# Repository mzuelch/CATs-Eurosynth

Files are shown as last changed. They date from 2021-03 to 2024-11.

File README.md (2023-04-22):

<h1>CAT's Eurosynth</h1>
<p>This is my repository for my analog synth eurorack compatible modules. Files given via the "Gerber" directories are actual production data used for my own prototyping. Bugs are to be expected. Corrections for finished boards marked as "working" are done in KiCAD only.</p>
<p>Please read the "Known Issues" section given in this repository as "ReadMe.md" whenever appropriate.</p>
<h1>License</h1>
<p>Code (AVR projects): GPL3.0.</p>
<p>Code (STM32F projects): MIT license.</p>
<p>Hardware: CC BY-NC-SA 4.0</p>

<p>unless specified otherwise.</p>
<h2>Custom Libraries</h2>
<p>Most of the schematics and layouts use custom libraries since some of the stock libries are either buggy or unsuited for my designs. The libraries can be found <a href="https://github.com/mzuelch/CATs-Eurosynth/tree/main/Libraries">here</a>.</p>
<p>I am about to remodel all the KiCAD Files to use environment variables:</p>
<table>
	<tr>
		<th>Variable</th>
		<th>points to</th>		
	</tr>
	<tr>
		<td>KI_CUSTOM_MOD</td>
		<td>Footprint Data (where all the .pretty stuff is hidden)</td>		
	</tr>
	<tr>
		<td>KI_CUSTOM_3DMOD</td>
		<td>3D Model Data (where all the .3dshapes stuff is hidden)</td>		
	</tr>
	<tr>
		<td>KI_CUSTOM_SYMBOLS</td>
		<td>Symbol Data (where all the .lib stuff is hidden)</td>		
	</tr>
</table>
<p>Layout specific data (mainly front panel stuff) are stored in the corresponding folders. Most of the Links are absolute atm. I will change them as soon as the particular layout is modified.</p>
<p>Proper Aliases and other informations are given in these ReadMe's:</p> 
<ul>
	<li><a href="https://github.com/mzuelch/CATs-Eurosynth/blob/main/Libraries/Symbols/ReadMe.md">Symbols</a></li>
	<li><a href="https://github.com/mzuelch/CATs-Eurosynth/blob/main/Libraries/Footprints/ReadMe.md">Footprints</a></li>
	<li><a href="https://github.com/mzuelch/CATs-Eurosynth/blob/main/Libraries/3D%20Shapes/ReadMe.md">3D Shapes</a></li>
</ul>
<h1>Published Designs</p>
<h2>Standard Line</h2>
<p>Collection of modules with no regard to size. These designs are based on either my own ideas and mistakes or published in so many places I can't figure out the original source.</p>
<h3><a href="https://github.com/mzuelch/CATs-Eurosynth/tree/main/Modules/Standard%20Line/Power%20Module">Power Module (THT, Working)</a></h3>
<h3><a href="https://github.com/mzuelch/CATs-Eurosynth/tree/main/Modules/Standard%20Line/Atari%20Punk%20Console">Atari Punk Console (THT, Working)</a></h3>
<h3><s>Baby8 Sequencer (THT, Rework)</s></h3>
<h3><a href="https://github.com/mzuelch/CATs-Eurosynth/tree/main/Modules/Standard%20Line/4Ch%20Mixer">4Ch Mixer (SMT, Working)</a></h3>
<h3><a href="https://github.com/mzuelch/CATs-Eurosynth/tree/main/Modules/Standard%20Line/Clock%20Divider">Clock Divider (THT, Working)</a></h3>
<h3><a href="https://github.com/mzuelch/CATs-Eurosynth/tree/main/Modules/Standard%20Line/Abakus">Abakus (SMT/THT, Working)</a></h3>
<h3><s>Manual Gate (THT, Rework)</s></h3>
<h3><a href="https://github.com/mzuelch/CATs-Eurosynth/tree/main/Modules/Standard%20Line/Envelope%20Follower">Envelope Follower (THT, WIP)</a></h3>
<h3><a href="https://github.com/mzuelch/CATs-Eurosynth/tree/main/Modules/Standard%20Line/Vactrol%20VCF">Vactrol VCF (THT, Working)</a></h3>
<h3><a href="https://github.com/mzuelch/CATs-Eurosynth/tree/main/Modules/Standard%20Line/Classic%20ADSR">Classic ADSR (SMT, Working)</a></h3>
<h2>Slim Line</h2>
<p>Slim Modules to cope with the ever increasing lamentations from my bandmates and wife. Also these designs are based on either my own ideas and mistakes or published in so many places I can't figure out the original source.</p>
<h3><a href="https://github.com/mzuelch/CATs-Eurosynth/tree/main/Modules/Slim%20Line/Attenuator">Single Attenuator (THT, Working)</a></h3>
<h3><a href="https://github.com/mzuelch/CATs-Eurosynth/tree/main/Modules/Slim%20Line/Buffered%20Multiple">Buffered Multiple (THT, Working)</a></h3>
<h3><a href="https://github.com/mzuelch/CATs-Eurosynth/tree/main/Modules/Slim%20Line/Buffered%20Multiple%20SMD">Buffered Multiple SMD (SMT, Working)</a></h3>
<h3><a href="https://github.com/mzuelch/CATs-Eurosynth/tree/main/Modules/Slim%20Line/Sample%26Hold">Dual Sample&Hold (THT, Working)</a></h3>
<h3><a href="https://github.com/mzuelch/CATs-Eurosynth/tree/main/Modules/Slim%20Line/Sample%26Hold%20SMD">Dual Sample&Hold SMD (SMT/THT, WIP)</a></h3>
<h3><a href="https://github.com/mzuelch/CATs-Eurosynth/tree/main/Modules/Slim%20Line/Precision%20Adder">Precision Adder (SMT, Working)</a></h3>
<h3><a href="https://github.com/mzuelch/CATs-Eurosynth/tree/main/Modules/Slim%20Line/Rectifier%20SMD">Rectifier SMD(SMT, Working)</a></h3>
<h3><a href="https://github.com/mzuelch/CATs-Eurosynth/tree/main/Modules/Slim%20Line/VCA">VCA (THT, Working)</a></h3>
<h3><a href="https://github.com/mzuelch/CATs-Eurosynth/tree/main/Modules/Slim%20Line/Clock%20Divider">Clock Divider (SMT, Working)</a></h3>
<h3><a href="https://github.com/mzuelch/CATs-Eurosynth/tree/main/Modules/Slim%20Line/Voltage%20Controlled%20Switch">Voltage Controlled Switch (SMT, Working)</a></h3>

<h2>Purely Mechanical</h2>
<p>Some purely mechanical projects - blinds, cases,...</p>
<h3><a href="https://github.com/mzuelch/CATs-Eurosynth/tree/main/Modules/Mechanicals/Blinds/1TE">1TE Blind Panel</a></h3>
<h3><a href="https://github.com/mzuelch/CATs-Eurosynth/tree/main/Modules/Mechanicals/Blinds/3TE">3TE Blind Panel</a></h3>
<h3><a href="https://github.com/mzuelch/CATs-Eurosynth/tree/main/Modules/Mechanicals/Cases">Cases</a></h3>

<h2>MFOS Clones</h2>
<p>The basic electronic design was made by <a href="http://musicfromouterspace.com/">Music From Outer Space</a>.
The remodelling in KiCAD, slight adaptation, PCB layout and frontpanel designs are based on my own faults</p>
<p>RIP Ray Wilson</p>
<h3>Dual VCA #2 (THT, Working)</h3>
<ul>
	<li><a href="http://musicfromouterspace.com/analogsynth_new/OLDIESBUTGOODIES/VCA/dualvca-2.html">Original Build Documentation</a></li>
</ul>
<h3><a href="https://github.com/mzuelch/CATs-Eurosynth/tree/main/Modules/MFOS/Noise%20Cornucopia">Noise Cornucopia (THT, Working)</a></h3>
<ul>
	<li><a href="http://musicfromouterspace.com/analogsynth_new/NOISECORNREV01/NOISECORNREV01.php">Original Build Documentation</a></li>
</ul>
<h3><a href="https://github.com/mzuelch/CATs-Eurosynth/tree/main/Modules/MFOS/Eight%20Stage%20Phase%20Shifter">Eight Stage Phase Shifter (SMT, Working)</a></h3>
<ul>
	<li><a href="http://musicfromouterspace.com/analogsynth_new/PHASESHIFTER2007/PHASESHIFTER2007.php">Original Build Documentation</a></li>
</ul>

<h2>YuSynth Clones</h2>
<p>The basic electronic design was made by <a href="https://yusynth.net">YuSynth</a>.
The remodelling in KiCAD, slight adaptation (especially changes to +/-12V), PCB layout and frontpanel designs are based on my own faults.</p>
<h3><a href="https://github.com/mzuelch/CATs-Eurosynth/tree/main/Modules/YuSynth/Improved%20Steiner%20VCF">Improved Steiner VCF (SMT, Working)</a></h3>
<ul>
	<li><a href="http://yusynth.net/Modular/EN/STEINERVCF/index-v2.html">Original Build Documentation</a></li>
</ul>
<h3><a href="https://github.com/mzuelch/CATs-Eurosynth/tree/main/Modules/YuSynth/Balanced%20Modulator"><b>Single</b> balanced Modulator (THT/SMT, WIP)</a></h3>
<ul>
	<li><a href="http://yusynth.net/Modular/EN/RINGMOD/index.html">Original Build Documentation</a></li>
</ul>

<h2>Haraldswerk</h2>
<p>The basic electronic design was made by <a href="https://www.haraldswerk.de/">Haraldswerk</a>.
The remodelling in KiCAD, slight adaptation (especially to Eurorack format), PCB layout and frontpanel designs are based on my own faults.</p>
<h3><a href="https://github.com/mzuelch/CATs-Eurosynth/tree/main/Modules/Haraldswerk/NGF-E%20LFO/">Next Generation Formant LFO (THT, Working)</a></h3>
<ul>
	<li><a href="https://www.haraldswerk.de/NGF_E/NGF_E_LFO/NGF_E_LFO.html">Original Build Documentation</a></li>
</ul>

<h2>Ken Stone / Cat Girl Synth</h2>
<p>The basic electronic design was made by <a href="https://sdiy.info/wiki/CatGirl_Synth">Ken Stone aka Cat Girl Synth</a>.
The remodelling in KiCAD, slight adaptation (especially changes to +/-12V), PCB layout and frontpanel designs are based on my own faults</p>
<h3><a href="https://github.com/mzuelch/CATs-Eurosynth/tree/main/Modules/CGS/Analog%20Switch%20Matrix">Analog Switch Matrix (THT/SMT, Working)</a></h3>
<ul>
	<li><a href="https://sdiy.info/wiki/CGS_analog_switch_matrix">Original Build Documentation</a></li>
</ul>

<h2>HAGIWO</h2>
<p>The basic electronic design was made by <a href="https://www.youtube.com/channel/UCxErrnnVNEAAXPZvQFwobQw">HAGIWO</a>.
The remodelling in KiCAD, slight adaptation in hard- and software, PCB layout and frontpanel designs are based on my own faults.</p>
<p>The schematics are Public Domain, firmware is Open Source unless otherwise specified.</p>
<p>This part of the repository is made public with permission from HAGIWO itself. I really appreciate it.</p>
<h3><a href="https://github.com/mzuelch/CATs-Eurosynth/tree/main/Modules/HAGIWO/6Ch%20Trigger%20Sequencer">6Ch Trigger Sequencer (SMT, Working)</a></h3>
<ul>
	<li>
		<strong>6Ch Gate Sequencer</strong>
		<br><a href="https://www.youtube.com/watch?v=YszdC8YdFl0&t">YouTube</a>
		<br><a href="https://note.com/solder_state/n/n17c69afd484d">Original Build Documentation</a>
	</li>
	<li>
		<strong>6Ch Euclidian Rythm Sequencer</strong>
		<br><a href="https://www.youtube.com/watch?v=lkoBfiq6KPY">YouTube</a>
		<br><a href="https://note.com/solder_state/n/n433b32ea6dbc">Original Build Documentation</a>
	</lt>
</ul>
<h3><a href="https://github.com/mzuelch/CATs-Eurosynth/tree/main/Modules/HAGIWO/Ringfolder">Ringfolder (SMT, Working)</a></h3>
<ul>
	<li>
		<strong>Ring Modulator & Wavefolder</strong>
		<br><a href="https://www.youtube.com/watch?v=gYwEPNSfJLE">YouTube</a>
		<br><a href="https://note.com/solder_state/n/n9d138d74b39d">Original Build Documentation</a>
	</li>
</ul>
<h3><a href="https://github.com/mzuelch/CATs-Eurosynth/tree/main/Modules/HAGIWO/Multiout">Multiout (SMT, Working)</a></h3>
<ul>
	<li>
		<strong>Sequencer Roland SH-101 type</strong>
		<br><a href="https://www.youtube.com/watch?v=--qb_QYZrTk&t">YouTube</a>
		<br><a href="https://note.com/solder_state/n/n80f4baf81226">Original Build Documentation</a>
	</li>
	<li>
		<strong>Dual quantizer and Envelope generator</strong>
		<br><a href="https://www.youtube.com/watch?v=6FJpljEYZq4">YouTube</a>
		<br><a href="https://note.com/solder_state/n/nb8b9a2f212a2">Original Build Documentation</a>
	</li>
</ul>
<h3><a href="https://github.com/mzuelch/CATs-Eurosynth/tree/main/Modules/HAGIWO/Display">Display (SMT, Working)</a></h3>
<ul>
	<li>
		<strong>Oscilloscope & Spectrum analyzer</strong>
		<br><a href="https://www.youtube.com/watch?v=yAes5pS3ZTo">YouTube</a>
		<br><a href="https://note.com/solder_state/n/n6b4cc8d1c6b9">Original Build Documentation</a>
	</li>
</ul>
<h3><a href="https://github.com/mzuelch/CATs-Eurosynth/tree/main/Modules/HAGIWO/Arduino%20VCO">Arduino VCO (SMT, Working)</a></h3>
<ul>
	<li>
		<strong>Additive VCO</strong>
		<br><a href="https://www.youtube.com/watch?v=wjWOJ-h5w5w">YouTube</a>
		<br><a href="https://note.com/solder_state/n/n30b3a8737b1e">Original Build Documentation</a>
	</li>
	<li>
		<strong>Chord VCO</strong>
		<br><a href="https://www.youtube.com/watch?v=Ikhd3OmoN40">YouTube</a>
		<br><a href="https://note.com/solder_state/n/n681d2e07e324">Original Build Documentation</a>
	</li>
	<li>
		<strong>FM VCO</strong>
		<br><a href="https://www.youtube.com/watch?v=NZKacfP9aNI">YouTube</a>
		<br><a href="https://note.com/solder_state/n/n88317851a4c7">Original Build Documentation</a>
	</li>
</ul>
<h3><a href="https://github.com/mzuelch/CATs-Eurosynth/tree/main/Modules/HAGIWO/4Ch%20Sample%20Player">4Ch Sample Player (SMT, Working)</a></h3>
<ul>
	<li>
		<strong>TR-808/909 sample play , 4CH wav trigger</strong>
		<br><a href="https://www.youtube.com/watch?v=7Vcwk8KYZM8&t">YouTube</a>
		<br><a href="https://note.com/solder_state/n/n0209d16d0d08">Original Build Documentation</a>
	</li>
</ul>
<h3><a href="https://github.com/mzuelch/CATs-Eurosynth/tree/main/Modules/HAGIWO/Sync%20LFO">Sync LFO (SMT, Working)</a></h3>
<ul>
	<li>
		<strong>Clock Sync LFO</strong>
		<br><a href="https://www.youtube.com/watch?v=m64jyVz2w3M">YouTube</a>
		<br><a href="https://note.com/solder_state/n/n4c600f2431c3">Original Build Documentation</a>
	</li>
</ul>

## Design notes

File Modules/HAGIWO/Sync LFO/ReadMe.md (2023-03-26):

<h2>Revision History</h2>
<table>
	<tr>
		<th>Revision</th>
		<th>Changes</th>
	</tr>
	<tr>
		<td>012202</td>
		<td>Initial Release</td>
	</tr>
	<tr>
		<td>022303</td>
		<td>Arduino Nano rotated by 180deg. No changes in pot or jack position. PCB layout adapted accordingly.<br>Make space for a shrouded IDC header. Mark the correct header and USB connector orientation on the backside.</td>
	</tr>
</table>

<h2>Modulove Appendix</h2>
This is a PCB version of the awesome HAGIWO Clock SYNC LFO.
It was published on Github by [mzuelch](https://github.com/mzuelch/ "mzuelch") and we (modulove) put together the design & kits in our lab.

HAGIWO Sync LFO Kit

The module is a Arduino-based LFO and can be clocked / synced via the trigger input and offers internal modulation to create complex waveforms.
It can be modified / reprogrammed easily with the Arduino IDE.

HAGIWO Sync LFO module

It offers six waveforms and the following hardware features:

- Panel Design by [bkrsmdesign](https://www.instagram.com/bkrsmdesign/ "Sasha Kruse")
- Knob1: Amplifier control. Set the output voltage
- Knob2: Phase control. Set the phase from 0-360°
- Knob3: Waveform control. Select the waveform type.
- Knob4: Internal modulation, creating complex waveforms.
- CLK in: Clock IN.
- OUTPUT Voltage 0/+10V
- Skiff friendly & 6P
- 50 mA draw

<h1>Changes mzuelch made to the original design</h1>
<ul>
	<li>PWM -> Analog Conversion by active Steiner LPF (fg=500Hz) instead of passive RC network</li>
	<li>Unipolar output changed from 0/+5V to 0/+10V</li>
	<li>Additional bipolar output +/-10V</li>
	<li>Additional inverted bipolar output +/-10V</li>
</ul>

DIY Info:

Building the Module is simple and suited for beginners. The Kit comes with SMD parts already soldered.

Assembly Instructions / Video [here](https://youtube.com/playlist?list=PL9-2_fDMIm5cuEoAXl6-avylgxBkOdHC9 "HAGIWO module build video")

More Info:

- [HAGIWO original Articles](https://note.com/solder_state/n/n4c600f2431c3 "HAGIWO Sync LFO module article").

- [HAGIWO Display Video](https://www.youtube.com/watch?v=m64jyVz2w3M "HAGIWO Clock Sync LFO module Youtube Video").

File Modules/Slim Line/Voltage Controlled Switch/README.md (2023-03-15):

<h1>Slimline Voltage Controlled Switch</h1>
<table>
	<tr valign="top">
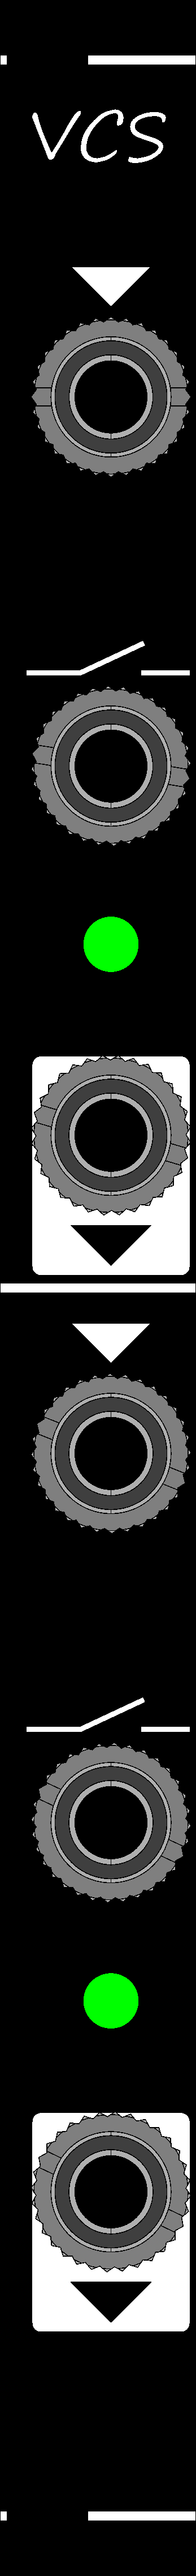
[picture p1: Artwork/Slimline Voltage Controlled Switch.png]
		<td></td>
		<td>
			<p>
				Slimline Voltage Controlled Switch
			</p>
		</td>
	</tr>
</table>

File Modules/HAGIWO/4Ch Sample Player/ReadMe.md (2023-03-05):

<h1>Changes to the original design</h1>
<p>Changed Output stage to provide a eurorack compatible output swing +/-5V</p>
<h1>Changes to the original firmware</h1>
<p>Too many to talk about. Finally got rid of the OLED noise issues by shutting it completely down while in playback mode.</p>

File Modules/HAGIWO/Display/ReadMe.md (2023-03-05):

This is a PCB version of the awesome HAGIWO OLED Display.
It was published on Github by [mzuelch](https://github.com/mzuelch/ "mzuelch") and we (modulove) put together the design & kits in our lab.

HAGIWO OLED Display Kit

The module is a Arduino-based simple Arduino-based OLED DIsplay that has 4 modes.
The microcontroller can be reprogrammed easily with the Arduino IDE and a USB cable.

HAGIWO OLED Display module

Features:

- Pnel Design by modulove
- 128*64 pixel 0.96inch OLED display
- Rotary encoder with PUSH Button
- GAIN attenuator
- AC/DC switching toggle switch
- TRIG IN
- INPUT (normalized)
- OUTPUT
- Voltage 5Vp-p
- LFO / EG mode

1 shot mode
spectrum analyzer mode
whatever you will come up with mode

<h1>Changes mzuelch made to the original HAGIWO design</h1>
<ul>
	<li>R4 (47k) and R5 (10k) were swapped in the original design.</li>
</ul>

DIY Info:

Building the Module is simple and suited for beginners. The Kit comes with all SMD parts already soldered.

Assembly Instructions / Video [here](https://youtube.com/playlist?list=PL9-2_fDMIm5cuEoAXl6-avylgxBkOdHC9 "HAGIWO module build video")

More Info:

- [HAGIWO original Articles](https://note.com/solder_state/n/n6b4cc8d1c6b9 "HAGIWO Display module article").

- [HAGIWO Display Video](https://www.youtube.com/watch?v=yAes5pS3ZTo "HAGIWO Display module Youtube Video").

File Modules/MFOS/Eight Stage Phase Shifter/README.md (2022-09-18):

<h1>MFOS Eight Stage Phase Shifter</h1>
<table>
	<tr valign="top">
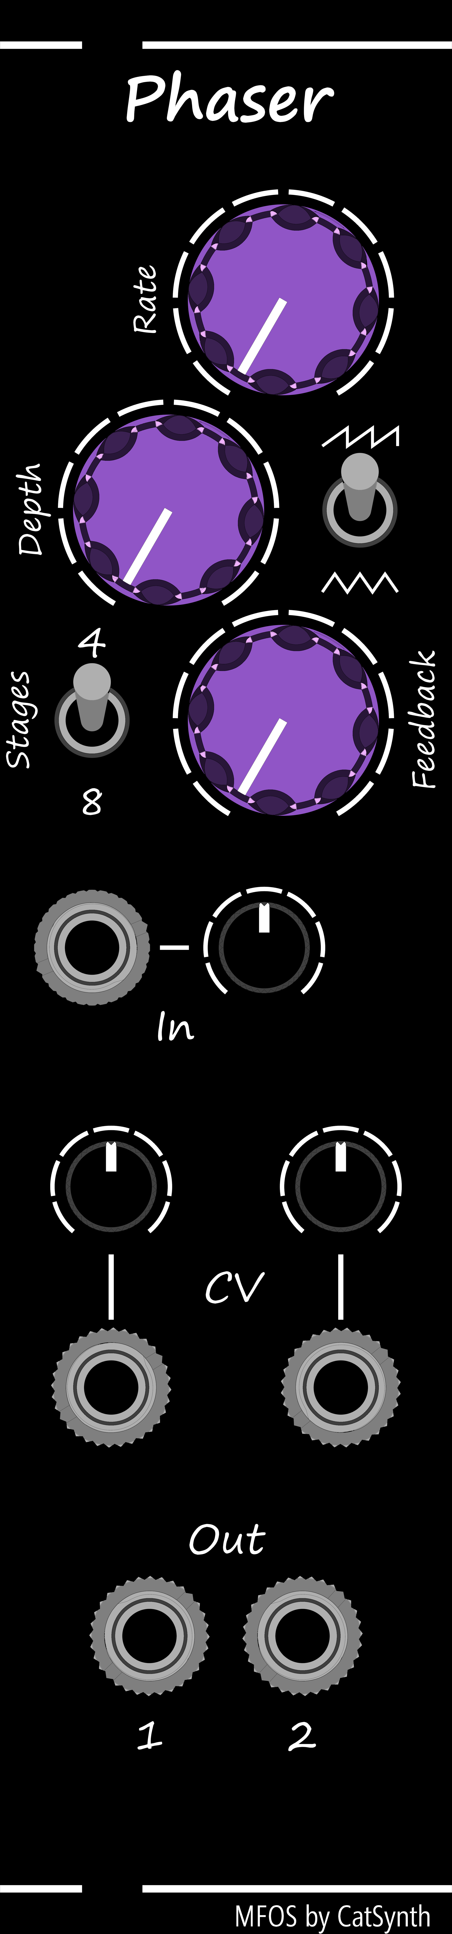
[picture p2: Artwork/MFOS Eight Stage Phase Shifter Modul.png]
		<td></td>
		<td>
			
		</td>
	</tr>
</table>

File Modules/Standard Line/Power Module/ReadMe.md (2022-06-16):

<h1>Power Module</h1>
<table>
	<tr valign="top">
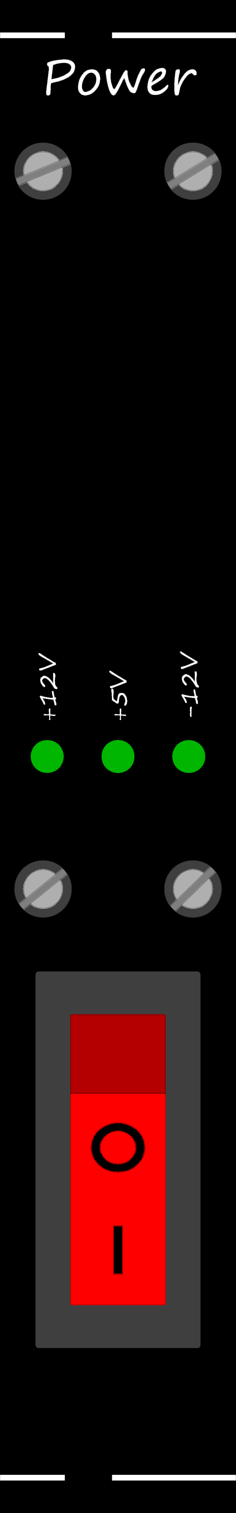
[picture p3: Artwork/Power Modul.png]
		<td></td>
		<td>
			<p>
				Simple Power Input module to provide a mains switch as well as some rudimentary voltage indication.
			</p>
			<p>
				All connections to the <b>fused</b> power connector as well as the PSU (especially Meanwell RT-65B) are <b>isolated</b> 6.3mm (FastOn 250) tab connectors.
			</p>
		</td>
	</tr>
</table>

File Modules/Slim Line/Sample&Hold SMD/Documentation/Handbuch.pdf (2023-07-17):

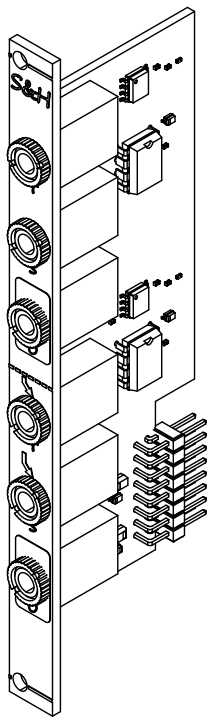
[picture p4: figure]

# CATs EuroSynth

Dr. Michael Zülch
cats.synth@gmx.de

# Dual Sample&Hold

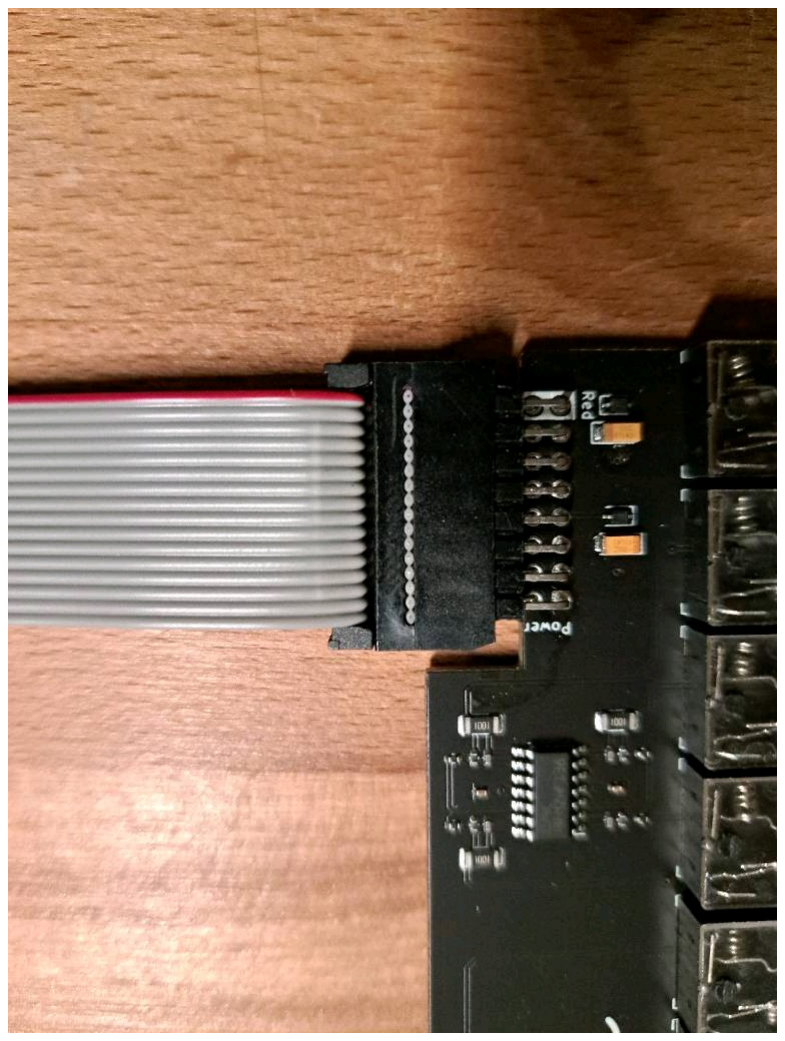
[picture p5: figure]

2 HP Width

39mm w/o Connector

+12V: 15mA

-12V: 15mA

Maximum Depth

Current Draw

## cations fi Technical Speci

## Function

This module contains two identical sample & hold circuits, designed to produce 'staircase' voltages. The signal present at the sample input (S) is sampled at a rate set by the signal at the trigger input (T), and held at that voltage at the S&H output (O). The exact shape of the staircase depends on the sort of waveform at the sample input: NOISE or RANDOM signals produce random patterns; an LFO produces rising or falling

staircase patterns.

The sample input as well as the trigger input of the lower circuit is normalized to the according inputs of

the upper circuit.

## Installation

When installing or removing a module from your case always turn the power to the case and ffo disconnect the power cable. Failure to do so may result in serious injury

or equipment damage.

Ensure the 10-pin connector on the power cable is connected correctly to the module before proceeding.

The red stripe on the cable must line up with the -12V pins on the module’s power connector. The pins are indicated with the label

-12V, a white stripe next to the connector, the words “red”, or

some combination of those

indicators.

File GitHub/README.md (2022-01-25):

<h1>PNG as IMG</h1>
<table border="0" cellpadding="0">
	<tr>
		<td>Atari Punk Console</td>
		<td>4Ch Mixer Front</td>
	</tr>
</table>

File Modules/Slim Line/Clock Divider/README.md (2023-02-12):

<h1>Slimline Clock Divider</h1>
<table>
	<tr valign="top">
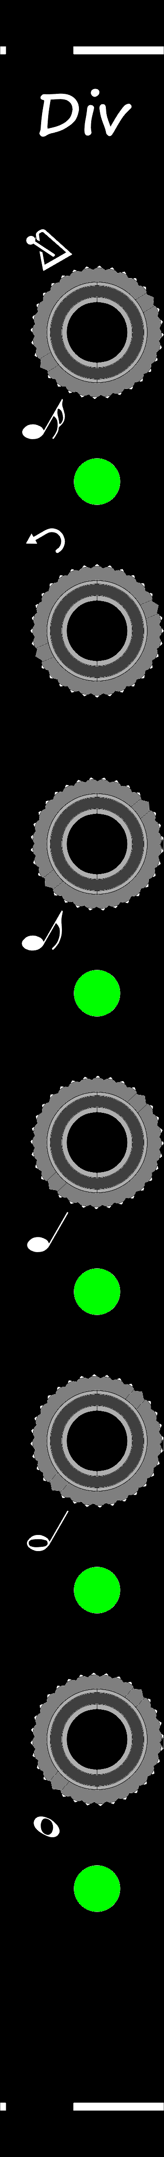
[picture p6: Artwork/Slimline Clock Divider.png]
		<td></td>
		<td>
			<p>
				Slimline Clock Divider
			</p>
		</td>
	</tr>
</table>

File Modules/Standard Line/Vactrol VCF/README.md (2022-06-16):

<h1>Vactrol VCF</h1>
<table>
	<tr valign="top">
		<td></td>
		<td>
		</td>
	</tr>
</table>

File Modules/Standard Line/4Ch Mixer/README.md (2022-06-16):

<h1>4Ch Mixer</h1>
<table>
	<tr valign="top">
		<td></td>
		<td>
			
		</td>
	</tr>
</table>

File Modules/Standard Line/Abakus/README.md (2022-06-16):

<h1>Abakus</h1>
<table>
	<tr valign="top">
		<td></td>
		<td>
			
		</td>
	</tr>
</table>

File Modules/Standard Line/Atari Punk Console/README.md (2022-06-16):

<h1>Atari Punk Console</h1>
<table>
	<tr valign="top">
		<td></td>
		<td>
			
		</td>
	</tr>
</table>

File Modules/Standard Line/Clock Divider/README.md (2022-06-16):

<h1>Clock Divider</h1>
<table>
	<tr valign="top">
		<td></td>
		<td>
			
		</td>
	</tr>
</table>

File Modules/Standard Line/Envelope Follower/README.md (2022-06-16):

<h1>Envelope Follower</h1>
<table>
	<tr valign="top">
		<td></td>
		<td>
			
		</td>
	</tr>
</table>

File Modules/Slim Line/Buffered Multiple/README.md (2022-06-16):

<h1>Slimline Buffered Multiple</h1>
<table>
	<tr valign="top">
		<td></td>
		<td>
			<p>
				Simple Buffered Multiple 2x 1->3 or 1x 1->6
			</p>
		</td>
	</tr>
</table>

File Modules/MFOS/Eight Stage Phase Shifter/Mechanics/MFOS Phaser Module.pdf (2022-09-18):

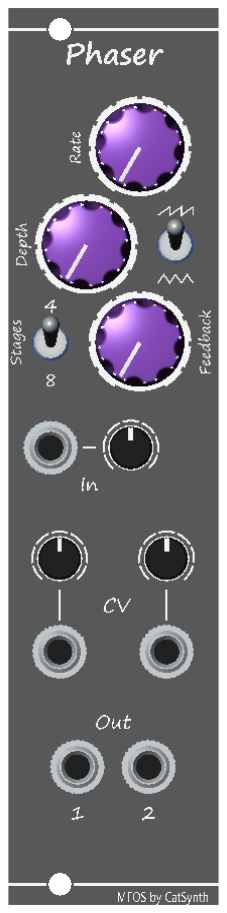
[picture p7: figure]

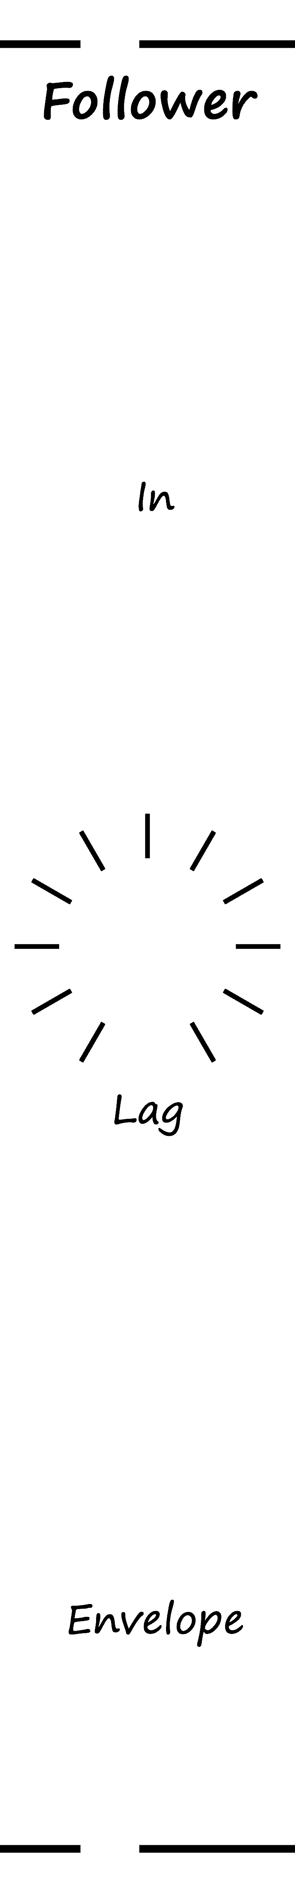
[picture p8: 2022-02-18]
Modules/Standard Line/Envelope Follower/Electronics/Front/Envelope Follower Front.png

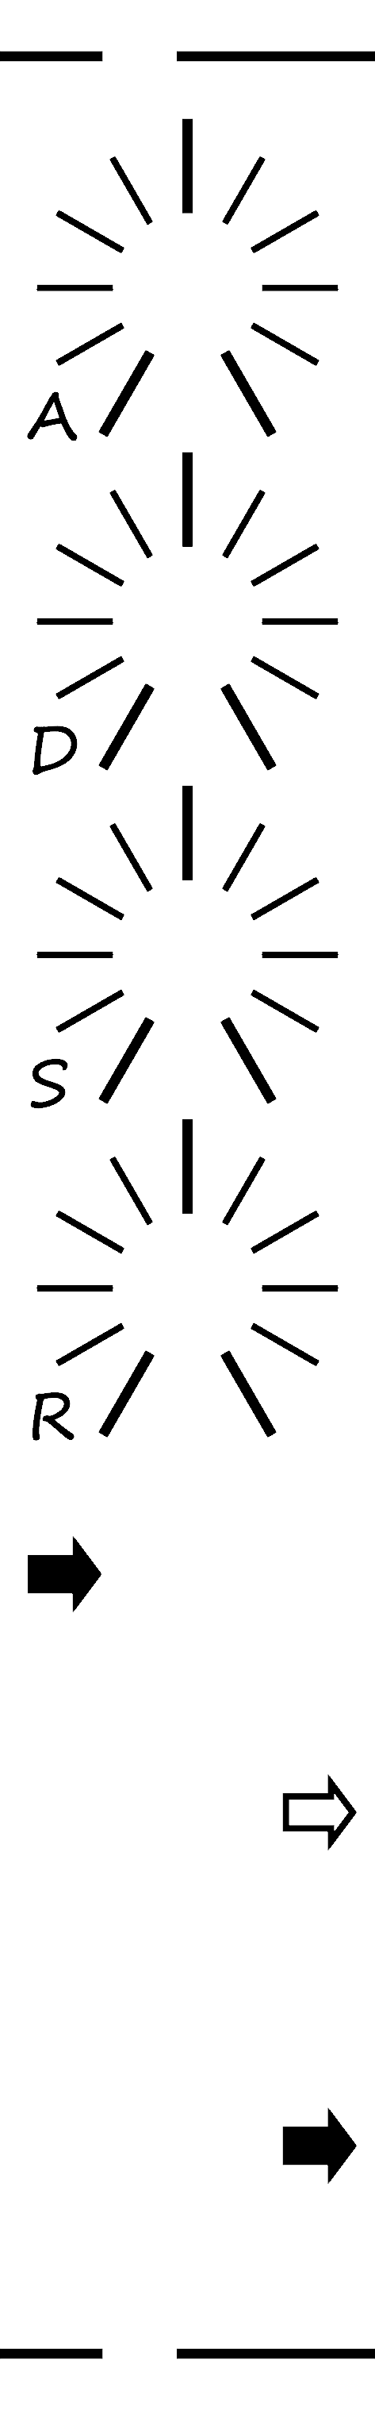
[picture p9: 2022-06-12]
Modules/Standard Line/Classic ADSR/Electronics/Front/Classic ADSR Front.png

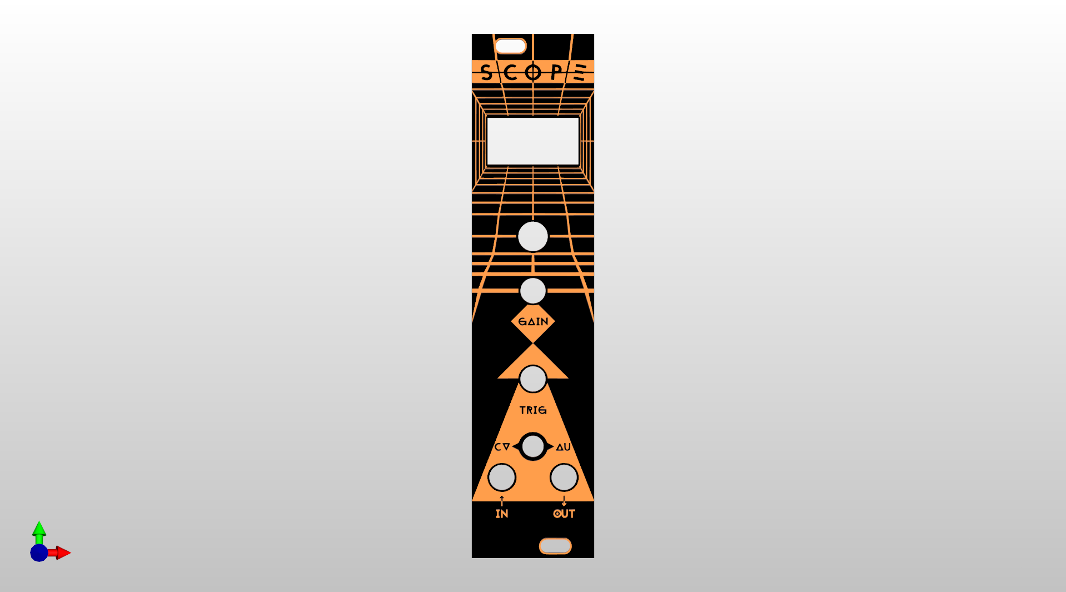
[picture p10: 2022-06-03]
Modules/HAGIWO/Display/Electronics/Front by modulove/SCOPE-Panel.png

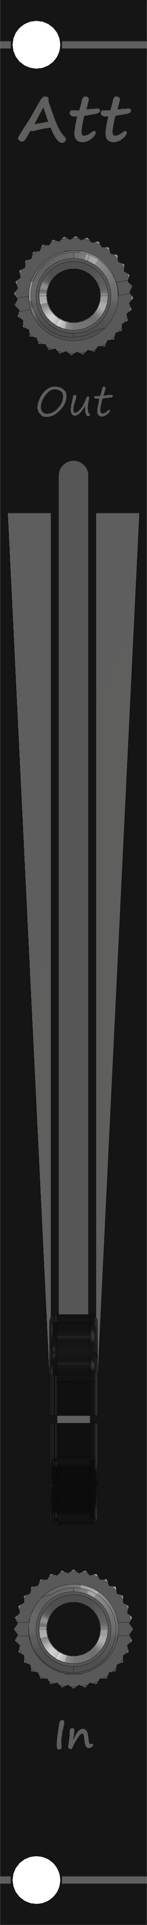
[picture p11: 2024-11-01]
Modules/Slim Line/Single Attenuator/Mechanics/Single Attenuator HiRes.png

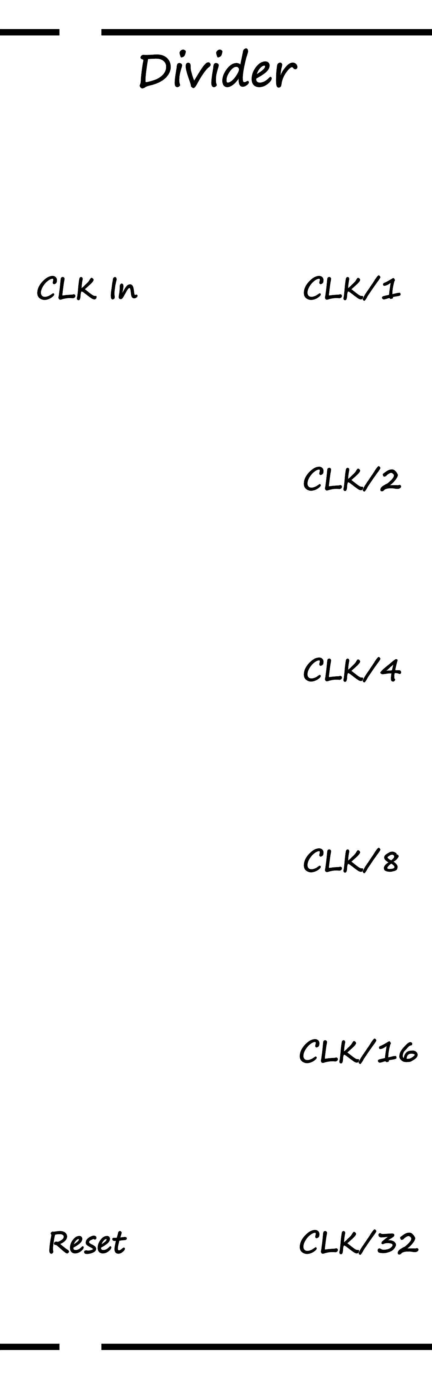
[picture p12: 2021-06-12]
Modules/Standard Line/Clock Divider/Electronics/Front/Clock Divider Frontplatte.png

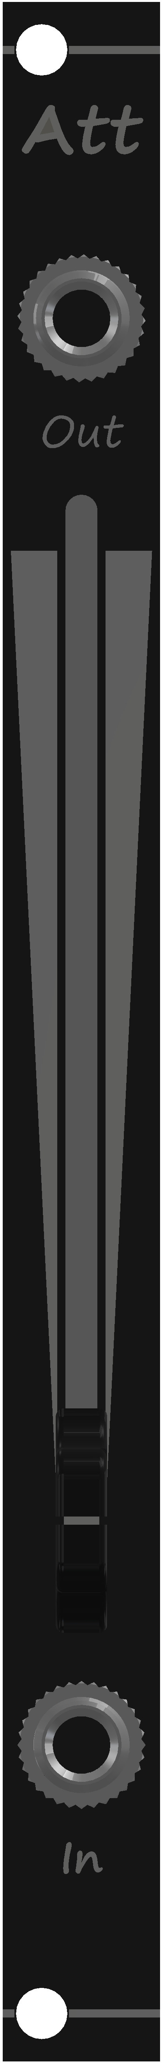
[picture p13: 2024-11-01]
Modules/Slim Line/Single Attenuator/Mechanics/Single Attenuator.JPG

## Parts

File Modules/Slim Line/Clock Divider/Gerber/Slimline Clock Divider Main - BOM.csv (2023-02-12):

Designator | Footprint | Quantity | Value | LCSC Part #
R17 | R_0603_1608Metric | 1 | 1k2 | C22765
R4 | R_0402_1005Metric | 1 | 10k | C25744
R16 | R_0603_1608Metric | 1 | 1k | C21190
C2 | CP_EIA-3216-18_Kemet-A | 1 | 10uF/16V | C7171
R19 | R_0603_1608Metric | 1 | 1k2 | C22765
C4 | C_0402_1005Metric | 1 | 100nF | C1525
IC3 | SOIC-14_3.9x8.7mm_P1.27mm | 1 | CD4069UBM96 | C93672
J1 | Jack_3.5mm_QingPu_WQP-PJ324M | 1 | Clock
D8 | LED_D3.0mm_Horizontal_O3.81mm_Z6.0mm | 1 | LED
R14 | R_0603_1608Metric | 1 | 1k2 | C22765
R10 | R_0402_1005Metric | 1 | 10k | C25744
IC1 | SOIC-8_3.9x4.9mm_P1.27mm | 1 | TL072CDT | C6961
J6 | Jack_3.5mm_QingPu_WQP-PJ324M | 1 | Out_Div_16
Q1 | SOT-23 | 1 | MMBT3904 | C20526
R18 | R_0603_1608Metric | 1 | 1k | C21190
D5 | LED_D3.0mm_Horizontal_O3.81mm_Z6.0mm | 1 | LED
R24 | R_0603_1608Metric | 1 | 1k | C21190
R22 | R_0603_1608Metric | 1 | 1k | C21190
Q3 | SOT-23 | 1 | MMBT3904 | C20526
R23 | R_0603_1608Metric | 1 | 1k | C21190
R7 | R_0603_1608Metric | 1 | 1k2 | C22765
Q2 | SOT-23 | 1 | MMBT3904 | C20526
R15 | R_0402_1005Metric | 1 | 10k | C25744
R8 | R_0603_1608Metric | 1 | 1k | C21190
D3 | D_SOD-323 | 1 | 1N4148WS | C2128
C6 | C_0402_1005Metric | 1 | 100nF | C1525
J4 | Jack_3.5mm_QingPu_WQP-PJ324M | 1 | Reset
R21 | R_0603_1608Metric | 1 | 1k | C21190
C1 | C_0402_1005Metric | 1 | 100nF | C1525
D7 | LED_D3.0mm_Horizontal_O3.81mm_Z6.0mm | 1 | LED
D4 | D_SOD-323 | 1 | 1N5819WS | C191023
D9 | D_SOD-323 | 1 | 1N4148WS | C2128
IC4 | SOIC-14_3.9x8.7mm_P1.27mm | 1 | CD4024BM96 | C157535
C5 | C_0402_1005Metric | 1 | 100nF | C1525
J3 | Jack_3.5mm_QingPu_WQP-PJ324M | 1 | Out_Div_4
R1 | R_0402_1005Metric | 1 | 100k | C25741
R2 | R_0402_1005Metric | 1 | 100k | C25741
Q4 | SOT-23 | 1 | MMBT3904 | C20526
D6 | LED_D3.0mm_Horizontal_O3.81mm_Z6.0mm | 1 | LED
J2 | Jack_3.5mm_QingPu_WQP-PJ324M | 1 | Out_Div_2
R12 | R_0603_1608Metric | 1 | 1k | C21190
J7 | Power_2x8_Horizontal | 1 | Power_2x5
J5 | Jack_3.5mm_QingPu_WQP-PJ324M | 1 | Out_Div_8
D2 | D_SOD-323 | 1 | 1N5819WS | C191023
R5 | R_0402_1005Metric | 1 | 100k | C25741
D1 | LED_D3.0mm_Horizontal_O3.81mm_Z6.0mm | 1 | LED
R20 | R_0603_1608Metric | 1 | 1k | C21190
C3 | CP_EIA-3216-18_Kemet-A | 1 | 10uF/16V | C7171

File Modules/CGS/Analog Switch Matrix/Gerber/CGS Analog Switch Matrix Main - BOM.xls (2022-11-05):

Comment | Designator | Footprint | LCSC
47p | C1,C2,C3,C4,C13,C14,C15,C16,C21,C23 | Capacitor_SMD:C_0402_1005Metric | C1567
10µF | C5,C6,C22 | Capacitor_Tantalum_SMD:CP_EIA-3216-18_Kemet-A | C7171
100n | C7,C8,C9,C10,C11,C12,C17,C18,C19,C20,C24 | Capacitor_SMD:C_0402_1005Metric | C307331
B5817WS | D1,D2 | Diode_SMD:D_SOD-323 | C123899
1N4148 | D3,D4,D5,D6,D7,D8,D9,D10,D11,D12,D13,D14,D15 | Diode_SMD:D_SOD-323 | C2128
Power | J1 | CATs_Eurosynth_Specials:Power_2x5_Vertical
1_COM | J2 | Connector_PinHeader_2.54mm:PinHeader_1x05_P2.54mm_Vertical
2 | J3 | Connector_PinHeader_2.54mm:PinHeader_1x05_P2.54mm_Vertical
3 | J4 | Connector_PinHeader_2.54mm:PinHeader_1x05_P2.54mm_Vertical
4 | J5 | Connector_PinHeader_2.54mm:PinHeader_1x05_P2.54mm_Vertical
POWER | J6 | Connector_PinHeader_2.54mm:PinHeader_1x05_P2.54mm_Vertical
100k | R1,R2,R3,R4,R5,R6,R7,R8,R9,R10,R11,R12,R17,R19,R20,R21,R22,R23,R24,R25,R26,R31,R33,R34 | Resistor_SMD:R_0402_1005Metric | C25741
1k | R13,R14,R15,R16,R35 | Resistor_SMD:R_1206_3216Metric | C4410
10k | R18 | Resistor_SMD:R_0402_1005Metric | C25744
1k | R27,R28,R29,R30 | Resistor_SMD:R_0603_1608Metric | C21190
1k | R32 | Resistor_SMD:R_0402_1005Metric | C11702
CD4066BM/TR | U5 | Package_SO:SOIC-14_3.9x8.7mm_P1.27mm | C512770
TL074IDT | U6 | Package_SO:SOIC-14_3.9x8.7mm_P1.27mm | C107644
TL072CDT | U1,U2,U3,U4,U7 | Package_SO:SOIC-8_3.9x4.9mm_P1.27mm | C6961

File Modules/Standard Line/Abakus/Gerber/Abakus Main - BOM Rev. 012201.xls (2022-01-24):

Comment | Designator | Footprint | LCSC Part Number
10µ | C1 C2 | Capacitor_Tantalum_SMD:CP_EIA-3216-18_Kemet-A | C7171
100n | C3 C4 C5 C6 C7 C8 C9 C10 C11 C12 C13 C14 C15 C16 C17 C18 C19 C20 | Capacitor_SMD:C_0402_1005Metric | C1525
B5817W | D1 D2 | Diode_SMD:D_SOD-123 | C123898
1N4148W | D3 D4 D5 D6 D7 D8 D9 D10 | Diode_SMD:D_SOD-123 | C81598
Power | J1 | Eurorack_Synth:Power_2x5_Vertical
Out | J2 | Connector_PinHeader_2.54mm:PinHeader_2x06_P2.54mm_Vertical
In1 | J3 | Connector_PinHeader_2.54mm:PinHeader_1x04_P2.54mm_Vertical
In2 | J4 | Connector_PinHeader_2.54mm:PinHeader_1x04_P2.54mm_Vertical
In3 | J5 | Connector_PinHeader_2.54mm:PinHeader_1x04_P2.54mm_Vertical
In4 | J6 | Connector_PinHeader_2.54mm:PinHeader_1x04_P2.54mm_Vertical
Sum | J7 | Connector_PinHeader_2.54mm:PinHeader_2x03_P2.54mm_Vertical
MinMax | J8 | Connector_PinHeader_2.54mm:PinHeader_2x05_P2.54mm_Vertical
100k | R1 R2 R3 R4 R7 R8 R9 R10 R11 R12 R13 R14 R21 R22 R23 R24 R27 R29 R30 | Resistor_SMD:R_0402_1005Metric | C25741
1k | R5 R6 R15 R16 R17 R18 R19 R20 R25 R26 R28 R31 R32 R34 R36 R37 R38 | Resistor_SMD:R_0402_1005Metric | C11702
10k | R33 R35 | Resistor_SMD:R_0402_1005Metric | C25744
TL072CDT | U1 U2 U3 U4 U5 | Package_SO:SOIC-8_3.9x4.9mm_P1.27mm | C6961
LM4040AIM3-5.0/NOPB | U10 | Package_TO_SOT_SMD:SOT-23 | C140239
LM4040C10IDBZR | U11 | Package_TO_SOT_SMD:SOT-23 | C201738
TL074CDR | U6 U7 U8 U9 | Package_SO:SOIC-14_3.9x8.7mm_P1.27mm | C12594

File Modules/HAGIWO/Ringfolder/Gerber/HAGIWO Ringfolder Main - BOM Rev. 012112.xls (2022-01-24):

Comment | Designator | Footprint | LCSC
3n3 | C2 | Capacitor_SMD:C_0402_1005Metric | C26404
1µ | C1 C3 | Capacitor_SMD:C_0402_1005Metric | C52923
10µ | C4 C5 | Capacitor_Tantalum_SMD:CP_EIA-3216-18_Kemet-A | C7171
100n | C6 C7 C8 C9 | Capacitor_SMD:C_0402_1005Metric | C1525
1N4148 | D1 D2 D3 | Diode_SMD:D_SOD-123 | C81598
B5817 | D4 D5 | Diode_SMD:D_SOD-123 | C8597
CV | J1 | Connector_Audio_QingPu:Jack_3.5mm_QingPu_WQP-PJ301M-12
In | J2 | Connector_Audio_QingPu:Jack_3.5mm_QingPu_WQP-PJ301M-12
Mod | J3 | Connector_Audio_QingPu:Jack_3.5mm_QingPu_WQP-PJ301M-12
Out | J4 | Connector_Audio_QingPu:Jack_3.5mm_QingPu_WQP-PJ301M-12
Power | J5 | Eurorack_Synth:Power_2x5_Vertical
B50k | P1 | Potentiometer_THT_Additional:Potentiometer_AlpsAlpine_RK09L1240
B100K | P2 | Potentiometer_THT_Additional:Potentiometer_AlpsAlpine_RK09L1140
B50K | P3 | Potentiometer_THT_Additional:Potentiometer_AlpsAlpine_RK09L1140
MMBT3904 | Q1 | Package_TO_SOT_SMD:SOT-23 | C20526
10k | R1 R2 R7 R10 R15 | Resistor_SMD:R_0402_1005Metric | C25744
47k | R14 R17 R19 | Resistor_SMD:R_0402_1005Metric | C25792
4k7 | R18 | Resistor_SMD:R_0402_1005Metric | C25900
100k | R5 R12 R13 R16 R20 | Resistor_SMD:R_0402_1005Metric | C25741
33k | R3 R4 R6 R8 R9 R11 | Resistor_SMD:R_0402_1005Metric | C25779
10k | T1 | Potentiometer_THT:Potentiometer_Runtron_RM-065_Vertical
AD633 | U1 | Package_DIP:DIP-8_W7.62mm_LongPads
TL074 | U2 | Package_SO:SOIC-14_3.9x8.7mm_P1.27mm | C12594

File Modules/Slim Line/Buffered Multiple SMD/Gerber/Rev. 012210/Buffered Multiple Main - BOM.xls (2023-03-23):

Comment | Designator | Footprint | LCSC
10p | C1,C2,C3,C4,C5,C6,C7,C8 | Capacitor_SMD:C_0402_1005Metric | C32949
100n | C10,C11,C13,C14 | Capacitor_SMD:C_0402_1005Metric | C307331
10u/16 | C9,C12 | Capacitor_Tantalum_SMD:CP_EIA-3216-18_Kemet-A | C7171
1N5819WS | D1,D2 | Diode_SMD:D_SOD-323 | C191023
In 1 | J1 | Connector_Audio_QingPu:Jack_3,5mm_QingPu_WQP-PJ324M
In 2 | J2 | Connector_Audio_QingPu:Jack_3,5mm_QingPu_WQP-PJ324M
Out 1-1 | J3 | Connector_Audio_QingPu:Jack_3,5mm_QingPu_WQP-PJ324M
Out 2-1 | J4 | Connector_Audio_QingPu:Jack_3,5mm_QingPu_WQP-PJ324M
Out 1-2 | J5 | Connector_Audio_QingPu:Jack_3,5mm_QingPu_WQP-PJ324M
Out 2-2 | J6 | Connector_Audio_QingPu:Jack_3,5mm_QingPu_WQP-PJ324M
Out 1-3 | J7 | Connector_Audio_QingPu:Jack_3,5mm_QingPu_WQP-PJ324M
Out 2-3 | J8 | Connector_Audio_QingPu:Jack_3,5mm_QingPu_WQP-PJ324M
Power | J9 | CATs_Eurosynth_Specials:Power_2x8_Horizontal
100k | R1,R2,R3,R4,R5,R6,R7,R8,R11,R12,R13,R14,R17,R18,R19,R20 | Resistor_SMD:R_0402_1005Metric | C25741
1k | R9,R10,R15,R16,R21,R22 | Resistor_SMD:R_1206_3216Metric | C4410
TL084IDR | U1,U2 | Package_SO:SOIC-14_3,9x8,7mm_P1,27mm | C12601

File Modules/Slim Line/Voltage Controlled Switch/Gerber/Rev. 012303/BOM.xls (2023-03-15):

Comment | Designator | Footprint | LCSC
47p | C1 C2 C3 C4 | Capacitor_SMD:C_0402_1005Metric | C1567
10uF | C5 C10 C12 | Capacitor_Tantalum_SMD:CP_EIA-3216-18_Kemet-A | C7171
100n | C6 C7 C8 C9 C11 C13 C14 C15 | Capacitor_SMD:C_0402_1005Metric | C307331
1N4148WS | D1 D2 D3 D4 D6 D8 D10 | Diode_SMD:D_SOD-323 | C2128
LED | D5 D7 | LED_THT:LED_D3.0mm_Horizontal_O3.81mm_Z6.0mm
1N5817WS | D9 D11 | Diode_SMD:D_SOD-323 | C727114
IN 1 | J1 | Connector_Audio_QingPu:Jack_3.5mm_QingPu_WQP-PJ324M
OUT 1 | J2 | Connector_Audio_QingPu:Jack_3.5mm_QingPu_WQP-PJ324M
IN 2 | J3 | Connector_Audio_QingPu:Jack_3.5mm_QingPu_WQP-PJ324M
OUT 2 | J4 | Connector_Audio_QingPu:Jack_3.5mm_QingPu_WQP-PJ324M
Switch 1 | J5 | Connector_Audio_QingPu:Jack_3.5mm_QingPu_WQP-PJ324M
Switch 2 | J6 | Connector_Audio_QingPu:Jack_3.5mm_QingPu_WQP-PJ324M
Power | J7 | CATs_Eurosynth_Specials:Power_2x8_Horizontal
MMBT3904 | Q1 Q2 | Package_TO_SOT_SMD:SOT-23 | C20526
1k | R11 R18 | Resistor_SMD:R_0603_1608Metric | C21190
10k | R13 R17 R20 | Resistor_SMD:R_0402_1005Metric | C25744
100k | R1 R2 R3 R4 R6 R7 R8 R9 R12 R14 R15 R16 R21 R22 R23 | Resistor_SMD:R_0402_1005Metric | C25741
1k | R24 | Resistor_SMD:R_0402_1005Metric | C11702
1k | R5 R10 | Resistor_SMD:R_1206_3216Metric | C4410
CD4066BM/TR | U2 | Package_SO:SOIC-14_3.9x8.7mm_P1.27mm | C512770
TL072CDT | U1 U3 U4 | Package_SO:SOIC-8_3.9x4.9mm_P1.27mm | C6961

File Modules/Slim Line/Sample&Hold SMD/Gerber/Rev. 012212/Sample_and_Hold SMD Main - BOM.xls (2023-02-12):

Comment | Designator | Footprint | LCSC
1nF | C1 C2 | Capacitor_SMD:C_0402_1005Metric | C1523
100nF | C3 C8 C9 C10 C11 C12 C13 C14 | Capacitor_SMD:C_0402_1005Metric | C307331
10ÂµF | C4 C5 | Capacitor_Tantalum_SMD:CP_EIA-3216-18_Kemet-A | C7171
10nF | C6 C7 | Capacitor_SMD:C_0402_1005Metric | C15195
1N4148WS | D1 D2 | Diode_SMD:D_SOD-323 | C2128
1N5819WS | D3 D4 | Diode_SMD:D_SOD-323 | C191023
Trigger 2 | J1 | Connector_Audio_PJSeries:PJ-324M-3
In 2 | J2 | Connector_Audio_PJSeries:PJ-324M-3
Trigger 1 | J3 | Connector_Audio_PJSeries:PJ-324M-3
In 1 | J4 | Connector_Audio_PJSeries:PJ-324M-3
Power | J5 | CATs_Eurosynth_Specials:Power_2x8_Horizontal
Out 2 | J6 | Connector_Audio_PJSeries:PJ-324M-3
Out 1 | J7 | Connector_Audio_PJSeries:PJ-324M-3
1k | R13 R14 | Resistor_SMD:R_1206_3216Metric | C4410
100k | R1 R2 R3 R4 R5 R6 R9 R11 R12 | Resistor_SMD:R_0402_1005Metric | C25741
1k | R8 | Resistor_SMD:R_0402_1005Metric | C11702
OP07CDR | U1 U4 | Package_SO:SOIC-8_3.9x4.9mm_P1.27mm | C7433
LF398 | U2 U3 | Package_DIP:DIP-8_W7.62mm_LongPads

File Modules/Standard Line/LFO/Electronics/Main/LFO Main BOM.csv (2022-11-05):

Comment | Designator | Footprint | LCSC
1µF | C1 | Capacitor_SMD:C_0402_1005Metric | C52923
10µF | C10 | Capacitor_SMD:C_0603_1608Metric | C96446
2,2µF | C11 | Capacitor_SMD:C_0805_2012Metric | C49217
10p | C12,C13,C14 | Capacitor_SMD:C_0402_1005Metric | C32949
10µF | C2,C3 | Capacitor_Tantalum_SMD:CP_EIA-3216-18_Kemet-A | C7171
100n | C4,C5,C6,C7,C8,C9 | Capacitor_SMD:C_0402_1005Metric | C307331
LED | D1,D2 | LED_THT:LED_D3,0mm
1N5819WS | D3,D4 | Diode_SMD:D_SOD-323 | C191023
SAW_UP | J1 | Connector_Audio_QingPu:Jack_3,5mm_QingPu_WQP-PJ323M
SAW_DOWN | J2 | Connector_Audio_QingPu:Jack_3,5mm_QingPu_WQP-PJ323M
TRIANGLE | J3 | Connector_Audio_QingPu:Jack_3,5mm_QingPu_WQP-PJ323M
SQUARE | J4 | Connector_Audio_QingPu:Jack_3,5mm_QingPu_WQP-PJ323M
Power | J5 | CATs_Eurosynth_Specials:Power_2x5_Vertical
Select | J6 | Connector_PinHeader_2,54mm:PinHeader_2x03_P2,54mm_Vertical
MMBT3904 | Q1 | Package_TO_SOT_SMD:SOT-23 | C20526
47 | R1 | Resistor_SMD:R_0402_1005Metric | C25118
1k | R12,R15,R16,R17 | Resistor_SMD:R_1206_3216Metric | C4410
2k7 | R18 | Resistor_SMD:R_0603_1608Metric | C13167
68k | R2 | Resistor_SMD:R_0402_1005Metric | C36871
100k | R4,R5,R9,R10,R11,R13,R14,R19,R20 | Resistor_SMD:R_0402_1005Metric | C25741
2k | R6,R7 | Resistor_SMD:R_0402_1005Metric | C4109
47k | R8 | Resistor_SMD:R_0402_1005Metric | C25792
A100k | RV1 | Potentiometer_THT_Additional:Potentiometer_AlpsAlpine_RK0971110
1k | T1 | Potentiometer_SMD:Potentiometer_Bourns_TC33X_Vertical | C719174
TL072 | U1,U2,U3 | Package_SO:SOIC-8_3,9x4,9mm_P1,27mm | C6961

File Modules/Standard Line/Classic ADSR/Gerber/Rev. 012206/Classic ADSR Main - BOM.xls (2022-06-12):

Comment | Designator | Footprint | LCSC
100n | C1 C2 C4 C5 C6 C10 | Capacitor_SMD:C_0805_2012Metric | C49678
10ÂµF | C11 C12 | Capacitor_Tantalum_SMD:CP_EIA-3216-18_Kemet-A | C7171
10n | C3 C7 | Capacitor_SMD:C_0805_2012Metric | C1710
100Âµ | C8 | Capacitor_SMD:CP_Elec_6.3x5.4 | C267461
10Âµ | C9 | Capacitor_SMD:CP_Elec_4x5.4 | C72483
1N5819WS | D1 D2 | Diode_SMD:D_SOD-323 | C191023
1N4148WS | D3 D4 D5 D6 | Diode_SMD:D_SOD-323F | C2128
LED | D7 | LED_THT:LED_D3.0mm_Horizontal_O1.27mm_Z6.0mm
In | J1 | Connector_Audio_QingPu:Jack_3.5mm_QingPu_WQP-PJ323M
Power_2x5 | J2 | CATs_Eurosynth_Specials:Power_2x5_Vertical
ADSR OUT | J3 | Connector_Audio_QingPu:Jack_3.5mm_QingPu_WQP-PJ323M
INV OUT | J4 | Connector_Audio_QingPu:Jack_3.5mm_QingPu_WQP-PJ323M
SLOW/FAST | JP1 JP2 | Connector_PinHeader_2.54mm:PinHeader_1x03_P2.54mm_Vertical
B100K | P1 | Potentiometer_THT_Additional:Potentiometer_AlpsAlpine_RK0971110
A100K | P2 P3 P4 | Potentiometer_THT_Additional:Potentiometer_AlpsAlpine_RK09712200_Solo
MMBT3904 | Q1 | Package_TO_SOT_SMD:SOT-23 | C20526
2N7002 | Q2 | Package_TO_SOT_SMD:SOT-23 | C8545
27k | R1 | Resistor_SMD:R_0805_2012Metric | C17593
120k | R11 | Resistor_SMD:R_0805_2012Metric | C17436
100k | R12 R15 | Resistor_SMD:R_0805_2012Metric | C149504
1k | R13 R14 R16 | Resistor_SMD:R_0805_2012Metric | C17513
10k | R2 | Resistor_SMD:R_0805_2012Metric | C17414
22k | R3 R4 | Resistor_SMD:R_0805_2012Metric | C17560
1M | R5 | Resistor_SMD:R_0805_2012Metric | C17514
4.7k | R6 | Resistor_SMD:R_0805_2012Metric | C17673
100 | R7 R10 | Resistor_SMD:R_0805_2012Metric | C17408
680 | R8 | Resistor_SMD:R_0805_2012Metric | C17798
120 | R9 | Resistor_SMD:R_0805_2012Metric | C17437
20k | T1 | Potentiometer_SMD:Potentiometer_Bourns_TC33X_Vertical | C128550
OP07 | U1 | Package_SO:SOIC-8_3.9x4.9mm_P1.27mm | C7433
TL072 | U2 U3 | Package_SO:SOIC-8_3.9x4.9mm_P1.27mm | C6961
ICM7555xB | U4 | Package_SO:SOP-8_3.9x4.9mm_P1.27mm | C434506

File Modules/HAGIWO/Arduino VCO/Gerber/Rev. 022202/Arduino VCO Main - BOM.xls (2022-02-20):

Comment | Designator | Footprint | LCSC
Arduino_Nano_v3.x | A1 | Module:Arduino_Nano
10Âµ | C1 C11 | Capacitor_Tantalum_SMD:CP_EIA-3216-18_Kemet-A | C7171
100n | C10 C12 | Capacitor_SMD:C_0402_1005Metric | C307331
10n | C2 C3 C4 | Capacitor_SMD:C_0402_1005Metric | C15195
68n | C5 C7 C9 | Capacitor_SMD:C_0603_1608Metric | C31658
3.3n | C6 | Capacitor_SMD:C_0603_1608Metric | C1613
22n | C8 | Capacitor_SMD:C_0402_1005Metric | C1532
B5819W SL | D1 D6 | Diode_SMD:D_SOD-123 | C8598
BAT43 | D2 D3 D4 D5 D8 D9 | Diode_SMD:D_SOD-123 | C19167
Power | J1 | Eurorack_Synth:Power_2x5_Vertical
V/Oct | J2 | Connector_Audio_QingPu:Jack_3.5mm_QingPu_WQP-PJ301M-12
Inv | J3 | Connector_Audio_QingPu:Jack_3.5mm_QingPu_WQP-PJ301M-12
Out | J4 | Connector_Audio_QingPu:Jack_3.5mm_QingPu_WQP-PJ301M-12
Chord | J5 | Connector_Audio_QingPu:Jack_3.5mm_QingPu_WQP-PJ301M-12
B100K | P1 | Potentiometer_THT_Additional:Potentiometer_AlpsAlpine_RK09L1140
B100K | P2 P3 | Potentiometer_THT_Additional:Potentiometer_AlpsAlpine_RK09L1140_oS
1k | R1 R2 R3 R9 R12 R15 | Resistor_SMD:R_0402_1005Metric | C11702
2k7 | R13 | Resistor_SMD:R_0603_1608Metric | C13167
100k | R4 R8 R10 R11 R14 R16 | Resistor_SMD:R_0402_1005Metric | C25741
499k | R5 | Resistor_SMD:R_0402_1005Metric | C25122
3k9 | R6 | Resistor_SMD:R_0402_1005Metric | C51721
7k5 | R7 | Resistor_SMD:R_0402_1005Metric | C25918
TL072CDT | U1 | Package_SO:SO-8_3.9x4.9mm_P1.27mm | C6961

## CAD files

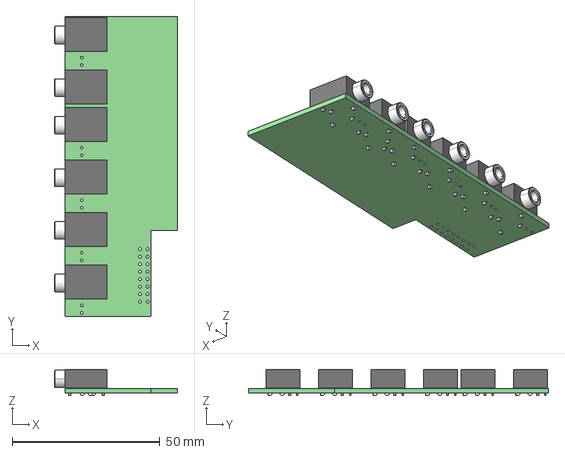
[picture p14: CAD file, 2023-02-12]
Modules/Slim Line/Clock Divider/Mechanics/Slimline Clock Divider SMD Main.step
41.6 x 101.6 x 8.80 mm
Slimline Clock Divider SMD Main PCB

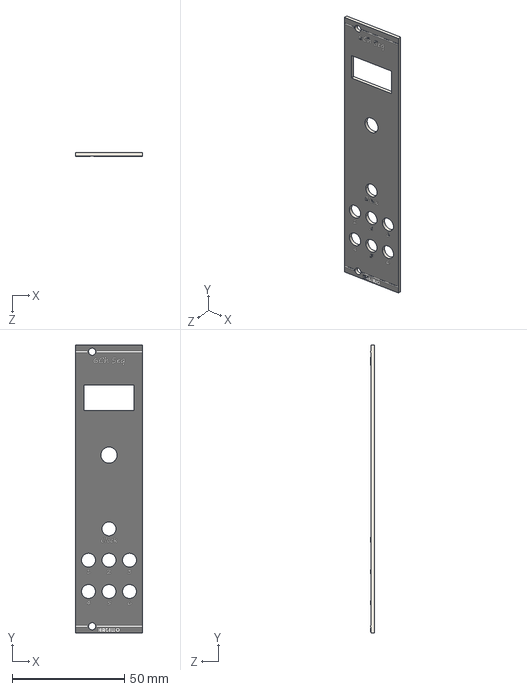
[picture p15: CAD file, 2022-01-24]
Modules/HAGIWO/6Ch Trigger Sequencer/Mechanics/HAGIWO 6Ch Trigger Sequencer Front.STEP
30.0 x 128.5 x 1.70 mm

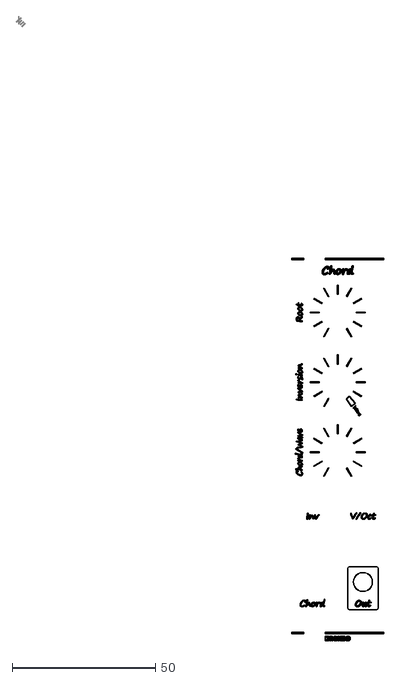
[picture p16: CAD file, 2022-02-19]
Modules/HAGIWO/Arduino VCO/Mechanics/HAGIWO Arduino VCO Chord Front.DXF
128.2 x 218.1

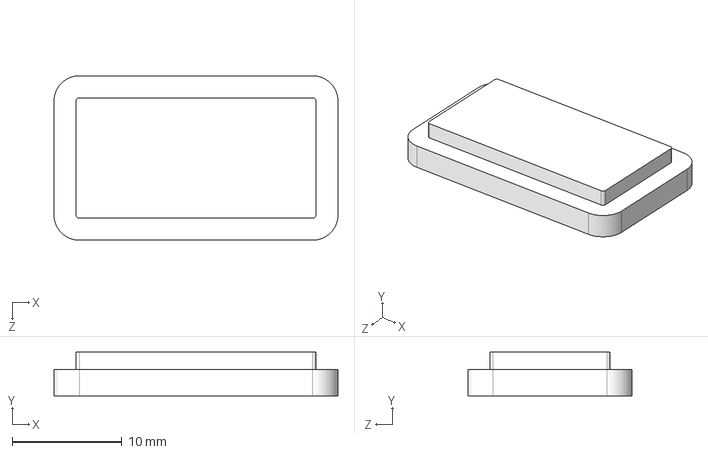
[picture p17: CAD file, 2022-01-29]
Modules/HAGIWO/Display/Mechanics/HAGIWO Display Window.STEP
25.8 x 4.00 x 15.0 mm

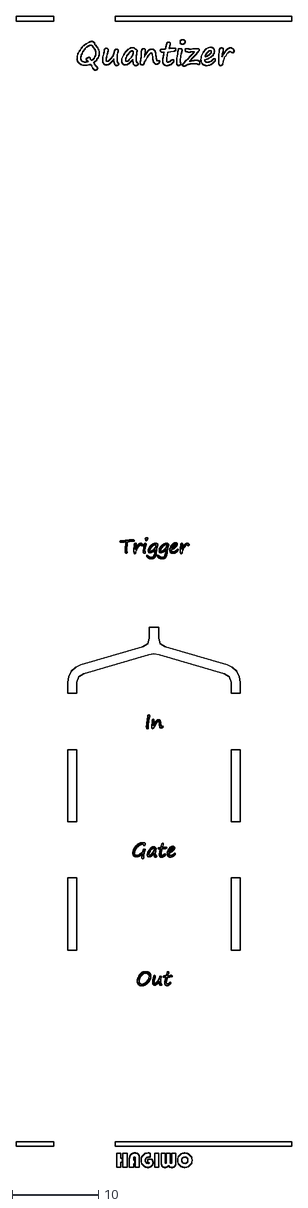
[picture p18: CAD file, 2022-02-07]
Modules/HAGIWO/Multiout/Mechanics/HAGIWO Quantizer Frontpanel.DXF
32.0 x 133.6

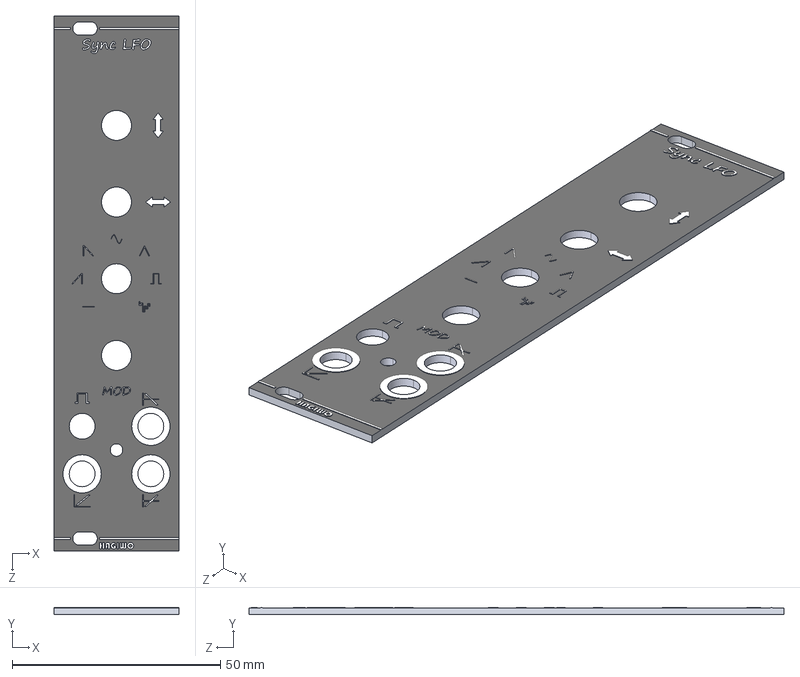
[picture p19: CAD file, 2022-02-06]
Modules/HAGIWO/Sync LFO/Mechanics/HAGIWO Sync LFO Front.STEP
30.0 x 1.70 x 128.5 mm

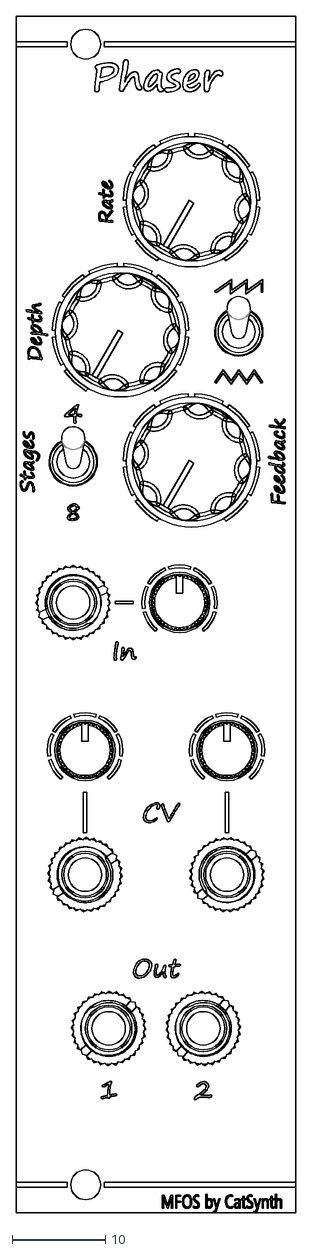
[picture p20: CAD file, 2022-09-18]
Modules/MFOS/Eight Stage Phase Shifter/Mechanics/MFOS Phaser Module.DXF
30.0 x 128.5

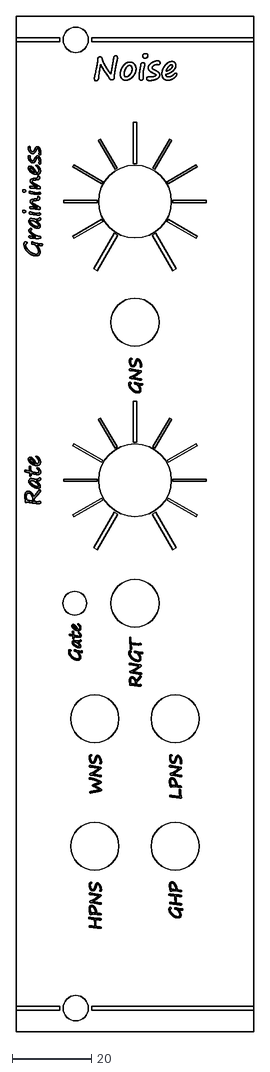
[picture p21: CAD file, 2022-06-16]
Modules/MFOS/Noise Cornucopia/Mechanics/MFOS Noise Cornucopia Front.DXF
60.0 x 257.0

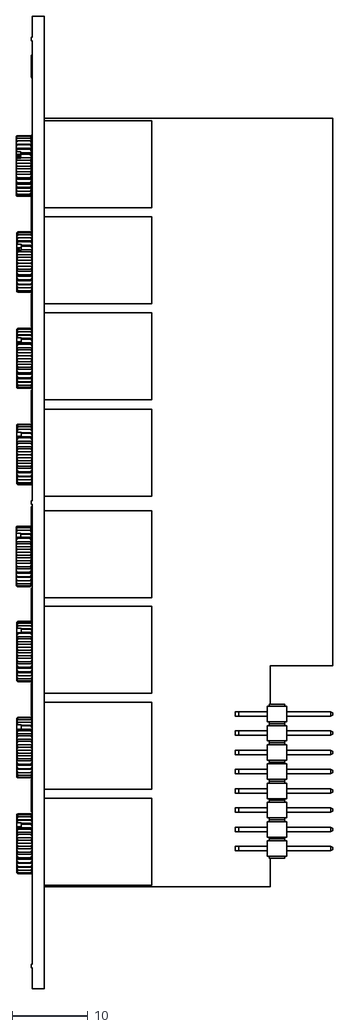
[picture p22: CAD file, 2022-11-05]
Modules/Slim Line/Buffered Multiple SMD/Mechanics/Buffered Multiple Side.DXF
41.8 x 128.5

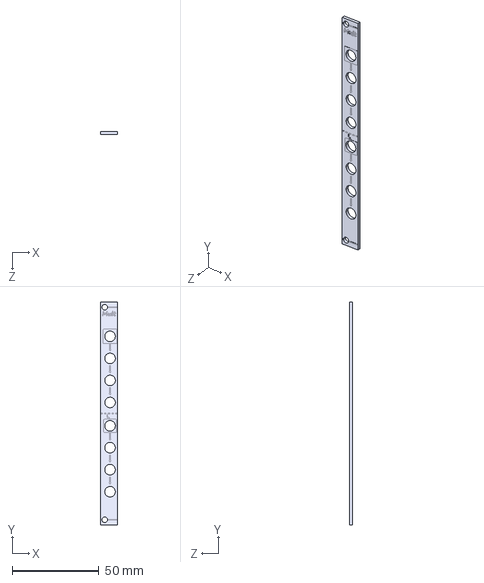
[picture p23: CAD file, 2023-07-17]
Modules/Slim Line/Buffered Multiple/Mechanics/Buffered Multiple Front.STEP
9.80 x 128.5 x 1.70 mm

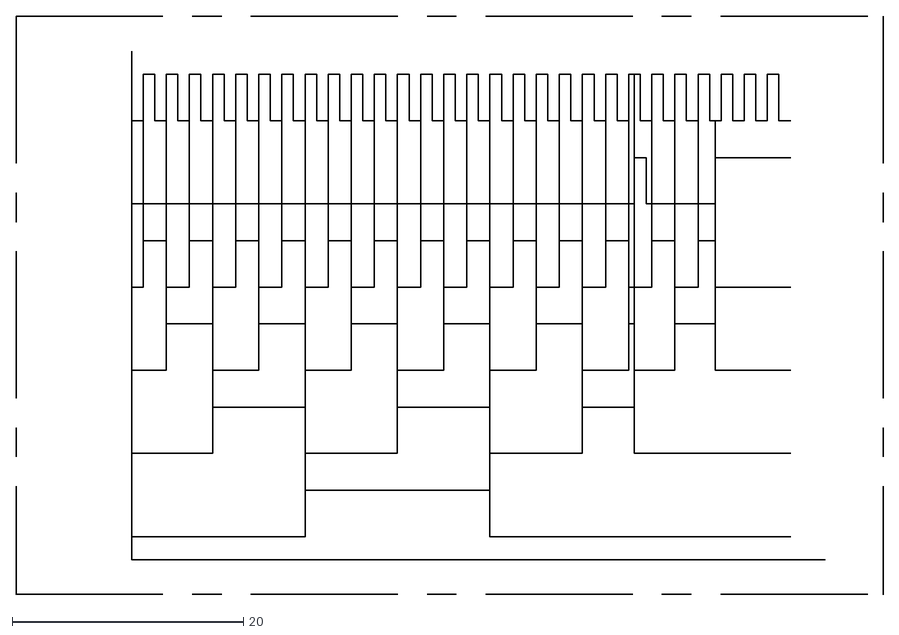
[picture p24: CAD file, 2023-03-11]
Modules/Slim Line/Clock Divider/Documentation/Timing Diagram.DXF
75.0 x 50.0

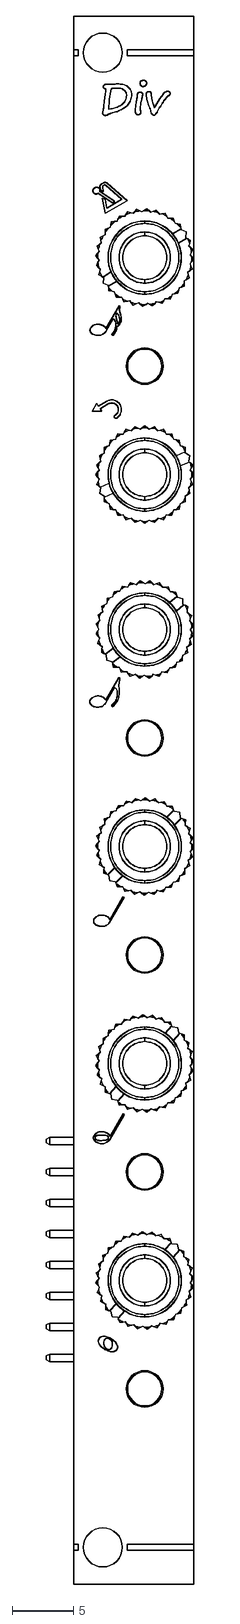
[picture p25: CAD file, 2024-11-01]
Modules/Slim Line/Clock Divider/Mechanics/Slimline Clock Divider Module Front.DXF
12.1 x 128.5

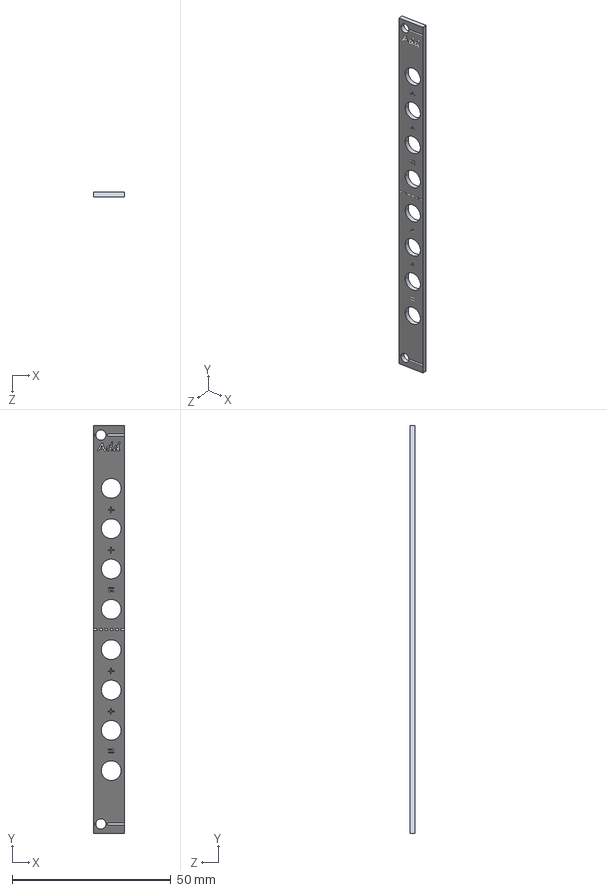
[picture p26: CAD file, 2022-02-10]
Modules/Slim Line/Precision Adder/Mechanics/Slimline Precision Adder Front.STEP
9.80 x 128.5 x 1.70 mm

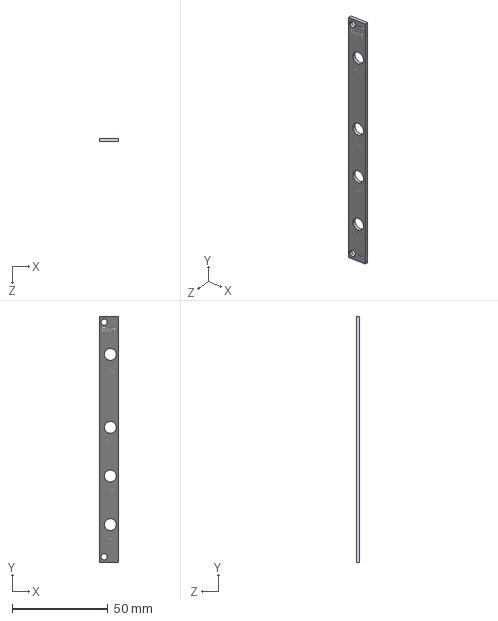
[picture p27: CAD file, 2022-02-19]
Modules/Slim Line/Rectifier SMD/Mechanics/Slimline Rectifier Front.STEP
9.80 x 128.5 x 1.70 mm

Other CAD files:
Modules/Slim Line/Sample&Hold SMD/Mechanics/Sample&Hold Module Front.DXF
Modules/Slim Line/Single Attenuator/Mechanics/Single Attenuator Isometric.DXF
Modules/Slim Line/VCA/Mechanics/Slimline VCA Front.STEP
Modules/Slim Line/Voltage Controlled Switch/Mechanics/Slimline Voltage Controlled Switch Module Front.DXF
Modules/HAGIWO/6Ch Trigger Sequencer/Mechanics/HAGIWO 6Ch Trigger Sequencer Window.STEP
Modules/HAGIWO/Arduino VCO/Mechanics/HAGIWO Arduino VCO 2Op FM Front.DXF
Modules/HAGIWO/Arduino VCO/Mechanics/HAGIWO Arduino VCO Additive Front.DXF
Modules/HAGIWO/Sync LFO/Mechanics/HAGIWO Sync LFO Front.DXF
Modules/MFOS/Eight Stage Phase Shifter/Mechanics/Davies 1900H (violet).stp
Modules/MFOS/Eight Stage Phase Shifter/Mechanics/MFOS Phaser Front.DXF
Modules/Slim Line/Buffered Multiple SMD/Mechanics/Buffered Multiple Front.DXF
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

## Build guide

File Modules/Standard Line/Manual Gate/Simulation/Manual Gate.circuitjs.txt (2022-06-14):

$ 1 0.000005 10.20027730826997 50 5 50 5e-11
s 256 160 256 112 0 1 true
R 256 80 256 64 0 0 40 12 0 0 0.5
w 256 80 256 96 0
w 256 96 288 96 0
w 256 96 256 112 0
w 288 96 288 112 0
c 288 112 288 160 0 1.0000000000000001e-7 11.999999999999975 0.001
w 256 160 256 176 0
w 256 176 288 176 0
w 288 160 288 176 0
w 256 176 256 192 0
r 256 192 256 240 0 1000
g 256 256 256 272 0 0
w 256 256 256 240 0
R 256 320 224 320 0 2 20 4 4 0 0.5
S 400 192 352 192 0 0 false 0 2
w 256 320 288 320 0
w 288 320 288 208 0
w 288 208 352 208 0
w 288 176 352 176 0
w 400 192 416 192 0
w 416 192 416 208 0
w 416 192 432 192 0
r 416 208 416 256 0 1000000
r 432 192 480 192 0 1200000
g 416 272 416 288 0 0
w 416 256 416 272 0
d 496 256 496 208 2 default
w 480 192 496 192 0
w 496 192 496 208 0
g 496 272 496 288 0 0
w 496 256 496 272 0
t 512 192 544 192 0 1 0.4028792456656128 0.5792991303961412 100 default
w 544 208 544 224 0
w 544 224 592 224 0
w 592 224 592 240 0
w 592 224 640 224 0
w 640 224 640 208 0
t 608 192 640 192 0 1 -3.6092110882782196 0.17641988473052844 100 default
w 608 192 592 192 0
w 592 192 592 160 0
w 592 160 544 160 0
w 544 160 544 176 0
w 544 160 544 144 0
w 640 176 640 160 0
w 640 160 656 160 0
w 640 160 640 144 0
r 544 144 544 96 0 22000
r 640 144 640 96 0 22000
R 544 80 544 64 0 0 40 12 0 0 0.5
R 640 80 640 64 0 0 40 12 0 0 0.5
w 544 80 544 96 0
w 640 80 640 96 0
r 592 240 592 288 0 220
g 592 304 592 320 0 0
w 592 304 592 288 0
w 512 192 496 192 0
207 656 160 688 160 4 Ping
207 240 528 208 528 4 Ping
r 256 528 304 528 0 100000
c 320 528 368 528 0 1e-8 3.8946850813848 0.001
r 384 544 384 592 0 220000
t 400 528 432 528 1 1 -11.478527997479286 -0.09755814119453163 100 default
g 384 608 384 624 0 0
w 240 528 256 528 0
w 304 528 320 528 0
w 368 528 384 528 0
w 384 528 384 544 0
w 384 528 400 528 0
w 384 592 384 608 0
t 528 528 496 528 0 1 0.5064221290194784 0.6103742864623551 100 default
w 496 512 496 496 0
w 496 496 528 496 0
r 528 496 576 496 0 220000
w 576 496 608 496 0
w 608 496 608 528 0
w 608 528 688 528 0
w 560 528 592 528 0
w 592 528 592 512 0
w 592 512 624 512 0
w 624 512 624 496 0
w 624 496 656 496 0
r 656 496 704 496 0 220000
t 688 528 720 528 0 1 -11.39844426192748 0.10395467484838904 100 default
w 704 496 720 496 0
w 720 496 720 512 0
w 496 496 496 480 0
w 720 496 720 480 0
r 496 480 496 432 0 10000
r 720 480 720 432 0 10000
R 496 416 496 400 0 0 40 12 0 0 0.5
w 496 416 496 432 0
R 720 416 720 400 0 0 40 12 0 0 0.5
w 720 416 720 432 0
w 496 544 496 560 0
w 496 560 608 560 0
w 720 544 720 560 0
w 608 560 608 576 0
w 608 560 720 560 0
g 608 576 608 592 0 0
w 560 528 528 528 0
w 560 528 560 592 0
c 560 592 560 640 0 1e-8 -10.874547956883271 0.001
r 544 656 496 656 0 10000
w 544 656 560 656 0
w 560 640 560 656 0
w 720 496 752 496 0
w 752 496 752 512 0
r 752 512 752 560 0 220000
w 752 560 752 656 0
w 752 656 560 656 0
w 496 496 432 496 0
w 432 496 432 512 0
w 496 656 432 656 0
w 432 656 432 544 0
207 432 480 432 448 4 /Q
w 432 480 432 496 0
w 752 496 768 496 0
207 768 496 800 496 4 Q
207 880 160 848 160 4 Q
d 928 160 896 160 2 default
w 896 160 880 160 0
w 928 160 944 160 0
w 944 160 944 144 0
r 944 144 944 96 0 22000
R 944 80 944 64 0 0 40 12 0 0 0.5
w 944 80 944 96 0
w 944 160 960 160 0
r 960 160 1008 160 0 4700
r 1024 176 1024 224 0 220000
g 1024 240 1024 256 0 0
t 1040 160 1072 160 0 1 -4.401810221496745 0.6619985683708567 100 default
w 1008 160 1024 160 0
w 1024 160 1024 176 0
w 1024 160 1040 160 0
w 1024 224 1024 240 0
R 1072 128 1072 112 0 0 40 12 0 0 0.5
w 1072 128 1072 144 0
w 1072 176 1072 192 0
162 1072 192 1072 224 2 default-led 1 0 0 0.01
g 1072 320 1072 336 0 0
w 1072 240 1072 256 0
w 1072 304 1072 320 0
w 1072 224 1072 240 0
w 1072 240 1088 240 0
r 1088 240 1136 240 0 1000
207 1152 240 1184 240 4 Q\sOut
w 1136 240 1152 240 0
w 1504 240 1520 240 0
207 1520 240 1552 240 4 /Q\sOut
r 1456 240 1504 240 0 1000
w 1440 240 1456 240 0
w 1440 224 1440 240 0
w 1440 304 1440 320 0
w 1440 240 1440 256 0
g 1440 320 1440 336 0 0
162 1440 192 1440 224 2 default-led 1 0 0 0.01
w 1440 176 1440 192 0
w 1440 128 1440 144 0
R 1440 128 1440 112 0 0 40 12 0 0 0.5
w 1392 224 1392 240 0
w 1392 160 1408 160 0
w 1392 160 1392 176 0
w 1376 160 1392 160 0
t 1408 160 1440 160 0 1 -11.492183352392152 0.24496105601916912 100 default
g 1392 240 1392 256 0 0
r 1392 176 1392 224 0 220000
r 1328 160 1376 160 0 4700
w 1312 160 1328 160 0
w 1312 80 1312 96 0
R 1312 80 1312 64 0 0 40 12 0 0 0.5
r 1312 144 1312 96 0 22000
w 1312 160 1312 144 0
w 1296 160 1312 160 0
w 1264 160 1248 160 0
d 1296 160 1264 160 2 default
207 1248 160 1216 160 4 /Q
w 1872 240 1888 240 0
207 1888 240 1920 240 4 Gate\sOut
r 1824 240 1872 240 0 1000
w 1808 240 1824 240 0
w 1808 224 1808 240 0
w 1808 304 1808 320 0
w 1808 240 1808 256 0
g 1808 320 1808 336 0 0
162 1808 192 1808 224 2 default-led 1 0 0 0.01
w 1808 176 1808 192 0
w 1808 128 1808 144 0
R 1808 128 1808 112 0 0 40 12 0 0 0.5
w 1760 224 1760 240 0
w 1760 160 1776 160 0
w 1760 160 1760 176 0
w 1744 160 1760 160 0
t 1776 160 1808 160 0 1 -7.794456277172381 0.3710217408266332 100 default
g 1760 240 1760 256 0 0
r 1760 176 1760 224 0 220000
r 1696 160 1744 160 0 4700
w 1680 160 1696 160 0
w 1680 80 1680 96 0
R 1680 80 1680 64 0 0 40 12 0 0 0.5
r 1680 144 1680 96 0 22000
w 1680 160 1680 144 0
w 1664 160 1680 160 0
w 1632 160 1616 160 0
d 1664 160 1632 160 2 default
207 1616 160 1584 160 4 Ping
207 1120 528 1088 528 4 Ping
d 1280 496 1248 496 2 default
w 1248 496 1232 496 0
w 1280 496 1296 496 0
w 1296 496 1296 480 0
r 1296 480 1296 432 0 22000
R 1296 416 1296 400 0 0 40 12 0 0 0.5
w 1296 416 1296 432 0
w 1296 496 1312 496 0
r 1312 496 1360 496 0 4700
r 1376 512 1376 560 0 220000
g 1376 576 1376 592 0 0
t 1392 496 1424 496 0 1 -11.561314149082211 0.22914610971182692 100 default
w 1360 496 1376 496 0
w 1376 496 1376 512 0
w 1376 496 1392 496 0
w 1376 560 1376 576 0
R 1424 464 1424 448 0 0 40 12 0 0 0.5
w 1424 464 1424 480 0
w 1424 512 1424 528 0
162 1424 528 1424 560 2 default-led 1 0 0 0.01
g 1424 656 1424 672 0 0
w 1424 576 1424 592 0
w 1424 640 1424 656 0
w 1424 560 1424 576 0
w 1424 576 1440 576 0
r 1440 576 1488 576 0 1000
207 1504 576 1536 576 4 /Gate\sOut
w 1488 576 1504 576 0
r 1136 528 1184 528 0 4700
t 1200 528 1232 528 0 1 0.585393547276681 0.6183884658982027 100 default
w 1232 496 1232 512 0
w 1200 528 1184 528 0
w 1136 528 1120 528 0
w 1232 496 1232 480 0
r 1232 480 1232 432 0 22000
R 1232 416 1232 400 0 0 40 12 0 0 0.5
w 1232 416 1232 432 0
g 1232 560 1232 576 0 0
w 1232 544 1232 560 0
207 1744 528 1712 528 4 Ping
c 1760 528 1808 528 0 1e-9 2.855614858535944 0.001
r 1824 544 1824 592 0 10000
g 1824 608 1824 624 0 0
w 1808 528 1824 528 0
w 1824 528 1824 544 0
w 1824 592 1824 608 0
t 1840 528 1872 528 0 1 -10.951630547929309 0.5759213642208956 100 default
R 1872 496 1872 480 0 0 40 12 0 0 0.5
w 1872 496 1872 512 0
w 1840 528 1824 528 0
w 1872 544 1872 560 0
w 1872 560 1904 560 0
w 1872 560 1872 576 0
r 1872 576 1872 624 0 1000
g 1872 640 1872 656 0 0
w 1872 624 1872 640 0
w 2096 560 2112 560 0
r 2128 560 2176 560 0 4700
g 2192 640 2192 656 0 0
w 2128 560 2112 560 0
w 2176 560 2192 560 0
w 2192 560 2192 576 0
w 2192 624 2192 640 0
w 2304 640 2320 640 0
207 2320 640 2352 640 4 Trigger\sOut
r 2256 640 2304 640 0 1000
w 2240 640 2256 640 0
w 2240 624 2240 640 0
w 2240 704 2240 720 0
w 2240 640 2240 656 0
g 2240 720 2240 736 0 0
162 2240 592 2240 624 2 default-led 1 0 0 0.01
w 2240 576 2240 592 0
w 2240 528 2240 544 0
R 2240 528 2240 512 0 0 40 12 0 0 0.5
t 2208 560 2240 560 0 1 -11.962290164574645 0.025782273949911623 100 default
w 2208 560 2192 560 2
34 zener-5.1 0 1.7143528192810002e-7 0 2 5.1 0
z 1072 304 1072 256 2 zener-5.1
z 1440 304 1440 256 2 zener-5.1
z 1808 304 1808 256 2 zener-5.1
z 1424 640 1424 592 2 zener-5.1
z 2240 704 2240 656 2 zener-5.1
r 2192 576 2192 624 0 220000
w 1952 560 1984 560 0
w 1984 560 2096 560 0
w 1744 528 1760 528 0
w 1824 528 1824 512 0
r 1824 512 1824 464 0 100000
R 1824 448 1824 432 0 0 40 12 0 0 0.5
w 1824 448 1824 464 0
d 1952 560 1904 560 2 default
o 146 64 0 12290 5.318566162784467 0.0001 0 2 146 3
o 149 64 0 12290 5.31856615759807 0.0001 0 2 149 3
o 178 64 0 12290 5.318591731565903 0.0001 0 2 178 3
o 233 64 0 12290 5.318566106584969 0.0001 0 2 233 3
o 271 64 0 12290 5.318711544077814 0.0001 0 2 271 3

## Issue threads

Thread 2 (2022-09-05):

baby8 bom

reaganryl, 2022-09-05:
hi! i got some pcbs made up with your baby8 gerbers. is there a bom? now I see it says 'reworking'- is there an ez fix with these boards? thanks!

mzuelch, 2022-09-18:
Sorry for the late reply - I had some private issues during the last weeks.

The BOM is now included as an iBOM. The reason for the "rework" mark is the trigger input stage (CLK and RESET). Sadly it's quite picky when it comes to recognizing the signal.

reaganryl, 2022-09-20:
Thanks! Hope all is well.

Sent with [Proton Mail](https://proton.me/) secure email.

------- Original Message -------
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

reaganryl, 2023-06-01:
I just put a 100nf cap between the clock jack pin and the board and it's working great now.

Sent with [Proton Mail](https://proton.me/) secure email.

------- Original Message -------
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

Closed 2022-09-18.

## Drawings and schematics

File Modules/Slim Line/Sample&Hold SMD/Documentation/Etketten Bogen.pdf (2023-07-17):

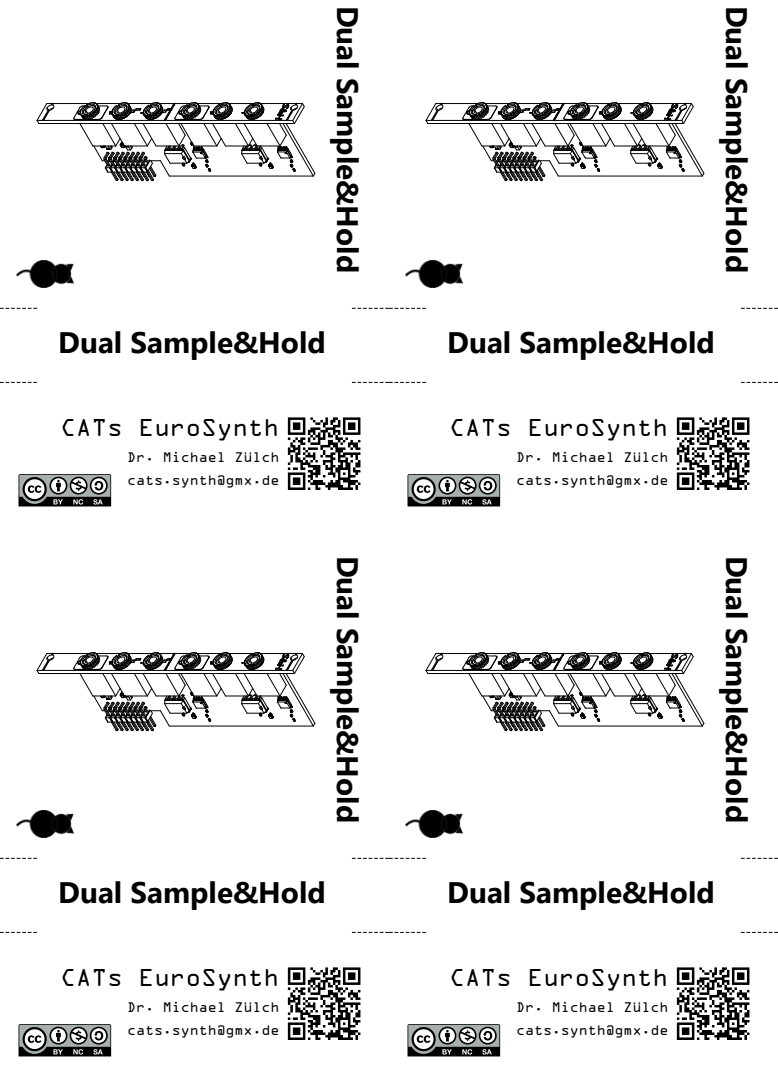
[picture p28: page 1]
CATs EuroSynth

Dual Sample&Hold

Dr. Michael Zülch
cats.synth@gmx.de

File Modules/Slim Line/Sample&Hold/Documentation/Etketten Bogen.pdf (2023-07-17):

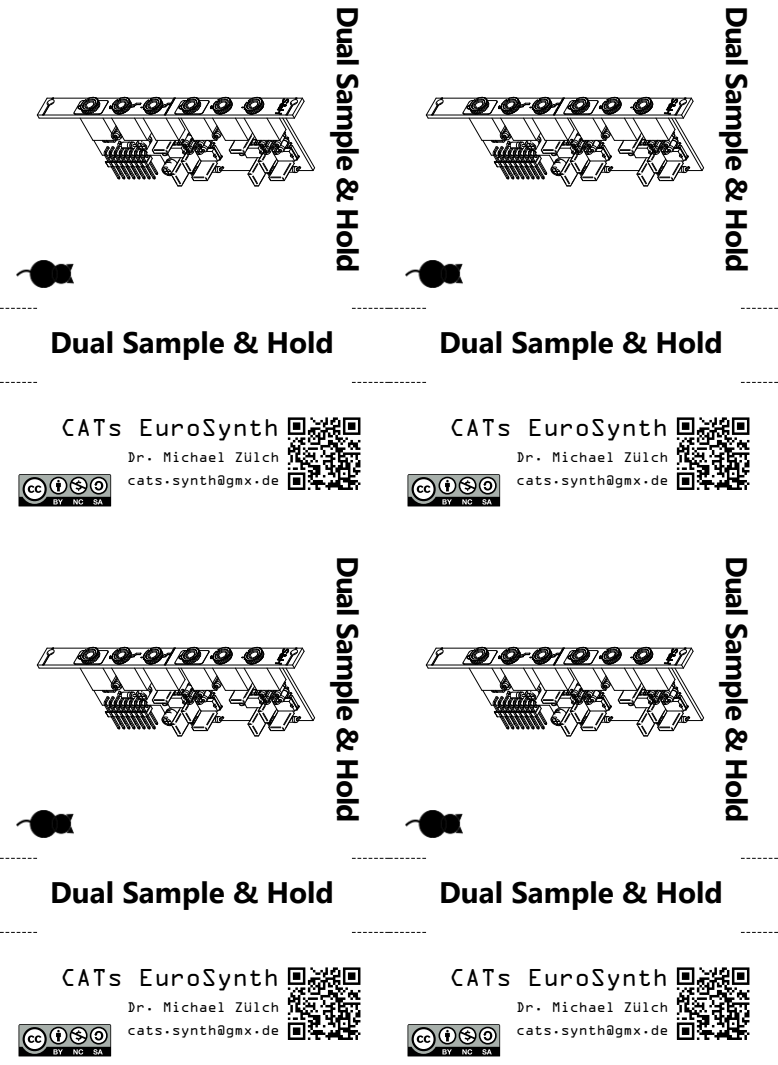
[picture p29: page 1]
CATs EuroSynth

Dual Sample & Hold

Dr. Michael Zülch
cats.synth@gmx.de

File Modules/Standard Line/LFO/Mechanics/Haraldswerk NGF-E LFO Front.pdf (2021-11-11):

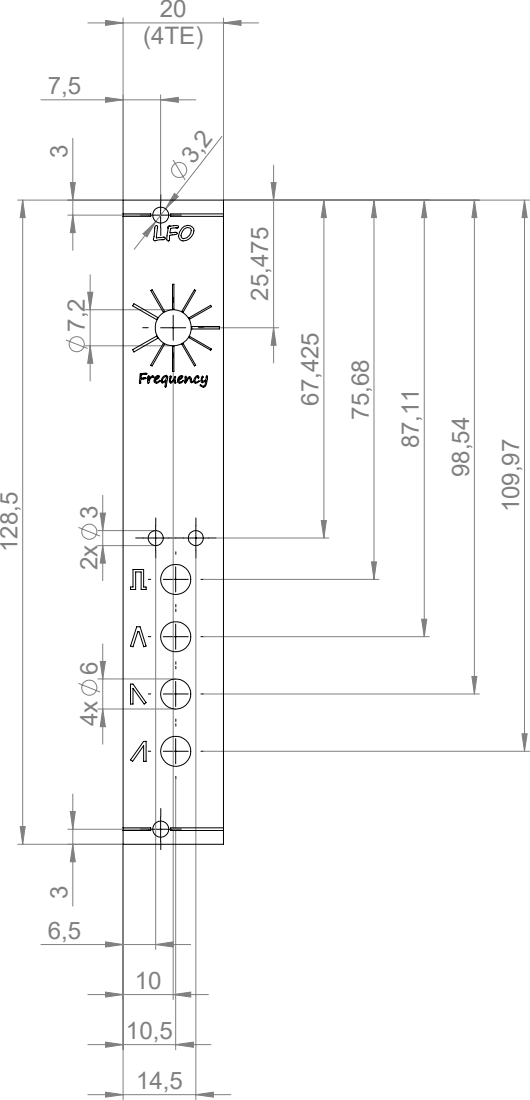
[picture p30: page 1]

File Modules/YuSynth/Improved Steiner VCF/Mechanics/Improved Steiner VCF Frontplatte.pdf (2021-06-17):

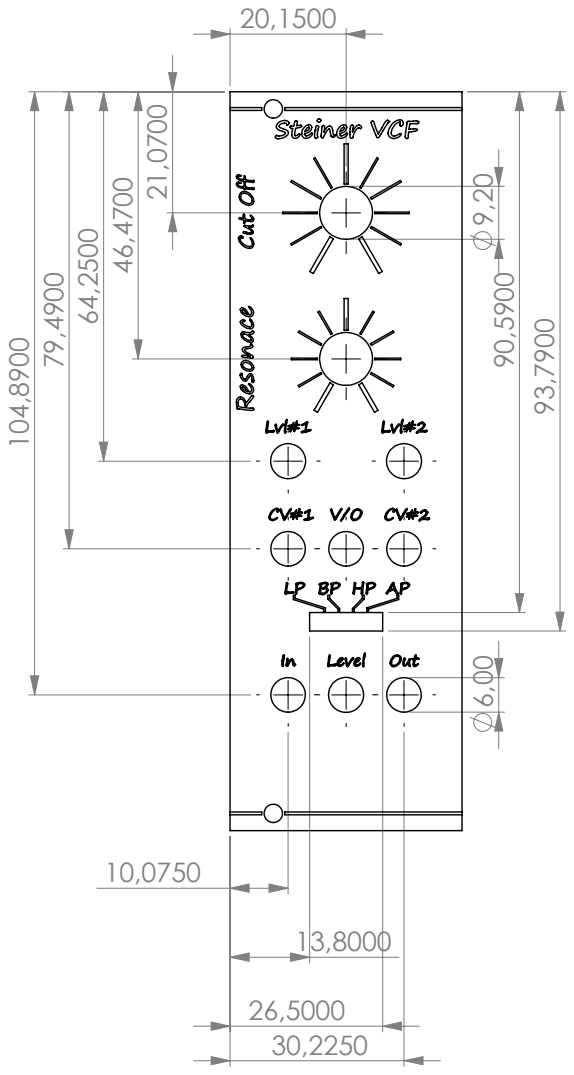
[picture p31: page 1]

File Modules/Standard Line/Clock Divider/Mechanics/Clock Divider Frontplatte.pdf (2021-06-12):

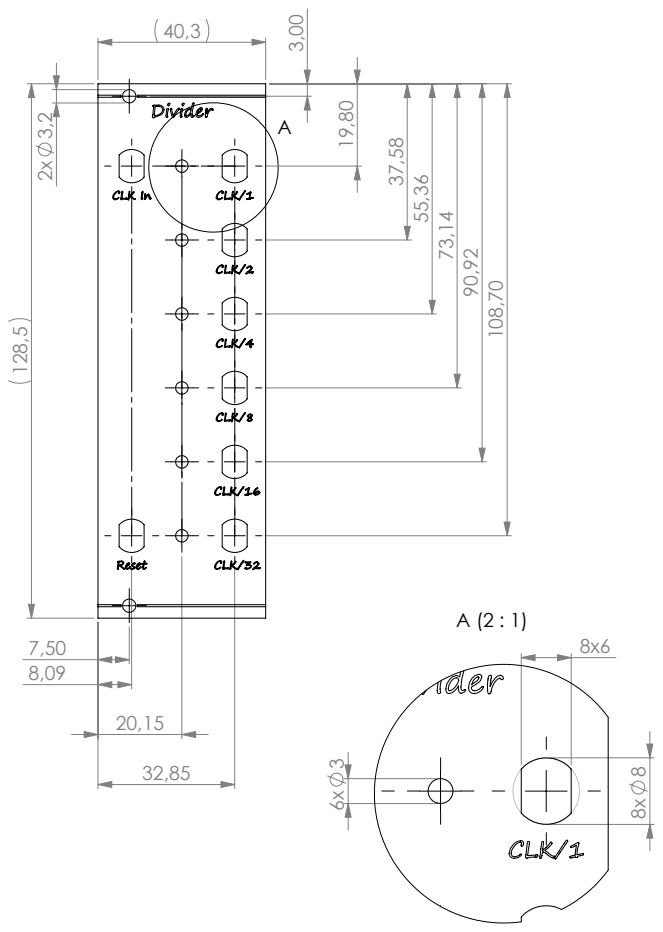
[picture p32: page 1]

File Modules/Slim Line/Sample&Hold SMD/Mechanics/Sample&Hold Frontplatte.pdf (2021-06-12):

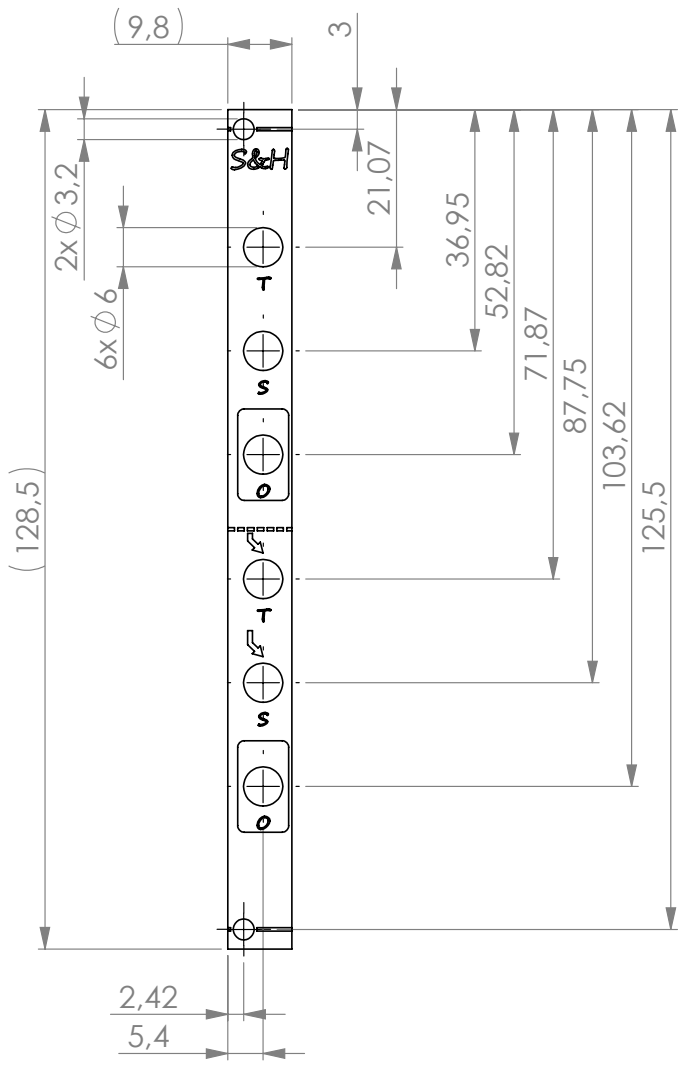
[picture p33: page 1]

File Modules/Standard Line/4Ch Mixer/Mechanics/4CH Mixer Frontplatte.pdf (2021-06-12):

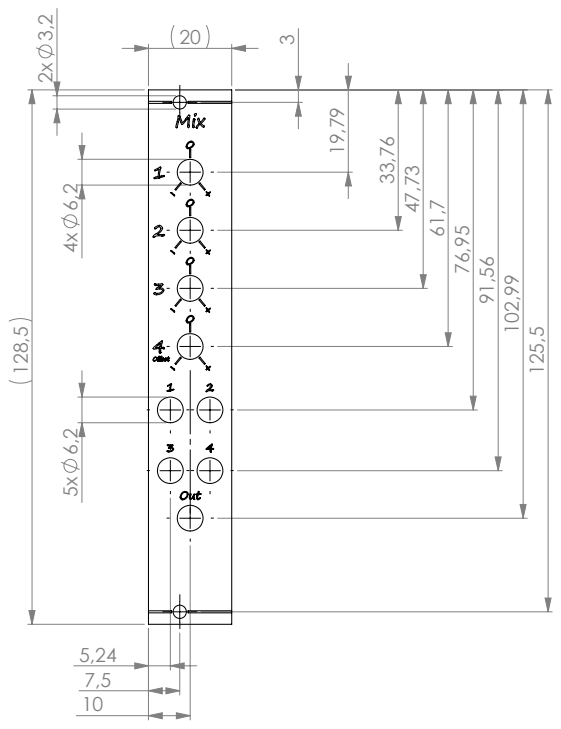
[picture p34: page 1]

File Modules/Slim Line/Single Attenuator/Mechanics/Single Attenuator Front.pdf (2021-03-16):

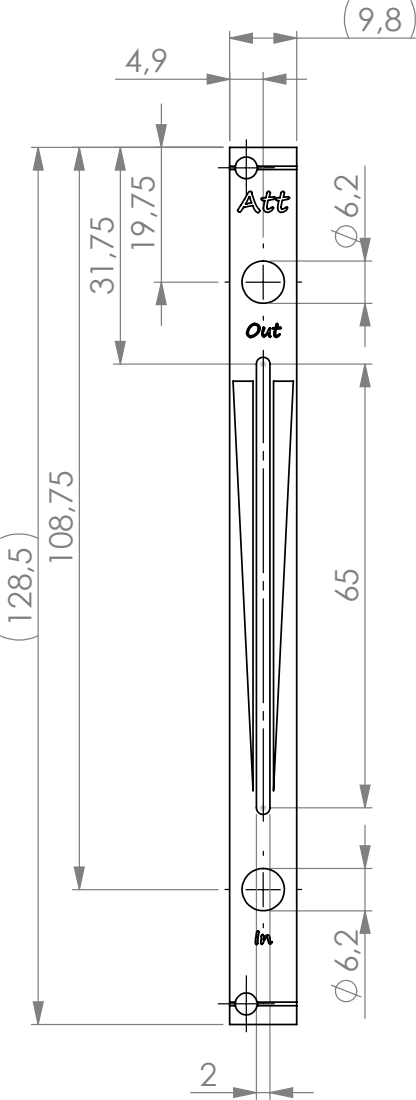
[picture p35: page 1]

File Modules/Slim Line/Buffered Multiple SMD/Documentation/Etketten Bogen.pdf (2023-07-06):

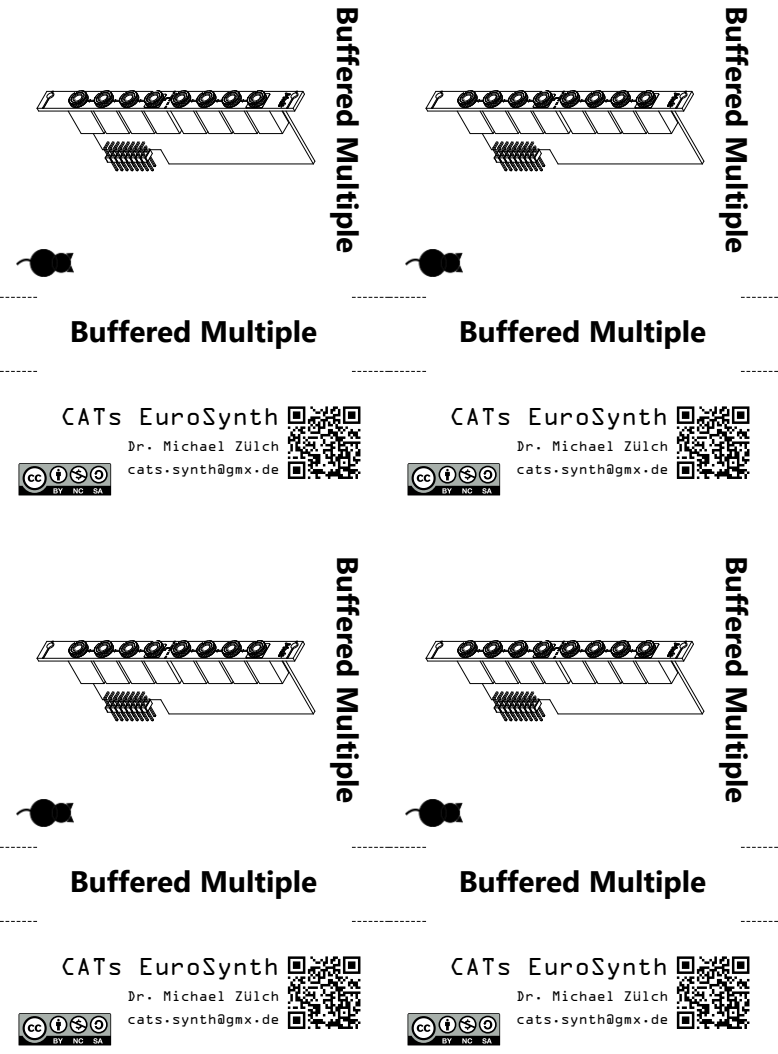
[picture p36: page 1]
Buffered Multiple; CATs EuroSynth

Dr. Michael Zülch
cats.synth@gmx.de

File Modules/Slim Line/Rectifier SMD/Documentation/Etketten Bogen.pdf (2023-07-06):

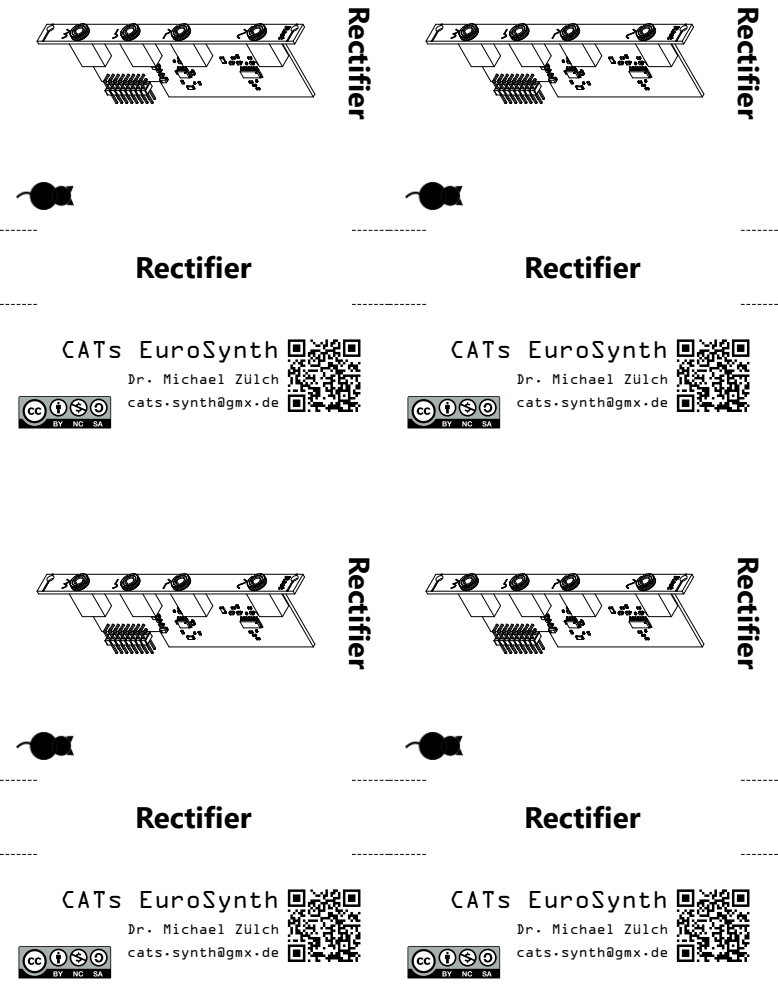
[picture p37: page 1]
Rectifier; CATs EuroSynth

Dr. Michael Zülch
cats.synth@gmx.de

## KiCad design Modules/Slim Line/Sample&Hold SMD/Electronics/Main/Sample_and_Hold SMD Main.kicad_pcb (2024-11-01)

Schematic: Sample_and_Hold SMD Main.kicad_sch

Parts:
C1, C2: 1nF; C_0402_1005Metric; LCSC C1523
C3, C8, C9, C10, C11, C12, C13, C14: 100nF; C_0402_1005Metric; LCSC C307331
C4, C5: 10µF; CP_EIA-3216-18_Kemet-A; LCSC C7171
C6, C7: 10nF; C_0402_1005Metric; LCSC C15195
D1, D2: 1N4148WS; D_SOD-323; LCSC C2128
D3, D4: 1N5819WS; D_SOD-323; LCSC C191023
J1: Trigger 2; PJ-324M-3
J2: In 2; PJ-324M-3
J3: Trigger 1; PJ-324M-3
J4: In 1; PJ-324M-3
J5: Power; Power_2x8_Horizontal
J6: Out 2; PJ-324M-3
J7: Out 1; PJ-324M-3
R1, R2, R3, R4, R5, R6, R9, R11, R12: 100k; R_0402_1005Metric; LCSC C25741
R8: 1k; R_0402_1005Metric; LCSC C11702
R13, R14: 1k; R_1206_3216Metric; LCSC C4410
U1, U4: OP07CDR; SOIC-8_3.9x4.9mm_P1.27mm; LCSC C7433
U2, U3: LF398; DIP-8_W7.62mm_LongPads

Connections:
+12V: C3.1, C4.1, C8.1, C9.1, C10.1, D3.1 (K), R9.1, U1.7 (V+), U2.1 (V+), U3.1 (V+), U4.7 (V+)
-12V: C5.2, C11.2, C12.2, C13.2, C14.2, D4.2 (A), U1.4 (V-), U2.4 (V-), U3.4 (V-), U4.4 (V-)
GND: C3.2, C4.2, C5.1, C6.2, C7.2, C8.2, C9.2, C10.2, C11.1, C12.1, C13.1, C14.1, J1.S, J2.S, J3.S, J3.TN, J4.S, J4.TN, J5.GND, J6.S, J7.S, R1.1, R2.1, R5.1, R6.1, R8.1, R11.1, R12.1, U2.7 (T), U3.7 (T)
unnamed: C1.1, D1.2 (A), R11.2
unnamed: C1.2, U4.6
unnamed: C2.1, D2.2 (A), R12.2
unnamed: C2.2, U1.6
unnamed: C6.1, U2.6 (Ch)
unnamed: C7.1, U3.6 (Ch)
unnamed: D1.1 (K), U2.8 (Hold)
unnamed: D2.1 (K), U3.8 (Hold)
unnamed: D3.2 (A), J5.+12V
unnamed: D4.1 (K), J5.-12V
unnamed: J1.T, R3.1
unnamed: J1.TN, J3.T, R4.1
unnamed: J2.T, R1.2, U2.3 (I)
unnamed: J2.TN, J4.T, R2.2, U3.3 (I)
unnamed: J6.T, R13.1
unnamed: J7.T, R14.1
unnamed: R3.2, R5.2, U4.3 (+)
unnamed: R4.2, R6.2, U1.3 (+)
unnamed: R13.2, U2.5
unnamed: R14.2, U3.5
Vref: R8.2, R9.2, U1.2 (-), U4.2 (-)

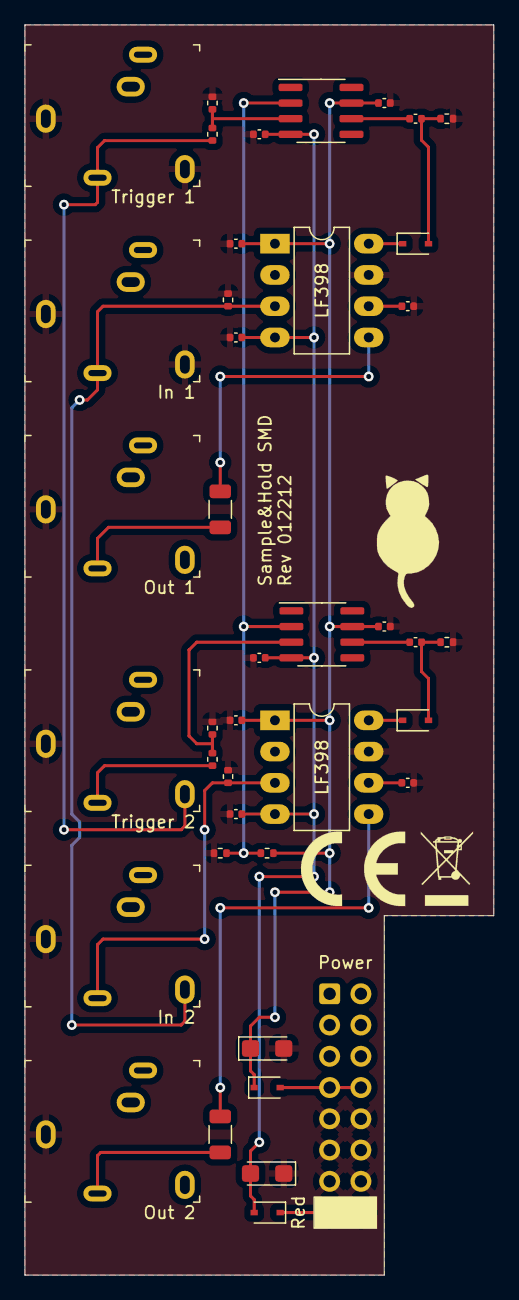
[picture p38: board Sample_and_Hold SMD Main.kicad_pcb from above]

Board: 2 copper layers, 38.1 x 101.6 mm, 41 parts (0 on the bottom side), 24 nets.

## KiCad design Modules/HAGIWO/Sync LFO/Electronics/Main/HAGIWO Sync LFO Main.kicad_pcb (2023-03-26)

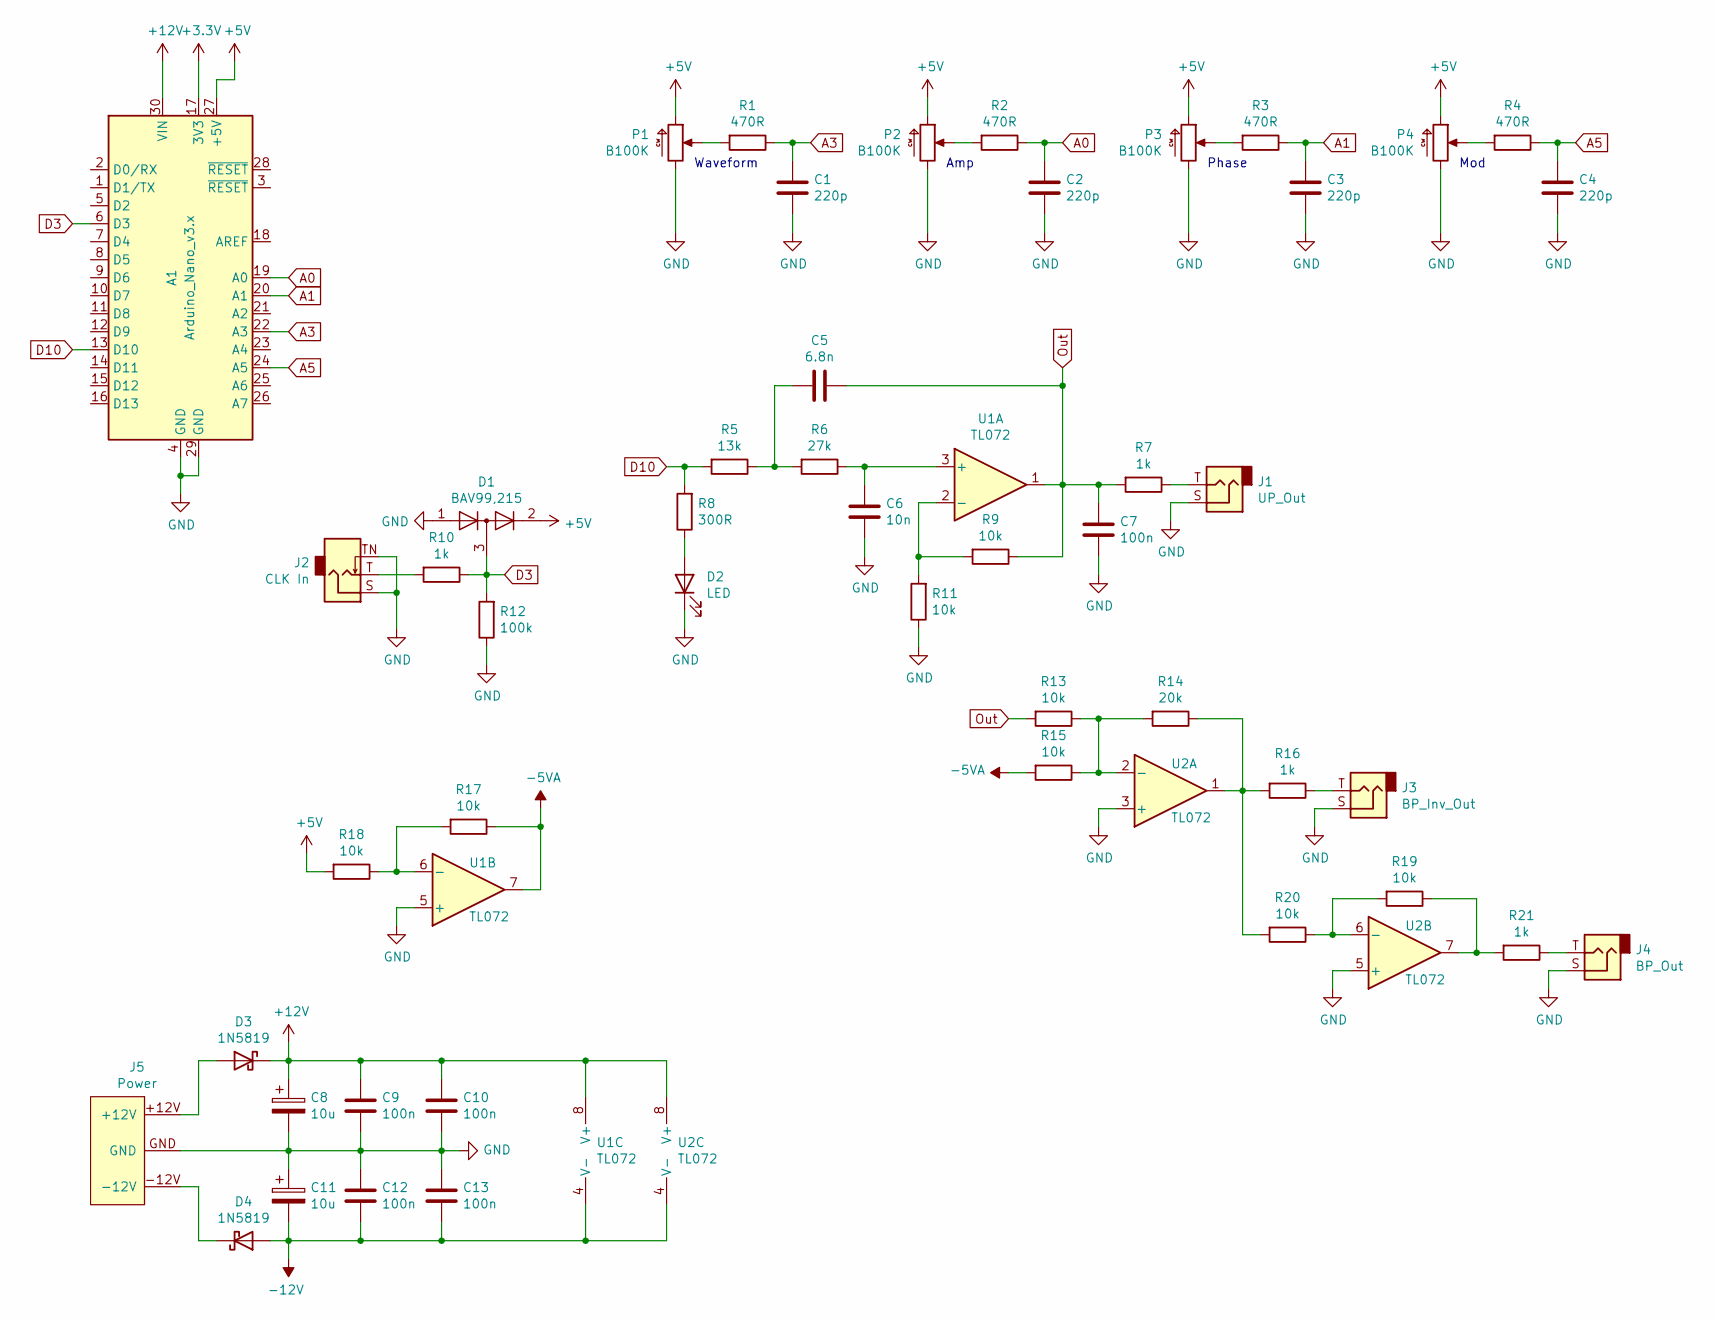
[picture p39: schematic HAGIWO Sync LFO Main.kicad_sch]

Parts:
A1: Arduino_Nano_v3.x; Arduino_Nano
C1, C2, C3, C4: 220p; C_0402_1005Metric; LCSC C1530
C5: 6.8n; C_0402_1005Metric; LCSC C1542
C6: 10n; C_0402_1005Metric; LCSC C15195
C7, C9, C10, C12, C13: 100n; C_0402_1005Metric; LCSC C1525
C8, C11: 10u; CP_EIA-3216-18_Kemet-A; LCSC C7171
D1: BAV99,215; SOT-23; LCSC C2500
D2: LED; LED_D3.0mm
D3, D4: 1N5819; D_SOD-323; LCSC C191023
J1: UP_Out; Jack_3.5mm_QingPu_WQP-PJ301M-12
J2: CLK In; Jack_3.5mm_QingPu_WQP-PJ301M-12
J3: BP_Inv_Out; Jack_3.5mm_QingPu_WQP-PJ301M-12
J4: BP_Out; Jack_3.5mm_QingPu_WQP-PJ301M-12
J5: Power; Power_2x5_Vertical
P1, P3, P4: B100K; Potentiometer_AlpsAlpine_RK09L1140_wo_Fix
P2: B100K; Potentiometer_AlpsAlpine_RK09L1140
R1, R2, R3, R4: 470R; R_0402_1005Metric; LCSC C25117
R5: 13k; R_0603_1608Metric; LCSC C22797
R6: 27k; R_0402_1005Metric; LCSC C25771
R7, R10, R16, R21: 1k; R_0402_1005Metric; LCSC C11702
R8: 300R; R_0402_1005Metric; LCSC C25102
R9, R11, R13, R15, R17, R18, R19, R20: 10k; R_0402_1005Metric; LCSC C25744
R12: 100k; R_0402_1005Metric; LCSC C25741
R14: 20k; R_0402_1005Metric; LCSC C25765
U1, U2: TL072; SOIC-8_3.9x4.9mm_P1.27mm; LCSC C6961

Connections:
+5V: A1.27 (+5V), D1.2 (A), P1.CW, P2.CW, P3.CW, P4.CW, R18.2
+12V: A1.30 (VIN), C8.1, C9.2, C10.2, D3.1 (K), U1.8 (V+), U2.8 (V+)
-5VA: R15.2, R17.1, U1.7
-12V: C11.2, C12.1, C13.1, D4.2 (A), U1.4 (V-), U2.4 (V-)
A0: A1.19 (A0), C2.1, R2.1
A1: A1.20 (A1), C3.1, R3.1
A3: A1.22 (A3), C1.1, R1.1
A5: A1.24 (A5), C4.1, R4.1
D3: A1.6 (D3), D1.3 (K), R10.1, R12.2
D10: A1.13 (D10), R5.2, R8.2
GND: A1.4 (GND), A1.29 (GND), C1.2, C2.2, C3.2, C4.2, C6.1, C7.1, C8.2, C9.1, C10.1, C11.1, C12.2, C13.2, D1.1 (K), D2.1 (K), J1.S, J2.S, J2.TN, J3.S, J4.S, J5.GND, P1.CCW, P2.CCW, P3.CCW, P4.CCW, R11.1, R12.1, U1.5 (+), U2.3 (+), U2.5 (+)
unnamed: C5.2, R5.1, R6.2
unnamed: C6.2, R6.1, U1.3 (+)
unnamed: D2.2 (A), R8.1
unnamed: D3.2 (A), J5.+12V
unnamed: D4.1 (K), J5.-12V
unnamed: J1.T, R7.1
unnamed: J2.T, R10.2
unnamed: J3.T, R16.1
unnamed: J4.T, R21.1
unnamed: P1.W, R1.2
unnamed: P2.W, R2.2
unnamed: P3.W, R3.2
unnamed: P4.W, R4.2
unnamed: R9.2, R11.2, U1.2 (-)
unnamed: R13.1, R14.2, R15.1, U2.2 (-)
unnamed: R14.1, R16.2, R20.2, U2.1
unnamed: R17.2, R18.1, U1.6 (-)
unnamed: R19.1, R21.2, U2.7
unnamed: R19.2, R20.1, U2.6 (-)
Out: C5.1, C7.2, R7.2, R9.1, R13.2, U1.1

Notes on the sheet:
Amp
Waveform
Phase
Mod

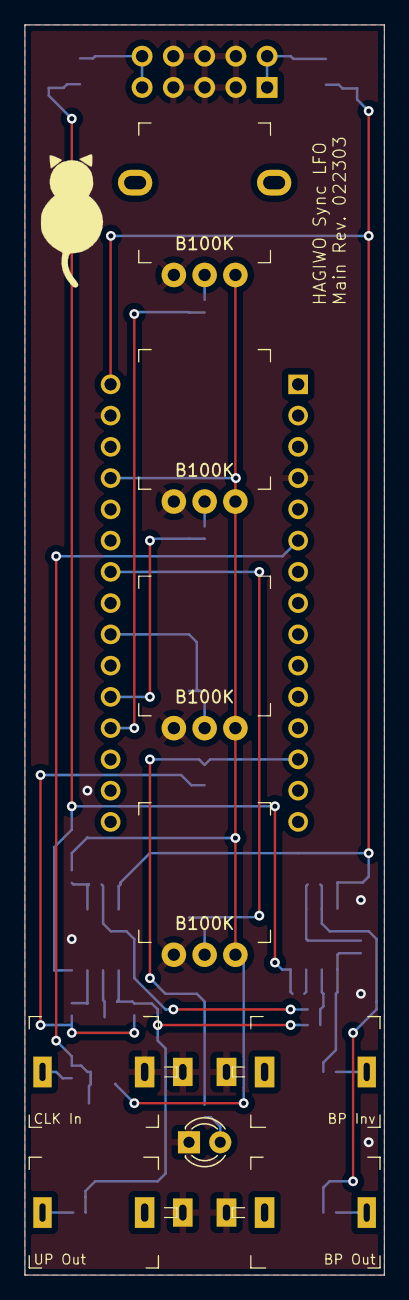
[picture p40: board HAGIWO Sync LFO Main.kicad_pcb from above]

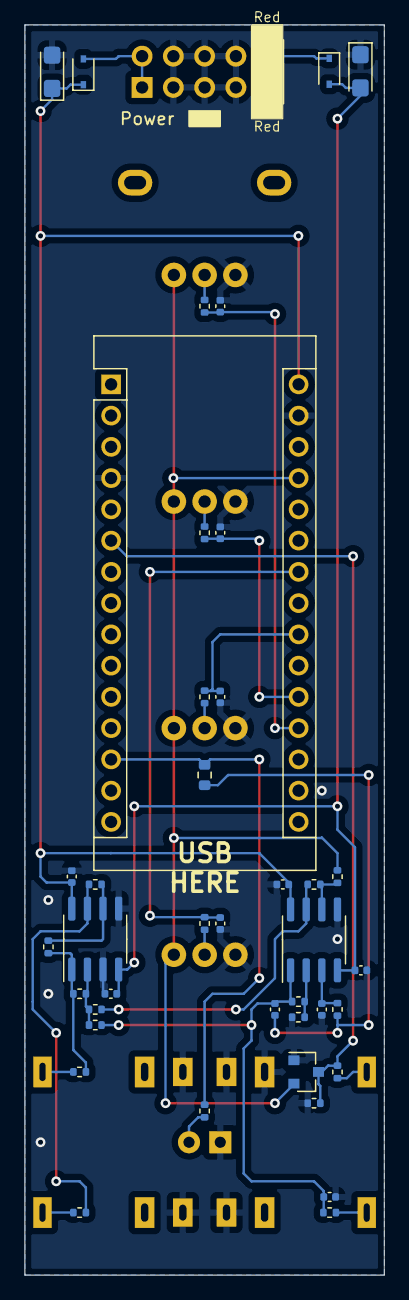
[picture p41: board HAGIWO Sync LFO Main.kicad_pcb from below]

Board: 2 copper layers, 29.2 x 101.6 mm, 50 parts (41 on the bottom side), 31 nets.

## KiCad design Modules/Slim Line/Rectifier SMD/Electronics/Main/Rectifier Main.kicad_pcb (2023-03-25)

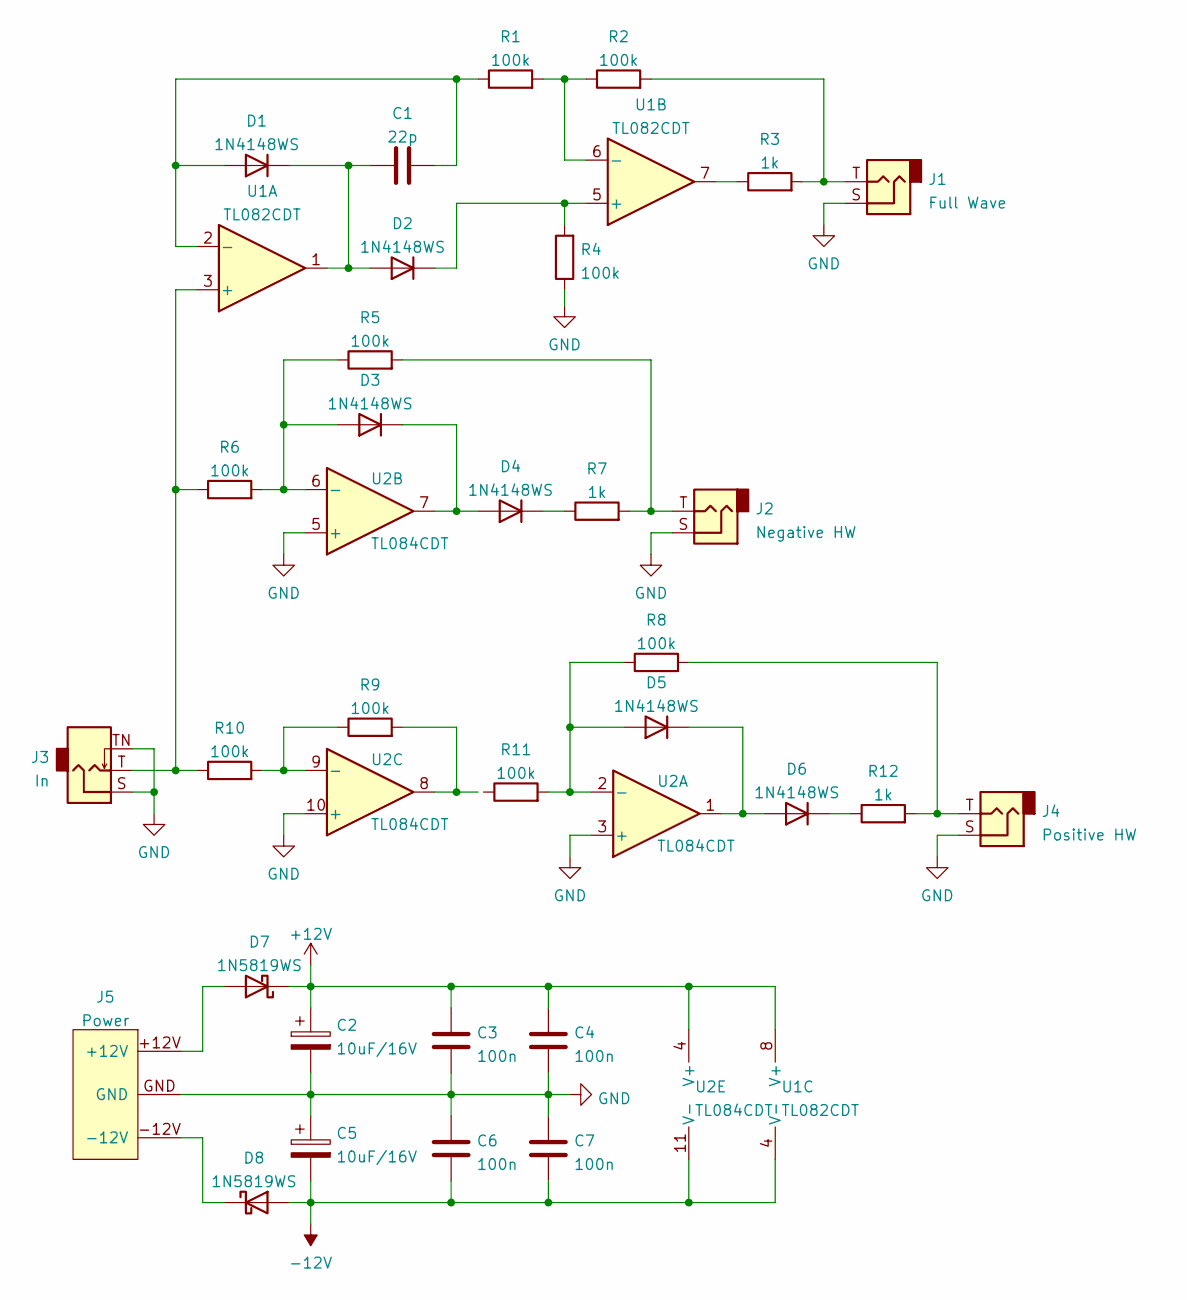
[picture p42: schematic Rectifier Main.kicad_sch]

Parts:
C1: 22p; C_0402_1005Metric; MPN C1555
C2, C5: 10uF/16V; CP_EIA-3216-18_Kemet-A; MPN C7171
C3, C4, C6, C7: 100n; C_0402_1005Metric; MPN C307331
D1, D2, D3, D4, D5, D6: 1N4148WS; D_SOD-323; MPN C2128
D7, D8: 1N5819WS; D_SOD-323; MPN C1884554
J1: Full Wave; Jack_3.5mm_QingPu_WQP-PJ324M
J2: Negative HW; Jack_3.5mm_QingPu_WQP-PJ324M
J3: In; Jack_3.5mm_QingPu_WQP-PJ324M
J4: Positive HW; Jack_3.5mm_QingPu_WQP-PJ324M
J5: Power; Power_2x8_Horizontal
R1, R2, R4, R5, R6, R8, R9, R10, R11: 100k; R_0603_1608Metric; MPN C335088
R3, R7, R12: 1k; R_1206_3216Metric; MPN C4410
U1: TL082CDT; SOIC-8_3.9x4.9mm_P1.27mm; MPN C13460
U2: TL084CDT; SOIC-14_3.9x8.7mm_P1.27mm; MPN C11130

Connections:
+12V: C2.1, C3.1, C4.2, D7.1 (K), U1.8 (V+), U2.4 (V+)
-12V: C5.2, C6.2, C7.1, D8.2 (A), U1.4 (V-), U2.11 (V-)
GND: C2.2, C3.2, C4.1, C5.1, C6.1, C7.2, J1.S, J2.S, J3.S, J3.TN, J4.S, J5.GND, R4.1, U2.3 (+), U2.5 (+), U2.10 (+)
unnamed: C1.1, D1.2 (A), R1.1, U1.2 (-)
unnamed: C1.2, D1.1 (K), D2.2 (A), U1.1
unnamed: D2.1 (K), R4.2, U1.5 (+)
unnamed: D3.1 (K), D4.2 (A), U2.7
unnamed: D3.2 (A), R5.1, R6.2, U2.6 (-)
unnamed: D4.1 (K), R7.1
unnamed: D5.1 (K), D6.2 (A), U2.1
unnamed: D5.2 (A), R8.1, R11.2, U2.2 (-)
unnamed: D6.1 (K), R12.1
unnamed: D7.2 (A), J5.+12V
unnamed: D8.1 (K), J5.-12V
unnamed: J1.T, R2.2, R3.2
unnamed: J2.T, R5.2, R7.2
unnamed: J3.T, R6.1, R10.1, U1.3 (+)
unnamed: J4.T, R8.2, R12.2
unnamed: R1.2, R2.1, U1.6 (-)
unnamed: R3.1, U1.7
unnamed: R9.1, R10.2, U2.9 (-)

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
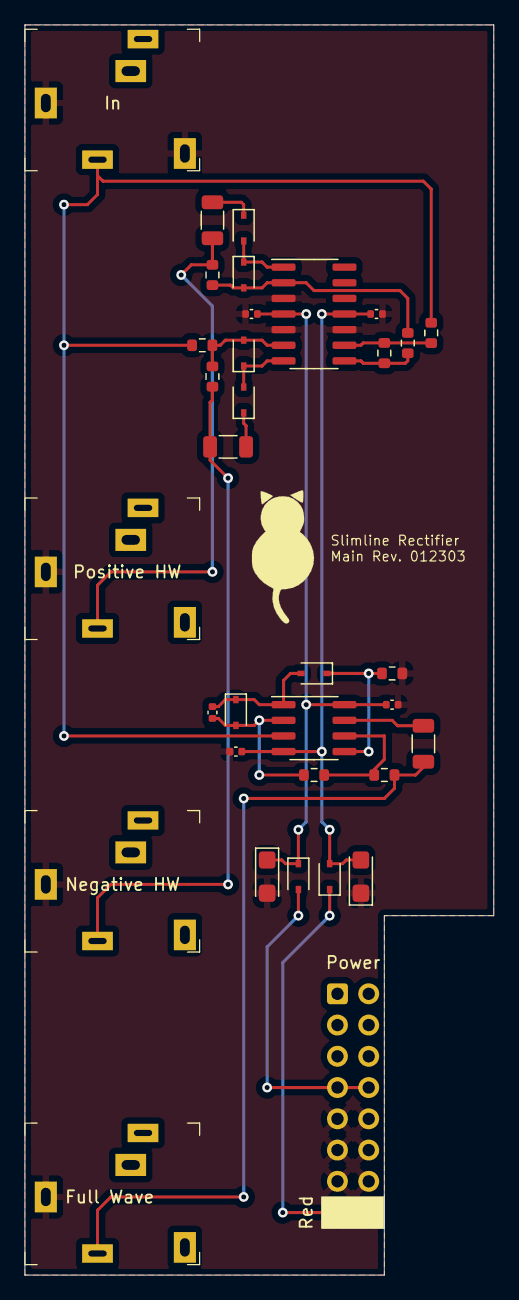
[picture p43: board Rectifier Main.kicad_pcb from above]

Board: 2 copper layers, 38.1 x 101.6 mm, 34 parts (0 on the bottom side), 22 nets.

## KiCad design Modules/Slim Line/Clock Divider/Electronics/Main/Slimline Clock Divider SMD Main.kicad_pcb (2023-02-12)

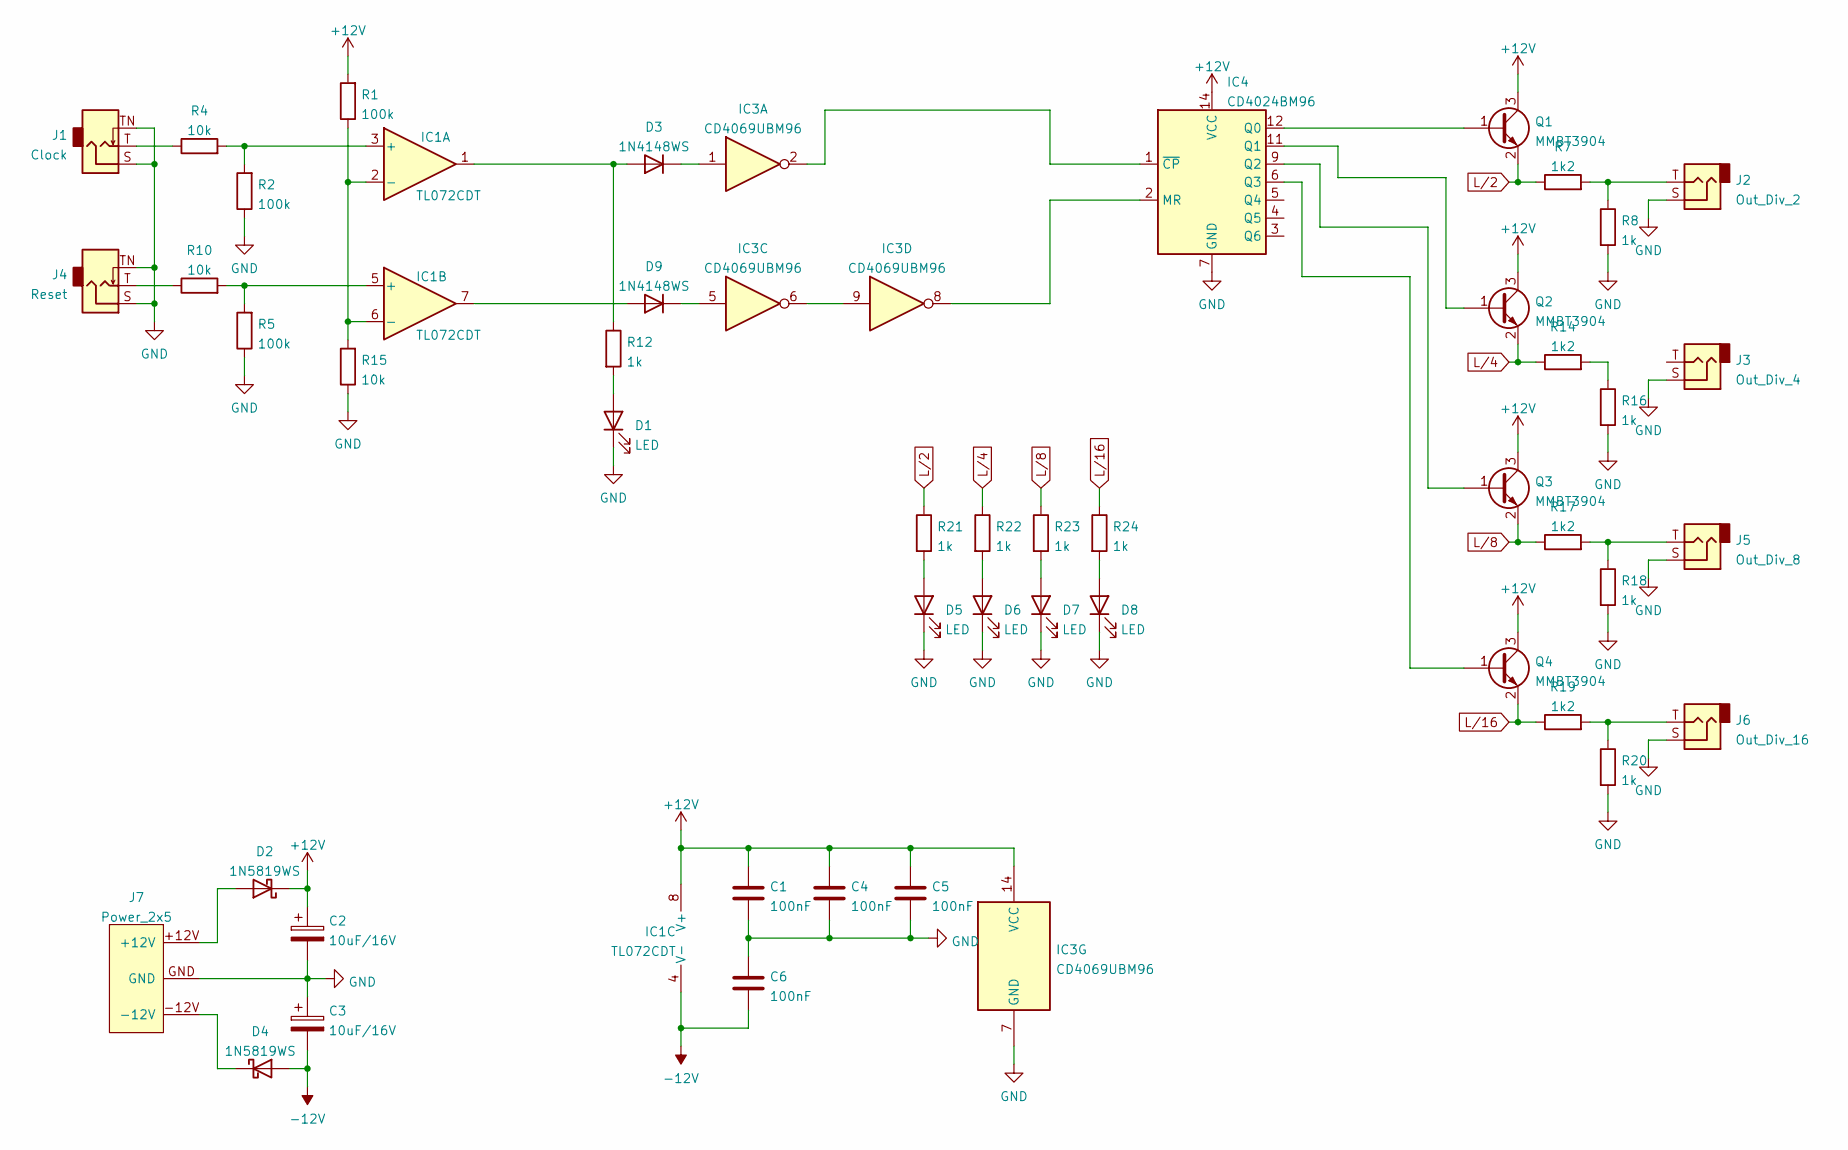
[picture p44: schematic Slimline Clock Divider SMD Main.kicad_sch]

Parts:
C1, C4, C5, C6: 100nF; C_0402_1005Metric; MPN C1525
C2, C3: 10uF/16V; CP_EIA-3216-18_Kemet-A; MPN C7171
D1, D5, D6, D7, D8: LED; LED_D3.0mm_Horizontal_O3.81mm_Z6.0mm
D2, D4: 1N5819WS; D_SOD-323; MPN C191023
D3, D9: 1N4148WS; D_SOD-323; MPN C2128
IC1: TL072CDT; SOIC-8_3.9x4.9mm_P1.27mm; MPN C6961
IC3: CD4069UBM96; SOIC-14_3.9x8.7mm_P1.27mm; MPN C93672
IC4: CD4024BM96; SOIC-14_3.9x8.7mm_P1.27mm; MPN C157535
J1: Clock; Jack_3.5mm_QingPu_WQP-PJ324M
J2: Out_Div_2; Jack_3.5mm_QingPu_WQP-PJ324M
J3: Out_Div_4; Jack_3.5mm_QingPu_WQP-PJ324M
J4: Reset; Jack_3.5mm_QingPu_WQP-PJ324M
J5: Out_Div_8; Jack_3.5mm_QingPu_WQP-PJ324M
J6: Out_Div_16; Jack_3.5mm_QingPu_WQP-PJ324M
J7: Power_2x5; Power_2x8_Horizontal
Q1, Q2, Q3, Q4: MMBT3904; SOT-23; MPN C20526
R1, R2, R5: 100k; R_0402_1005Metric; MPN C25741
R4, R10, R15: 10k; R_0402_1005Metric; MPN C25744
R7, R14, R17, R19: 1k2; R_0603_1608Metric; MPN C22765
R8, R12, R16, R18, R20, R21, R22, R23, R24: 1k; R_0603_1608Metric; MPN C21190

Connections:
+12V: C1.1, C2.1, C4.1, C5.1, D2.1 (K), IC1.8 (V+), IC3.14 (VCC), IC4.14 (VCC), Q1.3 (C), Q2.3 (C), Q3.3 (C), Q4.3 (C), R1.2
-12V: C3.2, C6.2, D4.2 (A), IC1.4 (V-)
GND: C1.2, C2.2, C3.1, C4.2, C5.2, C6.1, D1.1 (K), D5.1 (K), D6.1 (K), D7.1 (K), D8.1 (K), IC3.7 (GND), IC4.7 (GND), J1.S, J1.TN, J2.S, J3.S, J4.S, J4.TN, J5.S, J6.S, J7.GND, R2.1, R5.1, R8.2, R15.1, R16.2, R18.2, R20.2
L/2: Q1.2 (E), R7.1, R21.1
L/4: Q2.2 (E), R14.1, R22.1
L/8: Q3.2 (E), R17.1, R23.1
L/16: Q4.2 (E), R19.1, R24.1
unnamed: D1.2 (A), R12.2
unnamed: D2.2 (A), J7.+12V
unnamed: D4.1 (K), J7.-12V
unnamed: D5.2 (A), R21.2
unnamed: D6.2 (A), R22.2
unnamed: D7.2 (A), R23.2
unnamed: D8.2 (A), R24.2
unnamed: D3.2 (A), IC1.1, R12.1
unnamed: IC1.2 (-), IC1.6 (-), R1.1, R15.2
unnamed: IC1.3 (+), R2.2, R4.2
unnamed: IC1.5 (+), R5.2, R10.2
unnamed: D9.2 (A), IC1.7
unnamed: D3.1 (K), IC3.1
unnamed: IC3.2, IC4.1 (~CP)
unnamed: D9.1 (K), IC3.5
unnamed: IC3.6, IC3.9
unnamed: IC3.8, IC4.2 (MR)
unnamed: IC4.6 (Q3), Q4.1 (B)
unnamed: IC4.9 (Q2), Q3.1 (B)
unnamed: IC4.11 (Q1), Q2.1 (B)
unnamed: IC4.12 (Q0), Q1.1 (B)
unnamed: J1.T, R4.1
unnamed: J2.T, R7.2, R8.1
unnamed: J4.T, R10.1
unnamed: J5.T, R17.2, R18.1
unnamed: J6.T, R19.2, R20.1

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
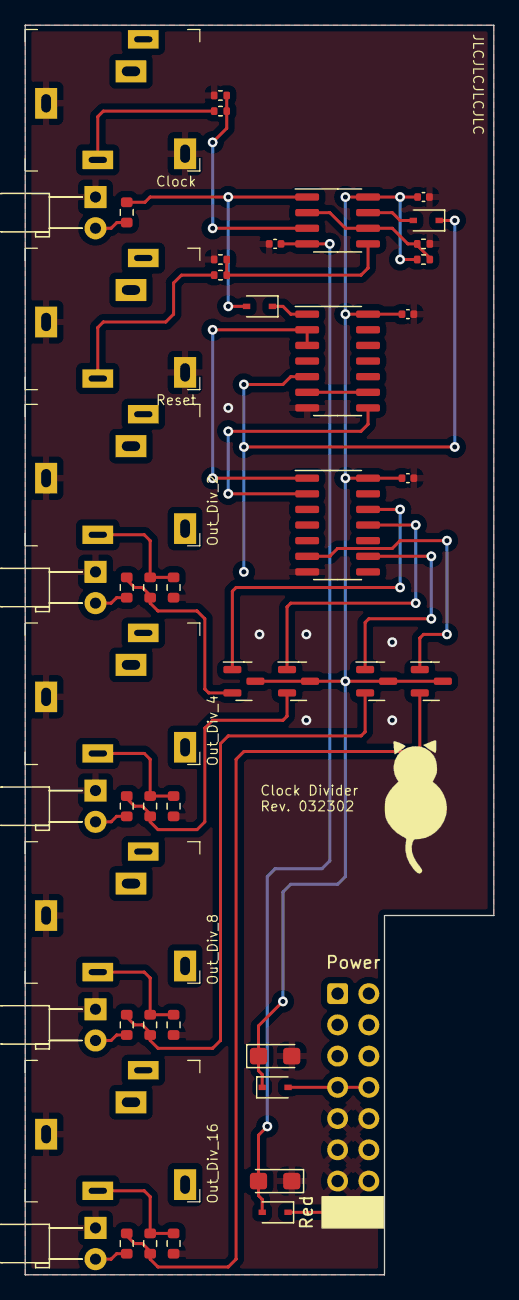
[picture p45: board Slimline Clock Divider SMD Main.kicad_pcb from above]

Board: 2 copper layers, 38.1 x 101.6 mm, 48 parts (0 on the bottom side), 34 nets.

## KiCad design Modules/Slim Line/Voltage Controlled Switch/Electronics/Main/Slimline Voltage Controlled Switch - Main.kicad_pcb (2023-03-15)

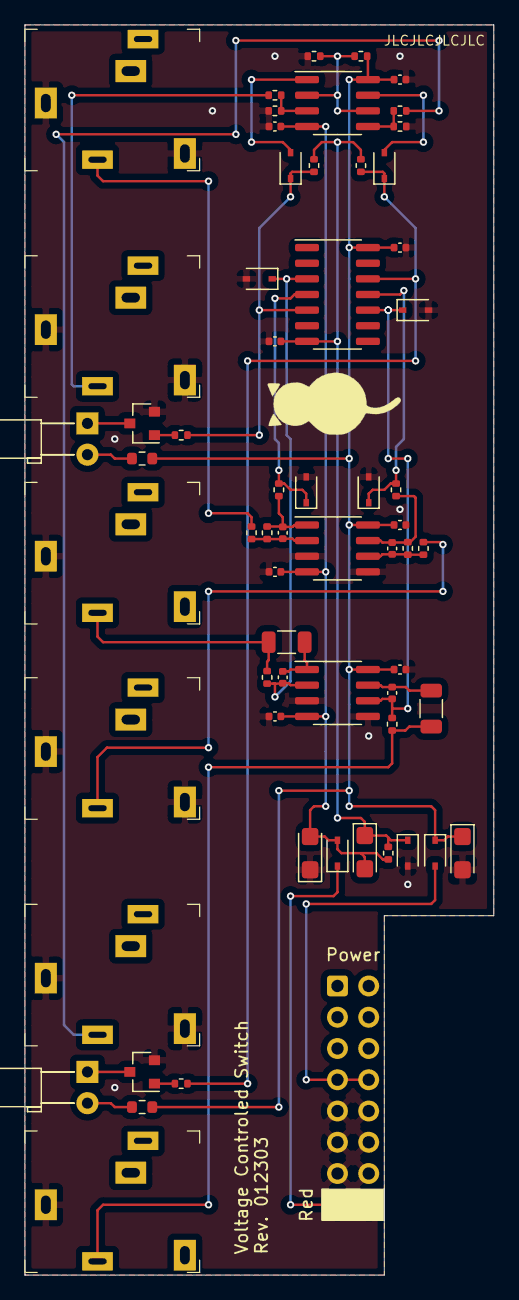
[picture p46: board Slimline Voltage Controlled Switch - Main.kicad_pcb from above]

Board: 2 copper layers, 38.1 x 101.6 mm, 62 parts (0 on the bottom side), 35 nets.

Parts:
C1, C2, C3, C4: 47p; C_0402_1005Metric
C5, C10, C12: 10µF; CP_EIA-3216-18_Kemet-A
C6, C7, C8, C9, C11, C13, C14, C15: 100n; C_0402_1005Metric
D1, D2, D3, D4, D6, D8, D10: 1N4148WS; D_SOD-323
D5, D7: LED; LED_D3.0mm_Horizontal_O3.81mm_Z6.0mm
D9, D11: 1N5817WS; D_SOD-323
J1: IN 1; Jack_3.5mm_QingPu_WQP-PJ324M
J2: OUT 1; Jack_3.5mm_QingPu_WQP-PJ324M
J3: IN 2; Jack_3.5mm_QingPu_WQP-PJ324M
J4: OUT 2; Jack_3.5mm_QingPu_WQP-PJ324M
J5: Switch 1; Jack_3.5mm_QingPu_WQP-PJ324M
J6: Switch 2; Jack_3.5mm_QingPu_WQP-PJ324M
J7: Power; Power_2x8_Horizontal
Q1, Q2: MMBT3904; SOT-23
R1, R2, R3, R4, R6, R7, R8, R9, R12, R14, R15, R16, R21, R22, R23: 100k; R_0402_1005Metric
R5, R10: 1k; R_1206_3216Metric
R11, R18: 1k; R_0603_1608Metric
R13, R17, R20: 10k; R_0402_1005Metric
R24: 1k; R_0402_1005Metric
U1, U3, U4: TL072CDT; SOIC-8_3.9x4.9mm_P1.27mm
U2: CD4066BM/TR; SOIC-14_3.9x8.7mm_P1.27mm

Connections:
+12V: C5.1, C6.2, C7.2, C8.2, C11.2, D9.1, R11.1, R12.2, R18.1, U1.8, U2.14, U3.8, U4.8
-12V: C10.2, C12.2, C13.1, C14.1, C15.1, D11.2, R17.1, U1.4, U3.4, U4.4
B1: D6.1, R14.1, R16.2, U2.5
B2: D8.1, R21.1, R23.2, U2.12
GND: C5.2, C6.1, C7.1, C8.1, C9.2, C11.1, C12.1, C13.2, C14.2, C15.2, D1.2, D2.2, D3.2, D4.2, D10.2, J1.S, J1.TN, J2.S, J3.S, J3.TN, J4.S, J5.S, J5.TN, J6.S, J6.TN, J7.GND, Q1.2, Q2.2, R15.1, R22.1, R24.2, U1.3, U1.5, U3.3, U3.5
unnamed: C1.1, R2.1, R4.2, U1.1
unnamed: C1.2, R2.2, R3.1, U1.2
unnamed: C2.1, R5.2, U3.1
unnamed: C2.2, D2.1, R1.2, U2.3, U3.2
unnamed: C3.1, R7.1, R9.2, U1.7
unnamed: C3.2, R7.2, R8.1, U1.6
unnamed: C4.1, R10.2, U3.7
unnamed: C4.2, D4.1, R6.2, U2.10, U3.6
unnamed: D1.1, R4.1, U2.4
unnamed: D3.1, R9.1, U2.11
unnamed: D5.1, Q1.3
unnamed: D5.2, R11.2
unnamed: D6.2, U4.1
unnamed: D7.1, Q2.3
unnamed: D7.2, R18.2
unnamed: D8.2, U4.7
unnamed: D9.2, J7.+12V
unnamed: D11.1, J7.-12V
unnamed: J1.T, R3.2
unnamed: J2.T, R1.1, R5.1
unnamed: J3.T, R8.2
unnamed: J4.T, R6.1, R10.1
unnamed: J5.T, R13.2
unnamed: J6.T, R20.2
unnamed: Q1.1, R14.2
unnamed: Q2.1, R21.2
unnamed: R12.1, R24.1, U4.2, U4.6
unnamed: R13.1, R15.2, U4.3
unnamed: R20.1, R22.2, U4.5
VEE: C9.1, C10.1, D10.1, R16.1, R17.2, R23.1, U2.7

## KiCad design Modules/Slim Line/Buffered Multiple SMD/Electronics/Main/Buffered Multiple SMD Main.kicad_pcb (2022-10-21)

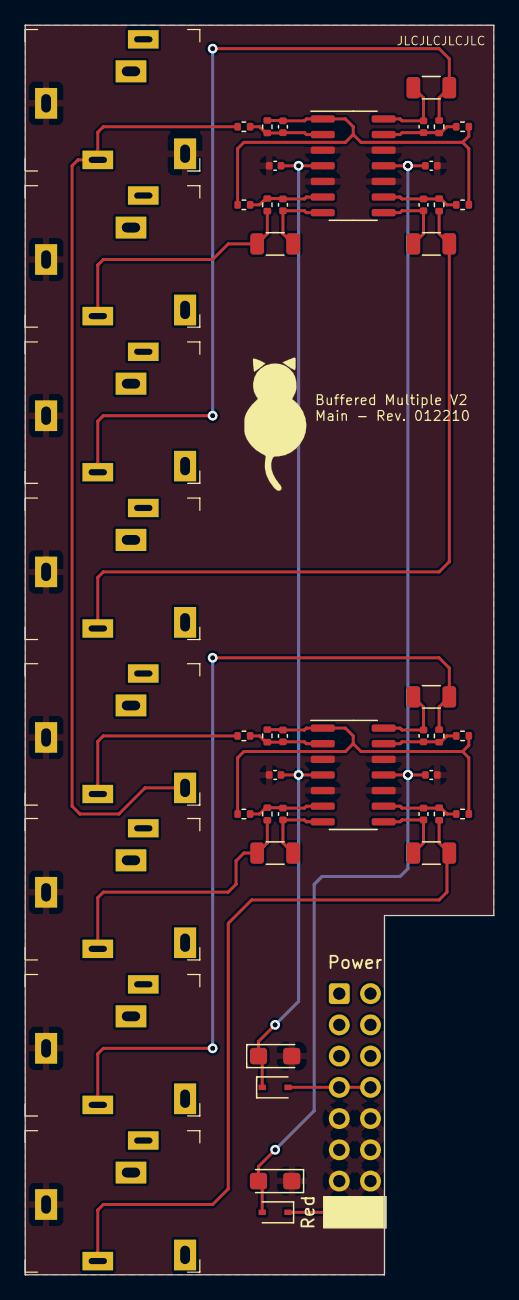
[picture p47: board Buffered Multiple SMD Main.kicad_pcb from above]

Board: 2 copper layers, 38.1 x 101.6 mm, 49 parts (0 on the bottom side), 29 nets.

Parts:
C1, C2, C3, C4, C5, C6, C7, C8: 10p; C_0402_1005Metric
C9, C12: 10u/16; CP_EIA-3216-18_Kemet-A
C10, C11, C13, C14: 100n; C_0402_1005Metric
D1, D2: 1N5819WS; D_SOD-323
J1: In 1; Jack_3.5mm_QingPu_WQP-PJ324M
J2: In 2; Jack_3.5mm_QingPu_WQP-PJ324M
J3: Out 1-1; Jack_3.5mm_QingPu_WQP-PJ324M
J4: Out 2-1; Jack_3.5mm_QingPu_WQP-PJ324M
J5: Out 1-2; Jack_3.5mm_QingPu_WQP-PJ324M
J6: Out 2-2; Jack_3.5mm_QingPu_WQP-PJ324M
J7: Out 1-3; Jack_3.5mm_QingPu_WQP-PJ324M
J8: Out 2-3; Jack_3.5mm_QingPu_WQP-PJ324M
J9: Power; Power_2x8_Horizontal
R1, R2, R3, R4, R5, R6, R7, R8, R11, R12, R13, R14, R17, R18, R19, R20: 100k; R_0402_1005Metric
R9, R10, R15, R16, R21, R22: 1k; R_1206_3216Metric
U1, U2: TL074CDT; SOIC-14_3.9x8.7mm_P1.27mm

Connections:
+12V: C9.1, C10.2, C11.2, D1.1 (K), U1.4 (V+), U2.4 (V+)
-12V: C12.2, C13.1, C14.1, D2.2 (A), U1.11 (V-), U2.11 (V-)
GND: C9.2, C10.1, C11.1, C12.1, C13.2, C14.2, J1.S, J1.TN, J2.S, J3.S, J4.S, J5.S, J6.S, J7.S, J8.S, J9.GND, U1.3 (+), U1.5 (+), U1.10 (+), U1.12 (+), U2.3 (+), U2.5 (+), U2.10 (+), U2.12 (+)
unnamed: D1.2 (A), J9.+12V
unnamed: D2.1 (K), J9.-12V
unnamed: J1.T, J2.TN, R5.1
unnamed: J2.T, R6.1
unnamed: J3.T, R1.2, R9.2
unnamed: J4.T, R2.2, R10.2
unnamed: J5.T, R11.2, R15.2
unnamed: J6.T, R12.2, R16.2
unnamed: J7.T, R17.2, R21.2
unnamed: J8.T, R18.2, R22.2
unnamed: C1.2, R3.2, R7.1, R13.1, R19.1, U1.1
unnamed: C1.1, R3.1, R5.2, U1.2 (-)
unnamed: C3.1, R1.1, R7.2, U1.6 (-)
unnamed: C3.2, R9.1, U1.7
unnamed: C7.2, R21.1, U1.8
unnamed: C7.1, R17.1, R19.2, U1.9 (-)
unnamed: C5.1, R11.1, R13.2, U1.13 (-)
unnamed: C5.2, R15.1, U1.14
unnamed: C2.2, R4.2, R8.1, R14.1, R20.1, U2.1
unnamed: C2.1, R4.1, R6.2, U2.2 (-)
unnamed: C4.1, R2.1, R8.2, U2.6 (-)
unnamed: C4.2, R10.1, U2.7
unnamed: C8.2, R22.1, U2.8
unnamed: C8.1, R18.1, R20.2, U2.9 (-)
unnamed: C6.1, R12.1, R14.2, U2.13 (-)
unnamed: C6.2, R16.1, U2.14

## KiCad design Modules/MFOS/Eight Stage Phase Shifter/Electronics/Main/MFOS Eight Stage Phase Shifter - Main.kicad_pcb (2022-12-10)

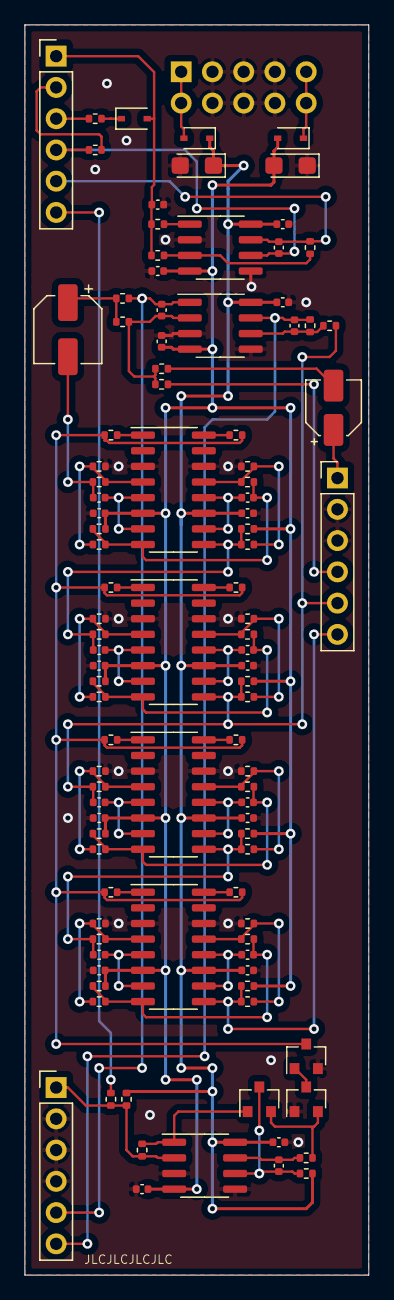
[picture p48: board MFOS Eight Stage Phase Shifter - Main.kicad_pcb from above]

Board: 2 copper layers, 27.9 x 101.6 mm, 104 parts (1 on the bottom side), 62 nets.

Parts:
C1, C2, C3, C4, C5, C6, C8, C9, C10, C11, C12, C13, C14, C15: 100n; C_0402_1005Metric
C7, C16: 10µF/16V; CP_EIA-3216-18_Kemet-A
C17: 220n; C_0402_1005Metric
C18: 1µF/25V; CP_Elec_4x5.4
C19: 100p; C_0402_1005Metric
C20: 10µF/25V; CP_Elec_5x5.4
C21, C22, C23, C24, C25, C26, C27, C28: 4.7nF; C_0402_1005Metric
C29: 1µF/25V; C_0402_1005Metric
C30, C31: 22pF; C_0402_1005Metric
D1: 1N4148WS; D_SOD-323
D2, D3: 1N5817; D_SOD-323
J1: LFO; PinHeader_1x06_P2.54mm_Vertical
J2: CV_OUT; PinHeader_1x06_P2.54mm_Vertical
J3: In; PinHeader_1x06_P2.54mm_Vertical
J6: Power; Power_2x5_Vertical
Q1, Q3: MMBT3904; SOT-23
Q2: MMBT3906; SOT-23
R2, R5, R9, R14, R19, R33, R36, R39, R41, R55, R58, R60, R61: 10k; R_0402_1005Metric
R3: 43k; R_0402_1005Metric
R7: 270k; R_0402_1005Metric
R8, R31, R34, R37, R40, R51, R52, R53, R54: 1k; R_0402_1005Metric
R11: 430k; R_0402_1005Metric
R12, R17, R20: 100k; R_0402_1005Metric
R13: 1M; R_0402_1005Metric
R22: 2k; R_0402_1005Metric
R23, R25, R27, R29, R32, R35, R38, R42, R43, R45, R47, R49, R56, R57, R59, R62: 30k; R_0402_1005Metric
R24, R26, R28, R30, R44, R46, R48, R50, R64: 20k; R_0402_1005Metric
R65: 33k; R_0402_1005Metric
U1, U2, U3: TL072; SOIC-8_3.9x4.9mm_P1.27mm
U4, U5, U6, U7: LM13700; SOIC-16_3.9x9.9mm_P1.27mm

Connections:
+12V: C1.1, C2.1, C3.1, C4.1, C6.1, C7.1, C8.1, C12.1, D2.1, R11.2, R13.2, U1.8, U2.8, U3.8, U4.11, U5.11, U6.11, U7.11
+12V_In: D2.2, J6.+12V
-12V: C5.2, C9.2, C10.2, C11.2, C13.2, C14.2, C15.2, C16.2, D3.2, R33.1, R36.1, R39.1, R41.1, R55.1, R58.1, R60.1, R61.1, U1.4, U2.4, U3.4, U4.6, U5.6, U6.6, U7.6
-12V_In: D3.1, J6.-12V
CV: J2.1, R11.1, R12.1, R22.2, U3.2
Depth_CW: C17.1, J1.5, R20.1, U2.7
Depth_W: J1.6, R12.2
FB: J3.4, R9.2
GND: C1.2, C2.2, C3.2, C4.2, C5.1, C6.2, C7.2, C8.2, C9.1, C10.1, C11.1, C12.2, C13.1, C14.1, C15.1, C16.1, C29.2, J2.2, J2.3, J2.4, J3.2, J3.3, J6.GND, Q2.2, Q3.1, R31.1, R34.1, R37.1, R40.1, R51.1, R52.1, R53.1, R54.1, U1.3, U1.5, U2.2, U2.5, U3.3, U3.5, U4.3, U4.14, U5.3, U5.14, U6.3, U6.14, U7.3, U7.14
Iabc: Q2.3, R24.2, R26.2, R28.2, R30.2, R44.2, R46.2, R48.2, R50.2
In: C18.1, J3.1
Mode_In: J1.3, R8.1
Mode_Out: C17.2, J1.4, R17.1, U2.6
unnamed: C18.2, R5.2
unnamed: C19.1, R14.2, U3.7
unnamed: C19.2, Q1.3, R13.1, U3.6
unnamed: C20.1, R19.1, R65.2
unnamed: C21.1, U4.5, U4.7
unnamed: C22.1, U4.10, U4.12
unnamed: C22.2, R25.2, R32.1, R33.2, U4.8
unnamed: C23.1, U5.5, U5.7
unnamed: C23.2, R27.2, R35.1, R36.2, U4.9
unnamed: C24.1, U5.10, U5.12
unnamed: C24.2, R29.2, R38.1, R39.2, U5.8
unnamed: C25.1, U6.5, U6.7
unnamed: C26.1, U6.10, U6.12
unnamed: C26.2, R45.2, R55.2, R56.1, U6.8
unnamed: C27.1, U7.5, U7.7
unnamed: C27.2, R47.2, R57.1, R58.2, U6.9
unnamed: C28.1, U7.10, U7.12
unnamed: C28.2, R49.2, R59.1, R60.2, U7.8
unnamed: C30.2, R5.1, R9.1, R19.2, U1.2
unnamed: C31.2, R2.1, R3.2, U1.6
unnamed: D1.1, R8.2
unnamed: Q1.1, R22.1, U3.1
unnamed: Q1.2, Q3.2, R14.1
unnamed: Q2.1, Q3.3
unnamed: R7.2, R20.2, U2.3
unnamed: R23.1, R31.2, R32.2, U4.4
unnamed: R24.1, U4.1
unnamed: R25.1, R34.2, R35.2, U4.13
unnamed: R26.1, U4.16
unnamed: R27.1, R37.2, R38.2, U5.4
unnamed: R28.1, U5.1
unnamed: R29.1, R40.2, R42.2, U5.13
unnamed: R30.1, U5.16
unnamed: R43.1, R51.2, R56.2, U6.4
unnamed: R44.1, U6.1
unnamed: R45.1, R52.2, R57.2, U6.13
unnamed: R46.1, U6.16
unnamed: R47.1, R53.2, R59.2, U7.4
unnamed: R48.1, U7.1
unnamed: R49.1, R54.2, R62.2, U7.13
unnamed: R50.1, U7.16
unnamed: R64.2, U2.1
OUT4: C25.2, J3.5, R2.2, R41.2, R42.1, R43.2, U5.9
OUT8: J3.6, R61.2, R62.1, U7.9
Out1: C30.1, J2.5, R65.1, U1.1
Out2: C31.1, J2.6, R3.1, U1.7
PSS_In: C20.2, C21.2, R23.2
Rate_CW: C29.1, D1.2, J1.1, R7.1, R64.1
Rate_W: J1.2, R17.2

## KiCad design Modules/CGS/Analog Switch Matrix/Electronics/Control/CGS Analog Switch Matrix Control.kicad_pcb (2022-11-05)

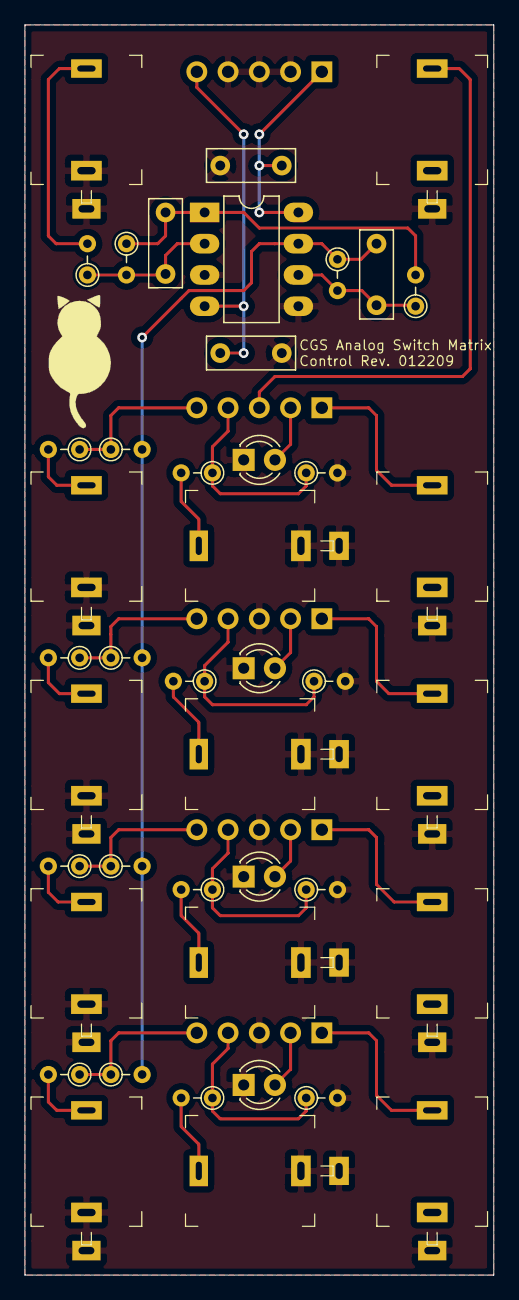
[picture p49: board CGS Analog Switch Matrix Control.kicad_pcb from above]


Board: 2 copper layers, 38.1 x 101.6 mm, 48 parts (5 on the bottom side), 33 nets.

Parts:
C1, C2: 100n; C_Rect_L7.0mm_W2.5mm_P5.00mm
C3, C4: 47p; C_Rect_L7.0mm_W2.5mm_P5.00mm
D1, D2, D3, D4: Green; LED_D3.0mm
J1: Common In; Jack_3.5mm_QingPu_WQP-PJ301M-12
J2: In 1; Jack_3.5mm_QingPu_WQP-PJ301M-12
J3: In 2; Jack_3.5mm_QingPu_WQP-PJ301M-12
J4: In 3; Jack_3.5mm_QingPu_WQP-PJ301M-12
J5: In 4; Jack_3.5mm_QingPu_WQP-PJ301M-12
J6: Control 1; Jack_3.5mm_QingPu_WQP-PJ301M-12
J7: Control 2; Jack_3.5mm_QingPu_WQP-PJ301M-12
J8: Control 3; Jack_3.5mm_QingPu_WQP-PJ301M-12
J9: Control 4; Jack_3.5mm_QingPu_WQP-PJ301M-12
J10: Common Out; Jack_3.5mm_QingPu_WQP-PJ301M-12
J11: Out 1; Jack_3.5mm_QingPu_WQP-PJ301M-12
J12: Out 2; Jack_3.5mm_QingPu_WQP-PJ301M-12
J13: Out 3; Jack_3.5mm_QingPu_WQP-PJ301M-12
J14: Out 4; Jack_3.5mm_QingPu_WQP-PJ301M-12
J15: 1_COM; PinSocket_1x05_P2.54mm_Vertical
J16: 2; PinSocket_1x05_P2.54mm_Vertical
J17: 3; PinSocket_1x05_P2.54mm_Vertical
J18: 4; PinSocket_1x05_P2.54mm_Vertical
J19: POWER; PinSocket_1x05_P2.54mm_Vertical
R1, R2, R3, R4, R5, R6, R7, R8, R13, R14, R15, R16, R17, R18, R19, R20: 100k; R_Axial_DIN0204_L3.6mm_D1.6mm_P2.54mm_Vertical
R9, R10, R11, R12: 10k; R_Axial_DIN0204_L3.6mm_D1.6mm_P2.54mm_Vertical
U1: TL072; DIP-8_W7.62mm_LongPads

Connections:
+12V: C1.2, J19.1, U1.8
-12V: C2.1, J19.5, U1.4
C1: J15.4, R9.1, R13.1
C2: J16.4, R10.1, R14.1
C3: J17.4, R11.1, R15.1
C4: J18.4, R12.1, R16.1
COMIN: C4.1, R1.2, R3.2, R5.2, R7.2, R20.1, U1.7
COMOUT: J10.T, J15.3
GND: C1.1, C2.2, D1.1, D2.1, D3.1, D4.1, J1.S, J1.TN, J2.S, J2.TN, J3.S, J3.TN, J4.S, J4.TN, J5.S, J5.TN, J6.S, J6.TN, J7.S, J7.TN, J8.S, J8.TN, J9.S, J9.TN, J10.S, J11.S, J12.S, J13.S, J14.S, J16.3, J17.3, J18.3, J19.2, J19.3, J19.4, R13.2, R14.2, R15.2, R16.2, U1.3, U1.5
I1: J15.5, R1.1, R2.1
I2: J16.5, R3.1, R4.1
I3: J17.5, R5.1, R6.1
I4: J18.5, R7.1, R8.1
L1: D1.2, J15.2
L2: D2.2, J16.2
L3: D3.2, J17.2
L4: D4.2, J18.2
unnamed: C3.1, R18.1, R19.2, U1.1
unnamed: C3.2, R17.1, R18.2, U1.2
unnamed: C4.2, R19.1, R20.2, U1.6
unnamed: J1.T, R17.2
unnamed: J2.T, R2.2
unnamed: J3.T, R4.2
unnamed: J4.T, R6.2
unnamed: J5.T, R8.2
unnamed: J6.T, R9.2
unnamed: J7.T, R10.2
unnamed: J8.T, R11.2
unnamed: J9.T, R12.2
O1: J11.T, J15.1
O2: J12.T, J16.1
O3: J13.T, J17.1
O4: J14.T, J18.1

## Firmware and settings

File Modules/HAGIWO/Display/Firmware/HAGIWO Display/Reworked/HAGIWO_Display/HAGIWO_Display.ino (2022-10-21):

#include <avr/io.h>//for fast PWM
#include "fix_fft.h"//spectrum analyze

//OLED display setting
#include <SPI.h>//for OLED display
#include <Adafruit_GFX.h>//for OLED display
#include <Adafruit_SSD1306.h> //for OLED display
#define SCREEN_WIDTH 128 // OLED display width, in pixels
#define SCREEN_HEIGHT 64 // OLED display height, in pixels
#define OLED_MOSI   9
#define OLED_CLK   10
#define OLED_DC    11
#define OLED_CS    12
#define OLED_RESET 13
Adafruit_SSD1306 display(SCREEN_WIDTH, SCREEN_HEIGHT,
                        OLED_MOSI, OLED_CLK, OLED_DC, OLED_RESET, OLED_CS);

//rotery encoder setting
#define  ENCODER_OPTIMIZE_INTERRUPTS //contermeasure of rotery encoder noise
#include <Encoder.h>
Encoder myEnc(2, 4);//rotery encoder digitalRead pin
float oldPosition  = -999;//rotery encoder counter
float newPosition = -999;


byte mode = 1;//1=low freq oscilo , 2=high freq oscilo , 3 = mid freq oscilo with external trig , 4 = spectrum analyze
byte old_mode = 1;//for initial setting when mode change.
byte param_select = 0;
byte param = 0;
byte param1 = 1;
bool param1_select = 0;
byte param2 = 1;
bool param2_select = 0;
int rfrs = 0;//display refresh rate

bool trig = 0;//external trig
bool old_trig = 0;//external trig , OFF -> ON detect
bool old_SW = 0;//push sw, OFF -> ON detect
bool SW = 0;//push sw

unsigned long trigTimer = 0;
unsigned long hideTimer = 0;//hide parameter count
bool hide = 0; //1=hide,0=not hide

char data[128], im[128] , cv[128]; //data and im are used for spectrum , cv is used for oscilo.

void setup() {
 //display setting
 display.begin(SSD1306_SWITCHCAPVCC);
 display.clearDisplay();
 display.setTextSize(0);
 display.setTextColor(WHITE);
 analogReference(DEFAULT);

 //pin mode setting
 pinMode(3, OUTPUT) ;//offset voltage
 pinMode(5, INPUT_PULLUP);//push sw
 pinMode(6, INPUT) ;//input is high impedance -> no active 2pole filter , output is active 2pole filter
 pinMode(7, INPUT); //external triger detect

 //fast pwm setting
 TCCR2B &= B11111000;
 TCCR2B |= B00000001;

 //fast ADC setting
 ADCSRA = ADCSRA & 0xf8;//fast ADC *8 speed
 ADCSRA = ADCSRA | 0x04;//fast ADC *8 speed
};

void loop() {
 old_SW = SW;
 old_mode = mode;

 SW = digitalRead(5);
 //select mode by push sw
 if (old_SW == 0 && SW == 1 && param_select == param) {
   param_select = 0;
   hideTimer = millis();
 }
 else if (old_SW == 0 && SW == 1 && param == 1) {
   param_select = param;
   hideTimer = millis();
 }
 else   if (old_SW == 0 && SW == 1 && param == 2) {
   param_select = param;
   hideTimer = millis();
 }
 else   if (old_SW == 0 && SW == 1 && param == 3) {
   param_select = param;
   hideTimer = millis();
 }
 mode = constrain(mode, 1, 4);
 param = constrain(param, 1, 3);

 //rotery encoder input
 newPosition = myEnc.read();
 if ( (newPosition - 3) / 4  > oldPosition / 4) {
   oldPosition = newPosition;
   hideTimer = millis();
   switch (param_select) {
     case 0:
       param ++;
       break;

     case 1:
       mode ++;
       break;

     case 2:
       param1 ++;
       break;

     case 3:
       param2 ++;
       break;
   }
 }

 else if ( (newPosition + 3) / 4  < oldPosition / 4 ) {
   oldPosition = newPosition;
   hideTimer = millis();
   switch (param_select) {
     case 0:
       param --;
       break;

     case 1:
       mode --;
       break;

     case 2:
       param1 --;
       break;

     case 3:
       param2 --;
       break;

   }
 }

 //initial settin when mode change.
 if (old_mode != mode) {
   switch (mode) {
     case 1:
       param1 = 2; //time
       param2 = 1; //offset
       pinMode(6, INPUT);//no active 2pole filter
       analogWrite(3, 0); //offset = 0V
       ADCSRA = ADCSRA & 0xf8;//fast ADC *8 speed
       ADCSRA = ADCSRA | 0x04;//fast ADC *8 speed
       break;

     case 2:
       param1 = 3; //time
       param2 = 3; //offset
       analogWrite(3, 127); //offset = 2.5V
       pinMode(6, INPUT);//no active 2pole filter
       ADCSRA = ADCSRA & 0xf8;//fast ADC *8 speed
       ADCSRA = ADCSRA | 0x04;//fast ADC *8 speed
       break;

     case 3:
       param1 = 2; //time
       analogWrite(3, 127); //offset = 2.5V
       pinMode(6, INPUT);//no active 2pole filter
       ADCSRA = ADCSRA & 0xf8;//fast ADC *8 speed
       ADCSRA = ADCSRA | 0x04;//fast ADC *8 speed
       break;

     case 4:
       param1 = 2; //high freq amp
       param2 = 3; //noise filter
       analogWrite(3, 127); //offset = 2.5V
       pinMode(6, OUTPUT);//active 2pole filter
       digitalWrite(6, LOW);//active 2pole filter
       ADCSRA = ADCSRA & 0xf8;//standard ADC speed
       ADCSRA = ADCSRA | 0x07;//standard ADC speed
       break;
   }
 }

 //OLED parameter hide while no operation
 if ( hideTimer + 5000 >= millis() ) {//
   hide = 1;
 }
 else {
   hide = 0;
 }

 //LFO mode--------------------------------------------------------------------------------------------
 if (mode == 1) {
   param = constrain(param, 1, 3);
   param1 = constrain(param1, 1, 8);
   param2 = constrain(param2, 1, 8);

   display.clearDisplay();

   //store data
   for (int i = 126 / (9 - param1); i >= 0; i--) {
     display.drawLine(127 - (i * (9 - param1)) , 63 - cv[i] - (param2 - 1) * 4, 127 - (i + 1) * (9 - param1) , 63 - cv[(i + 1 )] - (param2 - 1) * 4, WHITE); //right to left
     cv[i + 1] = cv[i];
     if (i == 0) {
       cv[0] = analogRead(0) / 16;
     }
   }

   //display
   if (hide == 1) {
     display.drawLine((param - 1) * 42, 8,   (param - 1) * 42 + 36, 8, WHITE);

     display.setTextColor(WHITE);
     if (param_select == 1) {
       display.setTextColor(BLACK, WHITE);
     }
     display.setCursor(0, 0);
     display.print("Mode:");
     display.setCursor(30, 0);
     display.print(mode);

     display.setTextColor(WHITE);
     if (param_select == 2) {
       display.setTextColor(BLACK, WHITE);
     }
     display.setCursor(42, 0);
     display.print("Time:");
     display.setCursor(72, 0);
     display.print(param1);

     display.setTextColor(WHITE);
     if (param_select == 3) {
       display.setTextColor(BLACK, WHITE);
     }
     display.setCursor(84, 0);
     display.print("Offs:");
     display.setCursor(114, 0);
     display.print(param2);
   }
 }

 //wave mode---------------------------------------------------------------------------------------------
 else if (mode == 2) {
   param = constrain(param, 1, 3);
   param1 = constrain(param1, 1, 8);
   param2 = constrain(param2, 1, 6);

   //store data
   if (param1 > 5) {//for mid frequency
     for (int i = 127 ; i >= 0; i--) {
       cv[i] = analogRead(0) / 16;
       delayMicroseconds((param1 - 5) * 20);
     }
     rfrs++;
     if (rfrs >= (param2 - 1) * 2) {
       rfrs = 0;
       display.clearDisplay();
       for (int i = 127 ; i >= 1; i--) {
         display.drawLine(127-i , 63 - cv[i - 1], 127-(i + 1)  , 63 - cv[(i)], WHITE);
       }
     }
   }

   else if (param1 <= 5) {//for high frequency
     for (int i = 127 / (6 - param1); i >= 0; i--) {
       cv[i] = analogRead(0) / 16;
     }
     rfrs++;
     if (rfrs >= (param2 - 1) * 2) {
       rfrs = 0;
       display.clearDisplay();
       for (int i = 127 / (6 - param1); i >= 1; i--) {
         display.drawLine(127-i * (6 - param1), 63 - cv[i - 1], 127-(i + 1) * (6 - param1)  , 63 - cv[(i)], WHITE);
       }
     }
   }

   //display
   if (hide == 1) {
     display.drawLine((param - 1) * 42, 8,   (param - 1) * 42 + 36, 8, WHITE);
     display.setTextColor(WHITE);
     if (param_select == 1) {
       display.setTextColor(BLACK, WHITE);
     }
     display.setCursor(0, 0);
     display.print("Mode:");
     display.setCursor(30, 0);
     display.print(mode);

     display.setTextColor(WHITE);
     if (param_select == 2) {
       display.setTextColor(BLACK, WHITE);
     }
     display.setCursor(42, 0);
     display.print("Time:");
     display.setCursor(72, 0);
     display.print(param1);

     display.setTextColor(WHITE);
     if (param_select == 3) {
       display.setTextColor(BLACK, WHITE);
     }
     display.setCursor(84, 0);
     display.print("Rfrs:");
     display.setCursor(114, 0);
     display.print(param2);
   }
 }

 //shot mode---------------------------------------------------------------------------------------------
 else if (mode == 3) {
   param = constrain(param, 1, 2);
   param1 = constrain(param1, 1, 4);
   old_trig = trig;
   trig = digitalRead(7);

   //    trig detect
   if (old_trig == 0 && trig == 1  ) {
     for (int i = 10 ; i <= 127; i++) {
       cv[i] = analogRead(0) / 16;
       delayMicroseconds(100000 * param1);//100000 is magic number
     }
     for (int i = 0 ; i < 10; i++) {
       cv[i] = 32;
     }
   }

   display.clearDisplay();
   for (int i = 126 ; i >= 1; i--) {
     display.drawLine(i , 63 - cv[i], (i + 1)  , 63 - cv[(i + 1)], WHITE);
   }

   //display
   if (hide == 1) {
     display.drawLine((param - 1) * 42, 8,   (param - 1) * 42 + 36, 8, WHITE);
     display.setTextColor(WHITE);
     if (param_select == 1) {
       display.setTextColor(BLACK, WHITE);
     }
     display.setCursor(0, 0);
     display.print("Mode:");
     display.setCursor(30, 0);
     display.print(mode);

     display.setTextColor(WHITE);
     if (param_select == 2) {
       display.setTextColor(BLACK, WHITE);
     }
     display.setCursor(42, 0);
     display.print("Time:");
     display.setCursor(72, 0);
     display.print(param1);
     display.setTextColor(WHITE);
     if (trig == 1) {
       display.setTextColor(BLACK, WHITE);
     }
     display.setCursor(84, 0);
     display.print("TRIG");
   }
 }

 //spectrum analyze mode---------------------------------------------------------------------------------------------
 else if (mode == 4) {
   param = constrain(param, 1, 3);
   param1 = constrain(param1, 1, 4);//high freq sence
   param2 = constrain(param2, 1, 8);//noise filter

   for (byte i = 0; i < 128; i++) {
     int spec = analogRead(0);
     data[i] = spec / 4 - 128;
     im[i] = 0;
   };
   fix_fft(data, im, 7, 0);
   display.clearDisplay();
   for (byte i = 0; i < 64; i++) {
     int level = sqrt(data[i] * data[i] + im[i] * im[i]);;
     if (level >= param2) {
       display.fillRect(i * 2, 63 - (level + i * (param1 - 1) / 8), 2, (level + i * (param1 - 1) / 8), WHITE); // i * (param1 - 1) / 8 is high freq amp
     }
   }

   //display
   if (hide == 1) {
     display.drawLine((param - 1) * 42, 8,   (param - 1) * 42 + 36, 8, WHITE);
     display.setTextColor(WHITE);
     if (param_select == 1) {
       display.setTextColor(BLACK, WHITE);
     }
     display.setCursor(0, 0);
     display.print("Mode:");
     display.setCursor(30, 0);
     display.print(mode);

     display.setTextColor(WHITE);
     if (param_select == 2) {
       display.setTextColor(BLACK, WHITE);
     }
     display.setCursor(42, 0);
     display.print("High:");
     display.setCursor(72, 0);
     display.print(param1);

     display.setTextColor(WHITE);
     if (param_select == 3) {
       display.setTextColor(BLACK, WHITE);
     }
     display.setCursor(84, 0);
     display.print("Filt:");
     display.setCursor(114, 0);
     display.print(param2);
   }
 }

 display.display();
};

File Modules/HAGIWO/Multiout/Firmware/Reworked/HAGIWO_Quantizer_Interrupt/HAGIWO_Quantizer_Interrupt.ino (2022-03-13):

#include <FlashAsEEPROM_SAMD.h>//flash memory use as eeprom
//Display setting
#include <Adafruit_SSD1306.h>
#include <Adafruit_GFX.h>
#include "Periphery.h"

Adafruit_SSD1306 display(I2C_OLED_SCREEN_WIDTH, I2C_OLED_SCREEN_HEIGHT, &Wire, -1);
#include <Wire.h>
//Rotery encoder setting
#include <EncoderButton.h>
EncoderButton myEnc(Pin_Enc_B, Pin_Enc_A, Pin_Enc_SW);//rotery encoder library setting
float oldPosition  = -999;//rotery encoder library setting
float newPosition = -999;//rotery encoder library setting
int i = 1;

bool SW = 0;
bool old_SW = 0;
bool CLK_in = 0;
bool old_CLK_in = 0;
byte mode = 0; //0=select,1=atk1,2=dcy1,3=atk2,4=dcy2

float AD_CH1, old_AD_CH1, AD_CH2, old_AD_CH2;
/////////////////////////////////////////////////////
// Change according to HAGIWO_MultiOut_Calibration //
/////////////////////////////////////////////////////
float AD_CH1_calib_m = 1.1020;//reduce resistance error
float AD_CH1_calib_b = -17.2500;//reduce resistance error
float AD_CH2_calib_m = 1.1037;//reduce resistance error
float AD_CH2_calib_b = -10.6562;//reduce resistance error
/////////////////////////////////////////////////////

int CV_in1, CV_in2;
float CV_out1, CV_out2, old_CV_out1, old_CV_out2;
long gate_timer1, gate_timer2; //EG curve progress speed
boolean Ch1_triggered, Ch2_triggered;
int cmp1, cmp2; //Detect closest note
int k = 0;

//envelope curve setting
int ad[200] = {//envelope table
 0,  30, 44, 59, 73, 87, 101,  116,  130,  143,  157,  170,  183,  195,  208,  220,  233,  245,  257,  267,  279,  290,  302,  313,  324,  335,  346,  355,  366,  376,  386,  397,  405,  415,  425,  434,  443,  452,  462,  470,  479,  488,  495,  504,  513,  520,  528,  536,  544,  552,  559,  567,  573,  581,  589,  595,  602,  609,  616,  622,  629,  635,  642,  648,  654,  660,  666,  672,  677,  683,  689,  695,  700,  706,  711,  717,  722,  726,  732,  736,  741,  746,  751,  756,  760,  765,  770,  774,  778,  783,  787,  791,  796,  799,  803,  808,  811,  815,  818,  823,  826,  830,  834,  837,  840,  845,  848,  851,  854,  858,  861,  864,  866,  869,  873,  876,  879,  881,  885,  887,  890,  893,  896,  898,  901,  903,  906,  909,  911,  913,  916,  918,  920,  923,  925,  927,  929,  931,  933,  936,  938,  940,  942,  944,  946,  948,  950,  952,  954,  955,  957,  960,  961,  963,  965,  966,  968,  969,  971,  973,  975,  976,  977,  979,  980,  981,  983,  984,  986,  988,  989,  990,  991,  993,  994,  995,  996,  997,  999,  1000, 1002, 1003, 1004, 1005, 1006, 1007, 1008, 1009, 1010, 1012, 1013, 1014, 1014, 1015, 1016, 1017, 1018, 1019, 1020, 1021
};
int ad1 = 0;//PWM DUTY reference
int ad2 = 0;//PWM DUTY reference
bool ad_trg1 = 0;
bool ad_trg2 = 0;
int atk1, atk2, dcy1, dcy2; //attack time,decay time
bool sync1, sync2; //0=sync with trig , 1=sync with note change
int sens1, sens2, oct1, oct2; //sens = AD input attn,amp.oct=octave shift

//CV setting
int cv_qnt_thr_buf1[62];//input quantize
int cv_qnt_thr_buf2[62];//input quantize
byte search_qnt = 0;
bool note1[12];//1=note valid,0=note invalid
bool note2[12];
byte note_str1, note_str11, note_str2, note_str22;

//display
bool disp_reflesh = 1;//0=not reflesh display , 1= reflesh display , countermeasure of display reflesh bussy
// ------------- Encoder Service Routines -------------------------
void onEncoder(EncoderButton& eb) {
  if (eb.increment()<=-1) {
    disp_reflesh = 1;
    switch (mode) {
      case 0:
        i--;
        if (i < 0) {
          i = 34;
        }
        break;
      case 1:
        atk1--;
        break;
      case 2:
        dcy1--;
        break;
      case 3:
        atk2--;
        break;
      case 4:
        dcy2--;
        break;
    }
  }
  else if (eb.increment()>=1) { //4 is resolution of encoder
    disp_reflesh = 1;
    switch (mode) {
      case 0:
        i++;
        if (i > 34) {
          i = 0;
        }
        break;
      case 1:
        atk1++;
        break;
      case 2:
        dcy1++;
        break;
      case 3:
        atk2++;
        break;
      case 4:
        dcy2++;
        break;
    }
  }
  atk1 = constrain(atk1, 1, 26);
  dcy1 = constrain(dcy1, 1, 26);
  atk2 = constrain(atk2, 1, 26);
  dcy2 = constrain(dcy2, 1, 26);
}

void onEncoderClick(EncoderButton& eb) {
  disp_reflesh = 1;
  if (i <= 11 && i >= 0 && mode == 0) {
    note1[i] = !note1[i];
  }
  else if (i >= 14 && i <= 25 && mode == 0) {
    note2[i - 14] = !note2[i - 14];
  }
  else if (i == 12 && mode == 0) { //CH1 atk setting
    mode = 1;//atk1 setting
  }
  else if (i == 12 && mode == 1) { //CH1 atk setting
    mode = 0;
  }
  else if (i == 13 && mode == 0) { //CH1 dcy setting
    mode = 2;//dcy1 setting
  }
  else if (i == 13 && mode == 2) { //CH1 dcy setting
    mode = 0;
  }
  else if (i == 26 && mode == 0) { //CH2 atk setting
    mode = 3;//atk2 setting
  }
  else if (i == 26 && mode == 3) { //CH2 atk setting
    mode = 0;
  }
  else if (i == 27 && mode == 0) { //CH2 dcy setting
    mode = 4;//dcy2 setting
  }
  else if (i == 27 && mode == 4) { //CH2 dcy setting
    mode = 0;
  }
  else if (i == 28) { //CH1 sync setting
    sync1 = !sync1;
  }
  else if (i == 29) { //CH2 sync setting
    sync2 = !sync2;
  }
  else if (i == 30) { //CH1 oct setting
    oct1++;
    if (oct1 > 4) {
      oct1 = 0;
    }
  }
  else if (i == 31) { //CH2 oct setting
    oct2++;
    if (oct2 > 4) {
      oct2 = 0;
    }
  }
  else if (i == 32) { //CH1 sens setting
    sens1++;
    if (sens1 > 4) {
      sens1 = 0;
    }
  }
  else if (i == 33) { //CH2 sens setting
    sens2++;
    if (sens2 > 4) {
      sens2 = 0;
    }
  }
  else if (i == 34) { //Save
    save();
  }

  //select note set
  k = 0;
  for (byte j = 0; j <= 62; j++) {
    if (note1[j % 12] == 1) {
      cv_qnt_thr_buf1[k] = 17 * j - 8;
      k++;
    }
  }
  k = 0;
  for (byte j = 0; j <= 62; j++) {
    if (note2[j % 12] == 1) {
      cv_qnt_thr_buf2[k] = 17 * j - 8;
      k++;
    }
  }
}

// ------------- Trigger Interrupt Service Routines ----------------------
void isrTrigger() {
  if (sync1 == 0) {
    ad1 = 0;
    ad_trg1 = 1;
    gate_timer1 = micros();
    if (atk1 == 1) {
      ad1 = 200; //no attack time
    }
    Ch1_triggered = true;
  }
  if (sync2 == 0) {
    ad2 = 0;
    ad_trg2 = 1;
    gate_timer2 = micros();
    if (atk2 == 1) {
      ad2 = 200; //no attack time
    }
    Ch2_triggered = true;
  }
}
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

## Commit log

2021-03-16 Update
    Commit
    [Front-B_Cu.gbr, Front-B_Mask.gbr, Front-B_SilkS.gbr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]
2021-06-12 4Ch Mixer added
    [4CH Mixer Front-B_Cu.gbr, 4CH Mixer Front-B_Mask.gbr, 4CH Mixer Front-B_SilkS.gbr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]
2021-06-12 S&H added
    [S&H Main-B_Cu.gbr, S&H Main-B_Mask.gbr, S&H Main-B_SilkS.gbr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]
2021-06-12 Clock Divider added
    [Clock Divider Control-B_Cu.gbr, Clock Divider Control-B_Mask.gbr, Clock Divider Control-B_SilkS.gbr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]
2021-06-12 Single VCA added
    [Slimline VCA Front-B_Cu.gbr, Slimline VCA Front-B_Mask.gbr, Slimline VCA Front-B_SilkS.gbr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]
2021-06-17 Steiner VCF added
    [Improved Steiner VCF Front.kicad_pcb, Improved Steiner VCF Front.sch, YuSynth Improved Steiner VCF Control.kicad_pcb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]
2021-06-18 STEP Updated
    [Buffered Multiple.STEP, Sample&Hold.STEP, Single VCA.STEP]
2021-07-12 Updat6e Steiner VCF
    [YuSynth Improved Steiner VCF Control-B_Cu.gbr, YuSynth Improved Steiner VCF Control-B_Mask.gbr, YuSynth Improved Steiner VCF Control-B_SilkS.gbr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]
2021-11-11 Update
    Update
    [Haraldswerk NGF-E LFO Front-B_Cu.gbr, Haraldswerk NGF-E LFO Front-B_Mask.gbr, Haraldswerk NGF-E LFO Front-B_SilkS.gbr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]
2022-01-24 HAGIWO 6Ch Trigger Sequencer
    [HAGIWO 6Ch Gate Sequencer Front.kicad_pcb, HAGIWO 6Ch Gate Sequencer Main BOM Rev. 012110.xlsx, HAGIWO 6Ch Gate Sequencer Main BOM Rev. 022201.xlsx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]
2022-01-24 Arduino VCO
    [Arduino VCO Main BOM Rev. 012201.xls, Arduino VCO Main.kicad_pcb, Arduino VCO Main.sch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]
2022-01-30 4Ch Sampler
    [HAGIWO 4Ch Sampler Front.kicad_pcb, HAGIWO 4Ch Sampler Main - BOM.xls, HAGIWO 4Ch Sampler.kicad_pcb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]
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2022-02-01 MFOS Update
    [MFOS Noise Cornucopia Control.kicad_pcb, MFOS Noise Cornucopia Control.sch, MFOS Noise Cornucopia Front.kicad_pcb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]
2022-02-02 Manual Gate
    [Manual Gate Control.kicad_pcb, Manual Gate Control.sch, Manual Gate Front.STEP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]
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2022-02-06 HAGIWO Sync LFO
    [HAGIWO Sync LFO Front.SLDPRT, HAGIWO Sync LFO Main - BOM.xls, HAGIWO Sync LFO Main.kicad_pcb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]
2022-02-06 HAGIWO Sync LFO Update
    [HAGIWO Sync LFO Front.DXF, HAGIWO Sync LFO Front.SLDPRT, HAGIWO Sync LFO Front.STEP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]
2022-02-07 CAD Update
    [HAGIWO Quantizer Frontpanel.DXF]
2022-02-07 Blind 3TE
    [Blindplatte 3TE Front.kicad_pcb]
2022-02-07 Update Blindplatte 3TE Front.kicad_pcb
    [Blindplatte 3TE Front.kicad_pcb]
2022-02-09 Noise Update
    [MFOS Noise Cornucopia Main 1.kicad_pcb, MFOS Noise Cornucopia Main 1.sch]
2022-02-10 Precision Adder added
    [Slim Precision Adder Main - BOM.xls, Slim Precision Adder Main.kicad_pcb, Slim Precision Adder Main.sch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]
2022-02-10 Balanced Modulator
    [YuSynth Dual Balanced Modulator Front.kicad_pcb, YuSynth Dual Balanced Modulator Main.kicad_pcb, YuSynth Dual Balanced Modulator Main.sch]
2022-02-11 KiCad 6 Update
    [HAGIWO Sync LFO Main.kicad_pcb, HAGIWO Sync LFO Main.kicad_sch]
2022-02-16 Envelope Follower Update
    [Envelope Follower Main.kicad_pcb, Envelope Follower Main.kicad_sch]
2022-02-18 Envelope Follower
    [Envelope Follower Front.DXF, Envelope Follower Front.STEP, Envelope Follower Front.kicad_pcb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]
2022-02-19 Major Update
    [HAGIWO Arduino VCO 2Op FM.kicad_pcb, HAGIWO Arduino VCO Additive.kicad_pcb, HAGIWO Arduino VCO Chord.kicad_pcb]
2022-02-19 Update Arduino VCO
    [Arduino VCO Main BOM Rev. 012201.xls, HAGIWO Arduino VCO 2Op FM Front.DXF, HAGIWO Arduino VCO 2Op FM.kicad_pcb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]
2022-02-19 Arduino VCO Update
    [Arduino VCO Main.kicad_pcb, Arduino VCO Main.sch]
2022-05-15 Slimline VCA
    [Slimline VCA Front.kicad_pcb, Slimline VCA Main.kicad_pcb, Slimline VCA Main.sch]
2022-05-15 SlimLine VCA Mechanics
    [Slimline VCA Front.DXF, Slimline VCA Front.STEP, Slimline VCA Modul.STEP]
2022-05-17 Vactrol VCF
    [Vactrol VCF - Front.kicad_pcb, Vactrol VCF - Main.kicad_pcb, Vactrol VCF - Main.sch]
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2022-06-12 Classic ADSR
    [Classic ADSR Front.DXF, Classic ADSR Front.kicad_pcb, Classic ADSR Main - BOM.xls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]
2022-09-18 Eight Stage Phase Shifter
    [Davies 1900H (violet).stp, MFOS Eight Stage Phase Shifter - Control.kicad_pcb, MFOS Eight Stage Phase Shifter - Control.sch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]
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2022-10-21 Buffered Multiple V2
    [Buffered Multiple V2 Main.kicad_pcb, Buffered Multiple V2 Main.kicad_sch, bom.csv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]
2022-11-05 Analog Switch Matrix
    [Buffered Multiple Front.DXF, Buffered Multiple Side.DXF, Buffered Multiple V2 Main BOM - HP.xls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]
2023-02-12 Slimline Clock Divider NG
    [Slimline Clock Divider Front.kicad_pcb, Slimline Clock Divider Main - BOM.csv, Slimline Clock Divider SMD Main.kicad_pcb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]
2023-03-15 Slimline Voltage Controlled Switch
    [BOM.xls, Slimline Clock Divider Front.kicad_pcb, Slimline Clock Divider Main - BOM.csv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]
2023-03-25 Update Sync LFO
    [HAGIWO Sync LFO Main.kicad_pcb, Rectifier Main - BOM.csv, Rectifier Main.kicad_pcb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]
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2023-03-25 readme fix
    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
2023-03-25 Add files via upload
    Move components for shrouded IDC header. Add Silkscreen for USB Connector
    [HAGIWO Sync LFO Main.kicad_pcb]
2023-03-26 Update SyncLFO
    [HAGIWO Sync LFO Main.kicad_pcb]
2023-05-08 Fix formatting and correct curve duty range.
    [MultiModeEnv_SyncLFO.ino]

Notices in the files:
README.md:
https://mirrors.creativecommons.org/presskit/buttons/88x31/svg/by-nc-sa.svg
